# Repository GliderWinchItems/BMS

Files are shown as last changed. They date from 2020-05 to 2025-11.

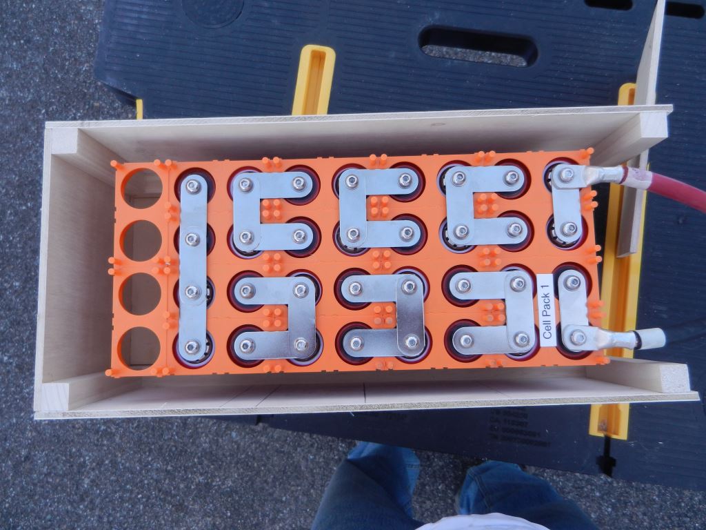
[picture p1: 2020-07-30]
docs/pictures/battery-module.JPG

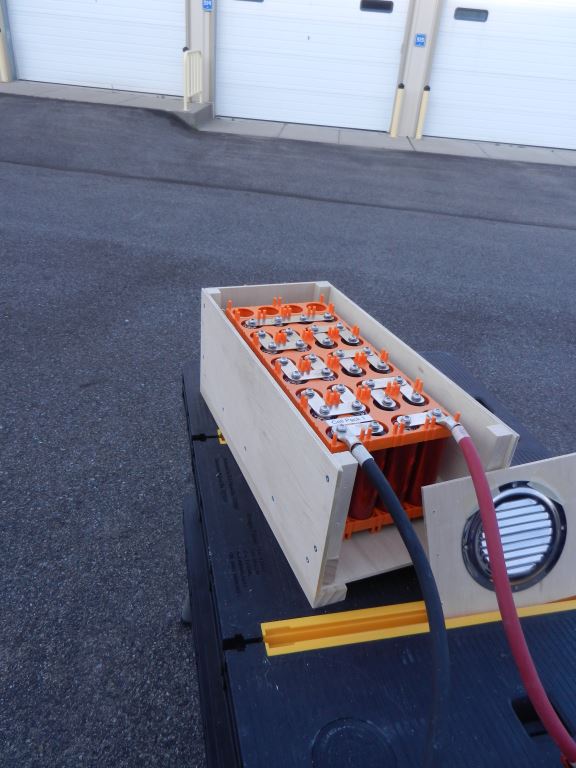
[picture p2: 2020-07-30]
docs/pictures/battery-module1.JPG

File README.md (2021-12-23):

# BMS
Battery Management System

This repo has directories for three BMS designs.

The original plan used a LTC6813-1 (18 cells), but when it came time to order the pcb, the part was no longer available. The TI BQ76952 (16 cells) was then found to be available in a few months so that design was completed.
The testing of the first prototype with the BQA76952 turned up some unexplained failures, plus additional BQ76952 parts would not be available for approximately one year. 

The ADBMS1818 chip became available and samples were to be shipped in a few weeks, and additional parts available from Mouser in several months. This gave rise to the second design. The delivery schedule changed  and it would be about one year for samples and additional parts. This gave rise to a design based on the MAX14952.
The designs differ mainly in the BMS chip. The same processor, STM32L431RxT6, is used and the features are  nearly identical in the three designs, e.g. the trickle charger, CAN, and fan interfaces, etc. Much of the documentation for the BQ76952 board applies to all three designs.

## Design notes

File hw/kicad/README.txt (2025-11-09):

#README.txt
# 11/08/25

# Step 1: Convert eagle v4 format to v6.5
#
# The files in kicad are the result of loading the original eagle v4 files into
# eagle 6.5, then saving the .sch & .brd files.

# Step 2: Convert eagle 6.5 format to kicad.
#
# The eagle 6.5 files are imported into kicad and the resulting kicad format files are 
# saved.

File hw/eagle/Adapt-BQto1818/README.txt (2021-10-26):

README.txt

10/25/2021

../GliderWinchItems/BMS/hw/eagle/Adapt-BQto1818/A18-BQ

This wires the ribbon/IDC for the 18 cell battery module
layout to the 16 cell keyed header on the bmsbmsBQ pcb.

A female 2x10 header (non-keyed) mounts on the left 
side on the bottom and mates with the BQ pcb.

A male 2x10 keyed header mounts on the top and
receives the ribbon IDC connector.

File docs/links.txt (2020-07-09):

http://vi.raptor.ebaydesc.com/ws/eBayISAPI.dll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

https://www.amazon.com/Pc-Accessories-Connectors-Sockets-10P-20cm-2PK/dp/B01DP13EDA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

http://www.interfacebus.com/Can_Bus_Connector_Pinout.html

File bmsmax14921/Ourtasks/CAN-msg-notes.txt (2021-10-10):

CAN-msg-notes.txt

A. EMC command msgs causing all modules to respond

byte 0:
  0 = send status (payload same as heartbeat)
  1 = capture cell voltage
  2 = send all cell voltages
  3 = send all temperatures
  ...

 B. Heartbeat

byte 0:  battery_status
byte 1:  fet_status
byte 2-4: cell discharge fets

C. Cell voltages

CAN ID maps to battery module

Payload carries cell voltates
byte [0]: command code
byte [1] Cell numbers
   bits[7:3]cell number 'n' (n > 0)
   bits[2:0]cell number payload readings (1-3)
     0 = no cell
byte [2-3] 16b voltage cell (n)
byte [4-5] 16b voltage cell (n+1)
byte [6-7] 16b voltage cell (n+2)

Cell voltage--
0 = not availble, open wire
65535 (0xFFFF) = reserved code for error, open wire, ...
0 < unsigned in 100 uV steps < 65535

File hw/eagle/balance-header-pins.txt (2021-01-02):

balance-header-pins.txt
01/01/2021

JP1 (Outside)
1  nc
2  C13
3  C9
4  C5
5  C1
6  C16
7  C12
8  C8
9  C4
10 C0

JP2 (Inside)
1  GND
2  C15
3  C11
4  C7
5  C8
6  nc
7  C14
8  C10
9  C6
10 C2

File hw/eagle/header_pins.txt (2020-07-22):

header_pin.txt

Header pins assignments for board pair:
repo GliderWinchItems/BMS
 directories 
hw/eagle/bmschgrR
hw/eagle/bmsbmsR

Battery cable
BSMCHGR: 2x10 KEYED TOPSIDE
 t = top group
 b = bottom group
pin func . color
01  GND    black
02  C2   t white
03  C4   t grey
04  C6   t purple
05  C8   t blue
06  C10  t green
07  C12  t yellow
08  C14  t orange
09  C16  t red
10  C18  t brown
11  C1   b black
12  C3   b white
13  C5   b grey
14  C7   b purple
15  C9   b blue
16  C11  b green
17  C13  b yellow
18  C15  b orange
19  C17  b red
20  gnd    brown

BETWEEN BOARDS: 1x30 top edge (of eagle layout view)
BMSCHGR: JP1  BOTTOMSIDE  BMSBMS: JP1 TOPSIDE
Pin #1 located a left side (of eagle layout view)
01  +15v isolated dc-dc output
02  +7v  15v switched to 7v
03  PA12 CAN TX
04  PA11 CAN RX
05  PA8  TIM1CH1   FAN FET gate drive 
06  PC11 I/O       LED1  
07  PC10 I/O       LED2
08  PB8  TIM4CH1   MCP1416-IN (HV fet driver input)
09  PA9  USART1-TX FTDI TX
10  PA10 USART1-RX FTDI RX
11  PC0  IN-10     15v divided for ADC
12  PC1  IN-11     Battery divided for ADC
13  C18   C'n' = LTC6813-1 cell voltage sense pin
14  S18   S'n' = LTC6813-1 cell discharge drive pin
15  C17
16  S17
17  C16
18  S16
19  C15
20  S15
21  C14
22  S14
23  C13
24  S13
25  C12
26  S12
27  C11
28  S11
29  C10
30  S10

BETWEEN BOARDS: 1x30 bottom edge (of eagle layout view)
BMSCHGR: JP2 BOTTOMSIDE   BMSBMS: JP2 TOPSIDE
Pin #1 located at left side (of eagle layout view)
01  C9
02  S9
03  C8
04  S8
05  C7
06  S7
07  C6
08  S6
09  C5
10  S5
11  C4
12  S4
13  C3
14  S3
15  C2
16  S2
17  C1
18  S1
19  GND
20  G5  Hall-effect signal ['G'n' = LTC6813-1 gpio pin (aux adc)]
21  G4  spare
22  G3  spare
23  G2  spare
24  VREG - 5V LTC6813 regulator output
25  +5v  - 5V LM78L05 bmsbms board output
26  MASTTER-RESET-PROC - Isolated CAN cable reset
27  PB1 - TIM3CH4  H11L1 opto-isolator 12v fan tach
28  PA14  JTCK SWDIO
29  PA13  JTMS SWCLK
30  GND

I2C bus (e.g. LCD or bi-color LED)
BMSBMS JP3: UNDERSIDE: 1X4
1 GND
2 +5V
3 PB11  I2C2-SDA
4 PB10  I2C2-SCL

Thermistors
BMSCHGR: JP10: 2x3 TOPSIDE
1 Thermistor #3:bms gpio G4
2 GND
3 Thermistor #2:bms gpio G3
4 GND
5 Thermistor #1:bms gpio G2
6 GND

FTDI connector
BMSCHGR: JP4: 1x6 TOPSIDE
1 GND
2 NC
3 NC
4 UART-RX
5 UART-TX
6 NC

SWD debugger
BMSCHGR: JP5: 1x4 TOPSIDE
1 GND
2 SWCLK
3 SWDIO
4 NC (3.3v)

FAN Drive
BMSCHGR: JP6: 1x2 TOPSIDE
1 Gnd (black)
2 +12v (red)
3 Drive signal (FET Q1 drain, w flyback diode) (blue)
4 Fan tach signal (yellow)

Hall-effect sensor
BMSCHGR: JP7: 1x3 TOPSIDE
1 GND
2 HE signal:bms gpio G5
3 +5v

Bi-color LED drive
BMSCHGR: JP8: 1x3 TOPSIDE
1 +5v
2 FET Q2 Drain resistor: LED1 (also on-board LED)
3 FET Q3 Drain resistor: LED2

External subboard possibility
BMSBMS: JP10: 1x4 BOTTOMSIDE
1 GND
2 PB2 PB0
3 PC4 (vis resistor) (ADC12-IN14)
4 5V

Pushbutton wake-up (closure pulls up)
BMSBMS: JP11
1 10K to gnd
2 VCC

External battery dump provision
BMSBMS: JP4
1 gnd
2 FET drain, ...
3 FET source, ...
4 +15V

THRU-HOLE SOLDER PADs (0.028" hole)
BMSBMS
U$1  LTC6813 GPIO6 
U$8  LTC6813 GPIO7
U$9  LTC6813 GPIO8
U$10 LTC6813 GPIO9

U$13 BATT-SELECT: P-FET source, select Battery tap
U$14 CL4: Battery tap - four cells
U$15 CL3: Battery tap - three cells

U$19 PB12 SPI2-NSS
U$20 PB13 SPI2-SCK
U$21 PB14 SPI2-MISO
U$22 PB15 SPI2-MOSI

U$23 PB7  I2C1 SDA:TIM4CH2

U$17 PB6 CAN2-TX:TIM4CH1
U$18 PB5 CAN2-RX:TIM3CH2

U$27 PC8  SDIO-D0:TIM3CH3
U$24 PC9  SDIO-D1:TIM3CH4:TIM8CH4
BOTTOM HEADER 7 PC10 LED2: SDIO-D2:USART3-TX
BOTTOM HEADER 6 PC11 LED1: SDIO-D3:USART3-RX:UART4-TX
U$25 PC12 SDIO-CK: UART5-TX
U$26 PD2  SDIO-CMD:UART5-RX

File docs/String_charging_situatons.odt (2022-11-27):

For the string there the following situations, but only if not cell on the string has fallen below the minimum voltage, e.g. 2.0v for LFE type cells--

1. Full power charging

Conditions:

- All modules have no cells at max voltage (e.g. after a launch).

2. Use dump, and heater to speed limited current charging

Conditions;

- One or more modules that have all cells at max

AND

- Modules that do not have all cells at max, have none of their cells at max.

3. Cell discharge resistors limit maximum charge rate.

Conditions:

- One of more modules that do not have all cells at max, have one or more cells at max.

Situation 1: Full power charging--

This would occur after a launch. Until the first cell reaches max the charger can be set for maximum power.

Situation 2: Charging limited by dump, heater, and discharge resistors

This situation could occur when a module is added to a string where the other modules are fully charged, and the new module has no cells at max. If charger can, averagely, charge at the rate set by the discharge current. The heater, dump resistor, and FET/discharge resistors serve to (averagely) dissipate the charger current in those modules at max. When one or more of the cells in the module being charged reaches max the situation changes to #3.

Situation 3: FET/discharge resistors limit charging currents

When a module has one or more cells at max, but not all cells are at max, then the charging, (trickle charger, plus string charger), averagely, has to be equal or less than the discharge current of the FET/discharge resistors.

The discharge resistors in '1818 boards are 30 ohms. The discharge FETs have a resistor of about 1/2 ohm. The ribbon cable & connector resistance adds something on the order 1/2-1 ohm. So with a threshold voltage of 3.65v and 31 ohms the current is about 117 ma. The string charger then has to be charging, averagely, at equal or less than 117 ma.

There is no need for having the string charger limited to the discharge resistor current since it is the average that matters. Within limits of course it doesn't matter what current the string charger supplies. One limit is that the duration of the charger on time between voltage checks times the current, i.e. charge added, doesn't push cells near the high limit too high which have been discharging with the discharge resistor. The duration gets onto the issue with ramping up of the charger, and how often the charging is turned off and cell readings taken. When a cell reaches the max voltage the discharge fet is turned on and the cell then begins dropping; when it hits a small increment below max, the discharge fet is turned off and the cell charges back up. There is a small voltage dithering around max until all cells have hit the max at which time the charging is complete, and a timed discharge is done to put the cells on the voltage plateau. Before all the cells hit max the cells still being brought up are dealing with current*time so it doesn't matter if the current is high and the duration short, or the current low and the duration long. If the string charger current is equal to the discharge resistor current the charging can be continuous, but that doesn't change the amount of time required to bring those cells up to max as the average charging level is still set by the discharge resistor current. The time * duration of the discharge resistors for the cells around max is what controls.

Dump resistor control

The dump resistor has two uses. One is to discharge the cells down to the plateau voltage once all the cells have reached max. The other is add discharge current to all the cells when situation #2 above is in effect. This allows a larger charger current to bring up a low module.

Heater resistor control

The resistor is has two uses. One is to heat the module when it is too cold. The other is to increase the charger current for situation #2.

Discharge resistor control

The cell FETs control the discharge resistors, and is the only way the charge on individual cells can be controlled. The FETs can turn on/off about 117 ma of cell discharge current. The trickle charger, for 3.65v and 18 cells, produces about 80 ma. The string charger can produce 0 – about 8a and can be set via CAN msgs.

Page 2 String Charging strategies

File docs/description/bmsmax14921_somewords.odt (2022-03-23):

Here is some commentary on the program strategy and details.

(These are more notes & thoughts than a coherent description.)

ADC usage

The BMS chip has one analog buffered output, so one ADC channel must measure all the cells, thermistors, and top-of-stack voltages. Other ADC channels are used to measure pcb points, e.g. the isolated dc-dc module voltage, processor internal voltage reference and internal temperature sensor.

The measurement speed for the BMS readout is critical since during the readout the voltages for the cells are being held by 1u capacitors and due to leakage the voltage has a “slump”. While the measurement speed for the other ADC channels is not as critical a large number of readings is needed for averaging the internal voltage reference. To deal with the timing issue the program strategy uses to two ADC modes. One for BMS readout and the other for the other ADC channels.

The cell readings are not needed continuously, and also there is a sampling time requirement. The flying capacitors are connected to the cell inputs with 3K resistors so there is a time constant issue with the recharging. The general plan is that the fastest rate for taking readings with be 16 per sec. This leaves 62.5 ms minus the readout duration for recharging.

ADCTask.c handles the control of the ADC readouts. After initialization the endless ‘for’ loop checks a FreeRTOS queue for a BMS readout request, without a wait. If the queue is empty it configures the ADC and DMA for reading the non-BMS ADC channels (if it is not already configured for this mode). The readout is started and a wait-for-notification is entered. When the ADC scans completes the DMA interrupt notifies the task, and the task calibrates and updates the channel readings and the ‘for’ loop repeats. This operation takes about 0.64 ms, which means any BMS readout has to wait no longer than 0.64 ms.

When a request for a BMS readout placed on the queue the ‘for’ loop checks a code on the request for the type of request.

If it the request is a ‘readbms’ the ADC is configured to read the single channel connected to the BMS buffer output. The readout requires a sequence. A command is sent; a delay for the command to “settle” e.g. the analog output buffer voltage, then an ADC conversion.

The commands are 24 bits (3 bytes) sent with SPI/DMA. The not-chip-select (/CS) line to the BMS controls the latching of the command bits to the BMS. When the SPI command transmission is started the line is low, enabling the BMS. When the SPI completes the sending of the 3 bytes the bits do not take effect until the /CS line is brought high. Bringing the /CS line high “latches” the bits into the BMS register. Following the latching of the new command, there is a settling time required for the mux to do the switching and the internal buffer to voltages to “settle.”

The first cycle of the sequence sets the /SMPL bit in the command which switches the flying capacitors from the cell inputs to ground reference. A delay of 50 us is required for this operation to “settle”. Therefore, the sequence is for ADCTask to begin the readout sequence by sending this first command. The SPI interrupt raises the /CS line thus latching the command and a 50 us time delay is set for the timer. The timer interrupt prepares the next command (cell #2), and starts the ADC conversions for the command currently latched in the BMS, i.e. cell #1.

Sequence--

1. ADCTask, upon completion of the non-BMS ADC channel reads checks the queue and finds a request.

2. The request is a pointer to a struct ADCREADREQ in the requester’s task. Assuming the request code, ‘reqcode’, is REQ_READBMS a call to ‘adcspi_readbms’ is made which starts the sequence. It returns when the sequence is complete.

3. Send command to switch flying caps to ground reference.

‘readbms’ starts sequence:

- reconfigure the ADC registers for a scan of 1, oversample 32, right shift 1.

- Set the state for TIM15 interrupt handling to ‘TIMSTATE_SMPL.

- Set the /CS line low to enable the MAX14921 (BMS) spi.

- Set TIM15 for a delay slightly longer than the sending of the SPI 3 bytes.

- Set the SPI DMA tx channel to send 3 bytes, and enable it, thus starting the sending of the SPI.

- Wait for a notification that the entire sequence has completed.

4. Start time delay for flying caps ground references.

TIM15 ‘TIMSTATE_SMPL’:

- Set the /CS line high, latching the command

- Set the TIM15 delay to ~50us for the flying caps to be brought to ground reference.

- Set the next TIM15 interrupt handling to TIMSTATE_2.

5. Start sending command for first cell selection.

TIM15 TIMSTATE_2:

- Set /CS low for sending next command

- Prepare command for selecting cell #1 (spiidx = 0)

- Set TIM15 delay for SPI delay.

- Set Sets the next TIM15 interrupt handling to TIMSTATE_3.

6. Settling time for first cell selection command

TIM15 TIMSTATE_3:

- Set /CS high to latch cell #1 selection selection

- Set TIM15 delay for 5 us settling time.

- Set TIM15 interrupt handling to TIMSTATE_N.

7. Start conversions, and sending of next cell selection.

TIM15 TIMSTATE_N:

- Set /CS low for to enable sending next SPI

- Start ADC conversions

- Start SPI sending next command.

- No timer setting. Wait for ADC interrupt.

8. ADC interrupt

- Set /CS high latching next command sent-and-waiting.

- Store ADC result in ‘raw’ array using ‘adcidx’ index.

- Advance index and

- if equal 20

- - notify task sequence completed

- - Set TIM15 interrupt handling to TIMSTATE_IDLE

– if less the 20,

- - if equal 19

Set TIM15 delay to 60us.

else

Set TIM15 delay to 5 us.

- Set TIM15 interrupt handling to TIMSTATE_N.

9. Step 7 above repeats until the ADC interrupt stores the last, top-of-stack, 20th reading. Note that a command is sent with the spiidx equal 20, is is the 21st command. This command sets the /SMPL bit to zero. The discharge FET bits are set according to the request.

Request queue pointer points to the following struct with codes--

/* Request Codes for ADCTask services. */

#define REQ_BOGUS 0 // Trap mistakes

#define REQ_READBMS 1 // Read MAX1921 cells, thermistor, Top-of-stack

#define REQ_CALIB 2 // Execute a self-calib (MAX14921 Aout offset) cycle

#define REQ_OPENCELL 3 // Do an open cell wire test

#define REQ_LOWPOWER 4 // Place MAX14921 into low power mode.

#define REQ_SETFETS 5 // Set cell discharge FETs

/* Queue is a pointer to the following for requesting a "service". */

struct ADCREADREQ

{

osThreadId taskhandle; // Requesting task's handle

BaseType_t tasknote; // Requesting task's notification bit

float* taskdata; // Requesting task's pointer to buffer to receive data

uint16_t cellbits; // Depends on command: FET to set; Open cell wires

uint8_t updn; // see above 'struct ADCSPIALL'

uint8_t reqcode; // Code for service requested

uint8_t noverlap; // see above

uint8_t readbmsfets;// Code for handline discharge fets during read:

// 0 = clear fets; fets remain clear after read sequence

// 1 = fet setting remains in place during read sequence

// 2 = new fet setting (from cellbits) applied after read sequence

// 3 = save fet setting; clear for read; restore after read

};

After placing the request on the queue it can use a wait for notification that the request has been completed.

‘tasknote’ supplies the word/bit to identify who made the notification.

‘taskdata’ supplies a pointer to an array of floats to receive the 20 BMS readings (16 cells, three thermistors, one top-of-stack).

‘cellbits’ (uint16_t) has bits to for setting each of the discharge fets. 1 sets turns the fet on.

‘updn’ controls the cell readout sequence. 0 = cell #16 read first, 1 = cell #1 read first. High numbered cells have higher leakage than lower cells so reading the high cells first is supposed to reduce the effect of leakage (“slump”) discharging the capacitors while readings are being made.

‘reqcode’ code for BMS function to be executed.

‘noverlap’ the spi is ovelapped with the adc conversions. Not overlapping might reduce ADC noise but at the expense of a longer readout duration and greater slump. Currently (3/17/2022) this is not implemented.

‘readbmsfets’ : Options for setting/resetting the discharge fets before & after the readbms sequence. Most likely the readbms sequence will be done with the fets (and chargers) off. Readout with a fet on is one scheme for detecting an open cell wire than using the DIAG 10 ua discharge approach.

The thermistor and top-of-stack readouts do not involve measuring voltages on capacitors so the issue of “slump” error is not involved. The time delay for settling of the analog output buffer is still present, and the top-of-stack requires a 60 us delay.

The timer interrupt handler prepares the command to be sent by the SPI. A ‘switch’ based on an index is used to deal with cells, thermistors, top-of-stack, and end of requested readout. The commands for selecting the individual cells is done via a table lookup. An option in the queued readout request can select for the cell readouts to be high-to-low cell numbers, or low-to-high. The high numbered cells are supposed to have a higher leakage current, hence faster slump rate, than the low cells, and the datasheet recommends high-to-low. The option allows the reverse readout so that comparisons can be made. (Similarly, the option for overlap/not-overlap can be used to test out which provides the best accuracy.)

The ADC conversions are done using the over-sampling provision in the STM32L431. A channel is repeatedly converted and the result added to a register. At the end of the set number of conversions the register with the accumulated readings is automatically right shifted according a setting in a configuration register. The selection for the ADC channels scans is an oversampling of 32 followed by a right shift of 1, and the BMS readout is 16 with no right shift.

The ADC oversampling is set so that it takes longer than the duration required for the SPI sending of the 24b command plus settle-duration.

It is important that the interrupt priority of the TIM15, and ADC all be at the same level. Since the interrupt handling of these two interact, having the same priority avoids an intractable situation whereby one a higher priority interrupt occurs in the middle of the execution of the lower priority interrupt.

TIM15 shares the interrupt vector with TIM1. TIM1 is used for the trickle charger PWM control, along with the two comparators that break TIM1 to keep currents and voltages within limits. No interrupts are used with TIM1.

TIM2 is used with the FanTask, and the fan control. It is a 32b timer, however the PWM frame rate is set for 25 Khz so it is not useful for using one of its timers for the BMS time delays. This leaves TIM15 for the time delays, however it is only 16b. For most of the time delays that is sufficient, i.e. at 16 MHz system clock the turnover duration is 4.096 ms. However, the the self-calibration command for the BMS requires approximately 8 ms. To handle this single long delay situation, the time delay for completion of the self-calibration command is simply two output capture turnovers, starting at the time the SPI command completed (and the /CS line raised to latch the command).

Yet to be tested (3/11/202) the BMS commands for readout require 5 us following the latching of the command. From the instant of raising of the /CS line to the start of the TIM15 output capture there are instructions being executed, so adding 5 us of timer ticks (i.e. at 16 Mhz system clock, 16 machine cycles per us) will result in a somewhat longer timer duration from the time the i/o line goes from low-to-high and until timer interrupt takes place, and executes up to the point where the ADC conversion start. The amount of time will be short—maybe less than 2 us?--so that is not significant, i.e. for 16 cells, 32 us extending of a possible 316.8 us minimum. The datasheet mentions that with 1 u capacitors a readout of less than 1 ms for less than 1 mv slump error.

Ideal for timing the short (5 us) delay would be for the rising edge of the /CS i/o pin to trigger a timer input capture. The subsequent interrupt processing could check that time of capture plus 5 us and use that for adding any additional delay. If the delay had already expired the next timer step could proceed.

Next best would be to have the instruction following the one setting the /CS i/o pin trigger an input capture. That would add a few machine cycles. One problem is that if the rtos timer interrupt, which is the only higher priority interrupt, interrupted it would add more delay. This could be overcome by reading the system time before and after, but adds to the complication.

(3/20/2022)

Timing. Using DTWTIME to save the system timer the number of machine cycles was measured between various points. Adding 16 to the current TIM15 counter (CNT) resulted in about 90 cycles from ADC interrupt routine entry and the TIM15 switch statement. With the oversampling set to 32 (right shift 1) the sixteen cell measurements was taking about 500 machine cycles. The overall measurement (cells, thermistors, top-of-stack) was 0.8 ms. With the oversampling set to 64 (right shift 2) it was 1.3 ms.

CanCommTask.c is the primary source of requests for a BMS readout. This task checks on incoming CAN msgs and when there is a request for a readout, e.g. the EMC, it places a pointer to a struct ADCREADREQ on the queue for ADCTask. The struct holds the options, pointers, notification word, etc. ADCTask executes the request and notifies the task making the request (using the data in the struct). With the new data CanCommTask sends the CAN msgs with the readings. The rate for taking readings is therefore under control of the EMC, or “whoever” sends the CAN msg for the request.

When there are no CAN msgs making a request, the endless ‘for’ loop in CanCommTask times out; makes readout request, and sends out the results as a heartbeat. The heartbeat rate is determined by the timeout count, which is a parameter.

Another readout requester is likely to be ‘main.c’ where ‘defaultTask’ makes a request for monitoring/debugging.

The ‘readbms’ turns off the discharge FETs if they were on since the first step of setting the /SMPL bit high (set flying caps to ground reference) has the cell discharge FET bits off. Maybe this should be changed to allow these bits to remain on. The option could be in the request struct that is passed to ADCTask.c (via the pointer in the queue).

(3/21/2022)

The BMS readout is currently controlled from the CAN communication task. CANTask waits for a CAN msg that needs a BMS readout, and upon receiving that places a request on a queue to the ADCTask. ADCtask checks the queue after each readout of the non-bms ADC channels (e.g. dc-dc converter voltage, trickle charger high voltage, etc.). When there is a queued request ADCTask switches the ADC registers to change the mode and does the BMS readout sequence. It notifies the waiting CAN comm task when the readout is complete. (The MAX14921 is somewhat faster than the ADBMS1818 this respect.) I think this sw strategy is solid for the BMS readout. BTW, other tasks can request a BMS readout, as well as the other functions, e.g. self-calibration, open wire

For balancing my thinking, as of Monday afternoon, is that balancing goes on continuously as long as the processor is running off of 12v CAN bus power. What I mean by balancing--

- If all cells are above the target voltage:

turn on the dump resistor and all discharge fets.

turn off trickle charger and external module charger control fet

- If any cell is below the minimum turn:

turn off dump resistor and all discharge fets.

turn off external module charger fet.

turn on the trickle charger at the low rate.

- If one or more cells are at or above target:

turn on selected discharge fets.

turn off trickle charger and external module charger control fet

- If all cells are below target, and above minimum:

turn on trickle charger.

With this scheme there is always balancing going on, unlike the BQ where there is usually deadzone specified where it goes quiet when all the cells are within some delta. With this scheme and with time, the module will end up with all the cells oscillating a tiny amount around the target voltage. This raises the issue of the target voltage. We have been thinking of two voltages. One being the storage voltage, and other a voltage that is safely below max, but still on the high slope end of the charge curve. Given the flat discharge curve for the LFP cells the discharge-fo-storage might better be a time & current integration, starting from a full charge state.

There is also the charging/discharge current issue when balancing. The cell readout is done with the trickle charger and discharge fets all off. With a string charger it doesn't know about the charge current unless the EMC sends it a CAN msg. The on-board current sense op-amp could be used. However, it might not be a problem to ignore a string charger. The EMC is supposed to turn off the string charger before sending a command to read the cells, and before turning it back on it would have to check that all the readings received.

Page 7 bmsmax14921.c – some words of explanation 03/11/2022

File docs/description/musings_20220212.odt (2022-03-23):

Page 1 02/12/2022 Thoughts on Balancing, EMC, Log readout

Here is some thinking out loud, i.e. the clatter of the keyboard. I started to pick up with the sw for the BQ board where I left off when the last BQ blow-up took place. Then there was the push to get the pcbs into fab. The current sw logic on the BQ board needs revision, though it currently does balancing OK. Most of the issues apply to '14921 (and '1818).Here is some thinking out loud, i.e. the clatter of the keyboard. I started to pick up with the software (sw) for the BQ board where I left off when the last chip blow-up took place. The work was set aside when there was the push to get the MAX14921 pcbs into fab. The current sw logic on the BQ board needs revision, though it currently does balancing OK. Most of the issues apply to the MAX14921 (and ADBMS1818).

The present issue I'm wrestling with is the balancing and CAN readout. Digging into the cell readout over CAN raised the issue.

When should the BMS be balancing--

There is no point to attempt balancing when the module is under heavy load. Any differences in inter-cell connection link resistances would enter in the cell voltage readouts and distort the balancing. To know if the module is under heavy load the current reading from the contactor CAN msgs could be used. The "below ground" current sense resistance on the module would be another way to measure current and it would make the module independent of the contactor CAN msgs. Something to think about.

Another issue with this is the idle time needed for the discharge fets & resistors to be draining cells. During cell readout the discharging of the FETs, dump resistor, and heater, are disabled. The time required for readout robs from the time for discharge. The BQ has a slow cycle mode that gets the readout/idle-time up in the 80% realm. If cell voltage readouts are needed 16 times per sec, the BQ has to be running readouts continuously. Each pass through the cells takes about 60 ms, and three passes are needed to pick up the additional items, such as thermistors. If a msg from the EMC requests a reading, the current array of cell voltages would be sent. Some cells might have just been read and others would be around 60 ms old. To be able to do balancing and timely readouts the sw logic would have to switch between readout and balance modes based on some criteria.

For the '14921 I'm expecting that the readout will take less than 3 ms. That leaves a lot of time for cell balancing with EMC requests coming in at 16 per sec. The issue of balancing under load current remains, so trying to do balancing under load, at least heavy load, should not be done.

EMC polling rate--

There is no need to be reading and logging cell voltages at 16 per sec unless the battery string is under load. When not under load, once every two or three secs seems fast enough. When the heavy load stops there is a cell voltage recovery which we might want to capture. I notice that with my small LiPo proxy pack. Two or three secs between readings is fast enough. Maybe it could be even slower.

With regard to balancing, the cell voltage recovery after discharge can result in charging the cell a small amount above the target voltage. When the discharge FET is turned off and the cell reading taken immediately the cell will be low. The continuing recovery then adds to the charging so that at the end of the charging cycle the cell is now somewhat above the target voltage. The small cells in the proxy pack, 250 mah, magnify the effect, so with a 16 ah (2P) cell the effect would be expected to be much smaller.

One approach to the polling rate is to have the EMC send BMS cell readout requests at 16 per sec when the MC state is in any state other than SAFE mode. When not in SAFE mode the polling rate would be slow. That would have to be accompanied with a timeout for missing state msgs, so that the EMC would drop into "slow mode" whenever MC state msgs were missed for more than 'x' secs.

There might be other polling rates, e.g. discharge-to-target for discharging for long-term storage, so the EMC polling strategy might be contingent on a number of different system states.

BMS logic--

The loop waits for an EMC msg for 'x' secs. When it times out, it sends a heartbeat that is a status msg followed by a complete set of cell voltage readings (six CAN msgs). The 3 bit sequence number for the group of msgs would be whatever is current.

When an EMC readout msg is received, or a heartbeat timeout occurs, the charger is disabled; readings taken; and, the CAN msgs sent. The charger is disabled whenever readings are being taken, or the load current is over a threshold, or a dump state is on; otherwise, it is enabled. A dump state would be set by the EMC sending a msg for that module to turn on the dump fet for module balancing. This would be a timeout protected state so the dump state has to be renewed periodically. Having the charger running would be counterproductive. This raises the issue of, when does the EMC do balancing and charging?

When the CAN power is removed, the BMS runs on battery long enough to assure the BMS chip is placed in shutdown mode. The charger cannot charge during this shutdown sequence since it is powered from the dc-dc converter, which obviously is not powered. CAN msgs are not possible since the system side of the CAN driver depends on the 12v power. The battery side would still be getting 3.3v when the processor is running on battery.

EMC balancing/charging--

When does the EMC do module level balancing?

To balance, it needs to be able to turn the string charger on/off. If the string charger is CAN bus controlled, the EMC will be receiving msgs, or polling and receiving msgs, from the string charger which will show that it is alive. If the CAN msgs are present but the charger doesn't charge, e.g. the string charger is not connected to the string, there shouldn't be a problem with the logic; the string voltage would not increase. Dumping would discharge all the modules down to the lowest module's voltage, or the lowest module voltage cutoff threshold.

This might not be desirable as it could mean discharging all but one weak module, i.e. a chase to the bottom. A lowest discharge voltage cut-off would be a way to prevent this. The same principle could also be applied to cells at the module level balancing. Net, don’t run the good cells all the way down to the level of a bad cell.

If the EMC checks for the string charger show that it has failed, i.e. no signs of being able to charge, then the EMC cannot do module level balancing. However, left long enough on their own, the trickle chargers on the BMS boards will eventually have all the cells balanced and at full charge. With the trickle charge rate in the 80-110 ma rate, it might take a long time, but module level balancing would not be needed.

The EMC would turn on the string charger whenever no cell on the string was at max, and of course the charger is alive and well. Before sending a cell readout command it would turn off the charger. The charger would be re-enabled when all the CAN msgs have been received. A timeout would be needed to cover the case of missing CAN msgs. Retrying 'n' times would be done before showing an error.

When the first cell in a string reaches max the string charger is turned off. Any module that has all of its cells within 'x' of max would be given a command to turn on the dump fet.

Cell logging and readout--

Readout of logged mgs over the CAN bus poses problems. If the original CAN msg is used for a logged msg, then the bus traffic is indistinguishable from original BMS msgs. Worse, the EMC would be putting out CAN msgs with the same CAN id as the BMS units. Also, if it is simply a replay, the EMC commands would be replayed and they would trigger BMS responses. If the CAN bus is used to retrieve logged BMS data, then the CAN msgs would need to be repackaged with different CAN ids. This would include contactor CAN msgs.

In general any logged CAN msg sent over the CAN bus would require a new CAN id, or repackaging in CAN msgs with CAN IDs that “say” this CAN msg(s) contains logged CAN msgs. To send a logged CAN msg, it would be encapsulated in one or more of the CAN msgs with this log CAN id. Sequence numbers would be required since several encapsulated CAN msgs would be required to convey a single logged CAN msg. A binary packing scheme would help. All rather messy.

Assuming a RPi is used for the logging, BMS data could be accessed via wi-fi, or ethernet. I don't think the system units on the CAN bus have any need for logged data. The EMC might be the exception but it has the logged data and does not have to use CAN to access it. The other units on the CAN bus do their thing in realtime. It is the HC where the log data would be used.

Logging of new data will also be taking place when readout will be needed, e.g. at the end of a launch the charger(s) would be going full tilt to recharge between launches. Given the volume of log data for the battery system, it suggests that there be a single log file, and there would be a small file associated with it that logs the EMC log file position, date/time, and launch MC state when the MC state changes, or some other significant change is noted. The start/end positions in the log file can then be directly accessed by obtaining the file position from this small file, and thus avoid a long search through the log file. In effect the small file is a specialized index file for accessing the sequential and long log file.

`

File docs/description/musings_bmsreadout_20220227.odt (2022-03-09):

This is a typing thoughts to clarify thinking on the ADC strategies for the ‘STM32L431 working with the MAX14921. The key issue is that the ‘L431 (and ‘L451 which is an alternative) only have one ADC. There are 11 ADC channels to be read, and of these, the one connected to the ‘14921 must be read 20 times in conjunction with time delays and commands sent via spi. This requires reconfiguration of the ADC between “BMS” and “ADC” readout sequences.

Overall organization

The overall organization has the task, ADCTask, waiting on a queue for requests for a readout. The queue element is a pointer to a struct held by the requester. The struct includes a code for the service requested (see ADCTask.h):

/* Request Codes for ADCTask services. */

#define REQ_BOGUS 0 // Trap mistakes

#define REQ_READBMS 1 // Read MAX1921 cells, thermistor, Top-of-stack

#define REQ_CALIB 2 // Execute a self-calib (MAX14921 Aout offset) cycle

#define REQ_OPENCELL 3 // Do an open cell wire test

#define REQ_LOWPOWER 4 // Place MAX14921 into low power mode.

#define REQ_SETFETS 5 // Set cell discharge FETs

When the wait on the queue exits, a sequence for executing the request is started and the task waits for the sequence to complete. Once started, the sequence is driven by interrupts of the spi, TIM2 OC4 timer, and ADC. The action taken by each interrupt depends on the state for that interrupt. The variables, spistate, timstate, and adcstate, direct the next steps taken for the interrupts. When the sequence completes a notification is made to ADCTask and it makes a notification to the requester’s task that the request is complete, and then goes back to waiting for the next queue item.

Rather than one huge file, various .c, .h files are involved. Most have ‘adc’ in the name, however the TIM2 timer is used by FanTask for fan control and the interrupt handling is done in FanTask. Output capture, OC4 was commandeered for timing the bms delays. When the OC4 interrupt flag is on the interrupt handler in FanTask calls a routine in spiadc.c where the interrupt handling for a delay timeout is handled.

BMS readout--

As of the date of this writing the coding for reading the BMS is in-place, but not debugged Here is the strategy along with reference to the routine files and subroutines.

A readout of the cell voltages starts with command that switches the flying capacitors from the cells to a ground reference, then via a mux that selects individual capacitors the cell voltage is measured. The cell voltage readout sequence is to send a spi command, wait for the results of the command to take place and voltages settle, then read the voltage on the output buffer (Aout). Since leakage is draining the capacitors while they are waiting to be measured, (referred to as “droop” in the datasheet), the speed of the cell readout is important. The datasheet says that with 1u caps and typical leakage the droop would be less than 1 mv.

To speed up the readout the spi command is overlapped with the ADC measurement. All commands are 24 bits, i.e. 3 bytes. With a 2 MHz spi clock the spi will take 12 us. The command takes effect when the /CS (not Chip Select) line changes from low to high. The code comments refers to this as “latching” the command. At that point in time a delay is required to allow the mux to select and buffer op-amp voltage to settle. The datasheet calls for 5 us. Thus each cell selection will take 17 us (12 + 5) for each cell. While the spi is sending a command the ADC can be taking measurements using the oversampling feature in the ‘L431. The oversampling sums each conversion into a 24 bit register, and at the end of the number of samples set, e.g. 16, 32, etc., the register can be right-shifted when the number of samples is greater than 16.

The amount of time for each ADC conversion is determined by the ADC clock speed, and number of cycles specified for the sampling. The minimum number of sampling cycles is set by input impedance to the ADC channel. The bms output buffer has an output impedance of about 200 ohms. A resistor divider drops this so that a voltage of about 4.0v will saturate the ADC with a Vdd of about 3.3v. An ADC clock speed of 52 MHz along with the divider impedance requires a sampling duration somewhat greater than the option for 12.5 cycles, so 24.5 cycles is selected. The fixed duration portion of the conversion is 12.5 cycles, so 37 cycles are required for one conversion. If 32 is selected for oversampling (and one bit right-shift) each ADC measurement cycle will take 22.8 us. Since 5 us is required from the time /CS line is raised, which switches the mux to the next cell, until the ADC measurement can be begin, each cell measurement requires 27.8 us (22.8 + 5). The total for 16 cells is therefore 444.3 us. Which is well within the 1 ms for 1 mv droop, and the shorter time duration might allow improvement over the 1 mv droop. On the other hand noise might be introduced by the overlapping of the spi data and clock during the measurement. Not overlapping would increase the total time by 192 us, making the total 636.3 us.

Since the bits in the command do not take effect until the /CS line is raised the execution of the command in the bms is delayed until the ADC completes. In the foregoing, the selections have the spi completing before the ADC completes. If a slower spi clock is found to be needed, , or shorter oversampling selected, the ADC might complete before the spi command is completed. To handle both situations the interrupt for the spi checks if the ADC is busy. If it is busy the /CS line is left low (and sets a flag, though the flag is actually redundant as the port:bit for the /CS i/o shows whether it is high or low). When the ADC interrupt takes place it stores the ADC reading, and checks the flag. If the flag is set, the ADC raises the /CS line to latch the cell selection and triggers the 5 us timer delay. The time interrupt then starts the ADC conversion, prepares the next command, and starts the spi sending the next command. If the ADC was not busy when the spi command completed, i.e. the spi interrupt took place, the spi interrupt raises the /CS line and starts the 5 us timer delay. In both situations the timer interrupt is a signal to start the ADC conversions and start the spi for the next selection command.

The first cell and end of the cell readouts are special cases. Initially, the flying caps must be switched from cell inputs (where they are presumed to have been connected long enough to be fully charged to cell voltage) to ground reference. This command requires 50 us. Thus, the first step in a cycle of readouts is to send this command, and wait 50 us. After the delay, the command for connecting the caps to the output buffer are started. The spi “leads” the ADC so the spi completes sending the 16th command before the ADC completes the measurement of the 16th cell. The indices, spiidx, and adcidx, independently keep track of cell numbers (0 – 15).

For the spi the cell selection command is determined by a table lookup using the spiidx. The 24 bit command is specified with bit 0 being sent first. The cell selection command bit, and four bit cell selection are in reverse order of the STM32 convention. The simplest approach is to lookup the selection byte in a 16 byte table. Since the droop issue is more important for higher cell numbers than lower ones, the datasheet recommends measuring the high cells first. Since a comparison of high-to-low order versus low-to-order might be useful two lookup tables are provided. A flag (updn) allows the task requesting a readout to specify the direction of readout.

For the ADC, adcidx is used as an index to store readings.

In addition to the 16 cells with flying caps for cell readout, the ‘14921 has three thermistor inputs and one top-of-stack voltage divider that can be read. Command bits are used to connect these inputs to the output buffer. The speed to complete the readout is different than for the cell caps. There is no voltage droop since the buffer op-amp connects to a resistor divider, either the thermistors with pull-ups, or internal divider for the top-of-stack, rather than a capacitor hold a charge. For the thermistors the settling time delay for the buffer op-amp is still 5 us, however for the top-of-stack 60 us needed. The sequence for sending commands, timeouts, and ADC conversions remains the same as for the cell readouts, but following the last readout command the timeout is set to 60 us.

The ADC conversion data for the four additional readouts are stored the same way in the array. The preparation of the command codes and setting of the last time delay is set in the TIM2 interrupt handling.

During the readout of the 16 cells the /SMPL bit is high in each of the commands, thus holding the flying caps at ground reference level. When the thermistors and top-of-stack are readout, the /SMPL bit is set to zero and flying caps connect back to the cells for recharging.

When the 20 readouts are completed an array of calibrated readings are stored via the pointer contained in the requester’s struct (and a pointer to that struct was the item passed to ADCTask via the queue.

ADC readouts

ADC channels that are not connected to the MAX14921 buffer op-amp are readout differently. There are no spi commands or time delays required. For this read sequence the ADC is reconfigured to use the scan mode where the ADC channels are measured in sequence. Oversampling on each channel is used and the converted result stored automatically via DMA. The STM32CubeMX and following #define table in the following must match.

/* ADC reading sequence/array indices */

/* These indices -=>MUST<= match the hardware ADC scan sequence in STM32CubeMX. */

#define ADC1IDX_INTERNALVREF 0 // IN0 247.5 1 Internal voltage reference

#define ADC1IDX_INTERNALTEMP 1 // IN17 247.5 2 Internal temperature sensor

#define ADC1IDX_PA4_DC_DC 2 // IN9 247.5 3 Isolated DC-DC 15v supply

#define ADC1IDX_PA7_HV_DIV 3 // IN12 640.5 4 HV divider (FET side of diode)

#define ADC1IDX_PC1_BAT_CUR 4 // IN2 47.5 5 Battery current sense op-amp

#define ADC1IDX_PC4_THERMSP1 5 // IN13 247.5 6 Spare thermistor 1: 10K pullup

#define ADC1IDX_PC5_THERMSP2 6 // IN14 247.5 7 Spare thermistor 2: 10K pullup

#define ADC1IDX_PC3_OPA_OUT 7 // IN4 2.5 8 FET current sense 0.1 ohm:COMP2_INP

#define ADC1IDX_PA0_OPA_INP 8 // IN5 24.5 9 FET current sense RC 1.8K|0.1u

#define ADC1IDX_PA3_FET_CUR1 9 // IN8 2.5 10 OPA_OUT (PA0 amplified)

#define ADC1IDX_PC0_BMS 10 // IN1 24.5 11 Not included in adc dma scan

The last line in the above table is the ADC channel used with the BMS output buffer measurement. That channel is not read in the scan of the other ADC channels.

The right-most column in the above is the number of ADC cycles for sampling. Each conversion has an additional 12.5 cycles. The total for the 10 channels is 2102 ADC cycles. The Vref and Internal Temperature channels require a sampling duration greater than 4 and 5 us, respectively. The ADC clock frequency is set to 52 MHz via so that the 247.5 cycles comes in at about 5 us. With these settings the total time for one scan with no oversampling is 40.42 us. With oversampling of 16 the duration for one scan is 646.8 us.

Since it the BMS cell readings might be used in computations with load current readings the measurement of the BMS cell readings need to be made at the same time as the load current readings. The EMC sends a CAN msg that “everyone” receives and that triggers the initiation of their measurements. When that CAN msg is received the ADC channel readings may be in progress and the BMS readings cannot begin until ADC channel readings are complete or aborted. Aborting the channel readings is messy. If the ADC channel readings do not take long, then it is acceptable for the ADC channel readings to run to completion. That favor making the ADC channel reading scan very short. However, the voltage reference and some some extend internal die temperature sensor require many readings averaged to reduce the effect of noise and improve accuracy, so taking as many measurements as possible between BMS readout requests is wanted. To balance the tradeoff the timing needs to be addressed.

The ADBMS1818 BMS part has sigma-delta ADC and a measurement of all 18 cells plus two GPIOs (e.g. thermistor inputs) is spec’d at 3.1 to 3.5 ms, without the filtering mode. In the filtering mode the time required is in the 250 ms realm. Using 3.1-3.5 ms as a comparison, the ADC channel readout here only takes 0.6 ms, so one a one scan delay in starting the BMS readout is much better than the ADCBMS1818 will provide.

To utilize the time for ADC channel readings when a BMS cell readout is not in progress the strategy is for ADCTask.c to not wait for the queue with requests. Instead, the for (;;) loop checks if there is a request in the queue. If not, it starts a ADC channel readout and waits for a notification. When the ADC channel readout (using DMA) completes the DMA interrupt makes the notification. The readings are update, e.g. calibration, filtered, etc. The for (;;) repeats. This results in the ADC channel readings being taken at almost full speed, until a BMS cell readout appears in the queue.

The downside of the this strategy is that the interrupt rate is around 2 Khz, but is the price of avoiding a complicated arrangement where the ADC scan in progress is aborted by a BMS cell readout request and restarted without losing a lot of the ADC scan data. The strategy for that would be to configure the ADC channel readout to be in DMA circular mode which is used as a double buffering mode. The ADC runs through the scan continuously with the DMA storing conversions. At the ½ and end of the buffer the DMA gives interrupts, and the interrupt can be used to notify a task which half of the buffer is complete. Since the buffer can by ‘n’ scans long, the interrupt rate is low. The difficulty is recovery of data up to the point where the scan was aborted.

One way to deal with that would be to fill the ½ DMA buffer just processed with value that cannot be generated by the oversampling of the ADC. E.g., oversampling by 16 leaves four 16b numbers that cannot be generated by the ADC. One of these could be used to designate “no data”. Before resuming the ADC/DMA process the data DMA ½ buffer that was being filled when the abort took place would be processed up to the point where the “no data” code was encountered. Since the scheme is based on multiple scans in each DMA ½ buffer the data loss would be small. There may be some “corner cases” to be considered with respect to when interrupts take place. The advantage of the scheme is that the initiation of the BMS cell readout delay would be cut from about ½ ms to some tens of microseconds, the interrupt rate for ADC channel reading would be lowered, but the complication of code would be large.

Given that the ADBMS1818 will result in much larger delays, and does not use the processor ADC for cell readout, the above strategy to abort a continuous, circular buffer, DMA channel readout isn’t worth doing.

[Begin superseded thoughts section]

The readout of the ADC channels is not as time critical as the BMS cell channels. For the BMS channels the cell voltage under heavy load current will be wanted and the measurement of the cells should take place at the same, or very close, instant as the measurement of the load current. This complicates how the ADC is used.

The request for a reading is sent via a CAN msg from the EMC. All bms modules and the contactor receive this msg at the same time. The CAN interrupt notifies the Mailbox function which notifies the CANcomm task, which requests a reading. This all takes place in a matter of tens of micoseconds. The ADCTask then begins the BMS readout which takes approximately ½ ms, with the 16 cell readings being the first of the 20, which means the delay of the cell readings upon receipt of the CAN msg are delayed from very small to about 355 us. This is nearly ideal, however there is the situation where other requests are in progress when the CAN msg is received and the request will sit in the queue until the request in progress completes. There are some trade-offs in how to handle this.

The time for ADC scan of the 10 channels, with oversampling of 16, is 0.646 ms. If this ADC scan started at the instant the CAN msg was received the cell readouts would be delay 0.646 ms. This would be a worst-case. If that is satisfactory the ADC channel readout is simple. If that delay is unacceptable, then some scheme whereby the ADC channel readout is aborted and the BMS readout begun is needed.

Another factor is that the ADC channel readout contains the Vref and internal temperature sensors. The Vref is used to base the calibration of the BMS cell readouts. For best accuracy it also needs to be adjusted for die temperature which the internal temperature sensor provides. “In some ST app note” they talk about averaging a huge number of Vref readings taken over a number of minutes. This suggest that the ADC channel readings be taken continuously. With DMA in the circular buffer mode this is quite simple, however there is the complication of aborting the DMA readout, and resuming it after the the BMS readout (or other BMS request) is complete.

If this was done, there would be no ADC channel readout request as an array with the latest ADC channel readings would always have latest readings. These would be continuously updated except when interrupted by a BMS readout request. A BMS request would abort the current ADC scan and current ADC conversion is automatically discarded. Upon completion of the BMS request the ADC scan would be restarted from the beginning. This raises several issues with the ADC scan.

The ADC scan uses the DMA which avoids an interrupt upon the completion of each ADC channel. When the end of the ten channels completes there is an option of having the scan repeat automatically and the DMA continues to store. The DMA can double buffer and give an interrupt at when data stores at the ½ and end points. One problem is that if the buffer is just two scans long there is a DMA interrupt at the end of each scan of the 10 channels. This is every 646 us. If the DMA buffer is made longer the interrupt rate would be slower, but whenever the BMS request aborted the operation the ½ of the DMA buffer where was being stored requires some tricky handling. The DMA registers would hold the count and the base address of the DMA buffer, as well as the which buffer ½ is current, so the data up to that point could be processed before a restart of the ADC channel readout was done. Assuming the current storage location cannot be obtained (maybe the count is available. So, having ‘n’ scans in each DMA ½ buffer slows the interrupt rate for filtering and updating these readings, but if the BMS readout rate is fast it results in ADC channel data being lost.

To avoid data loss each reading in the ½ DMA buffer being processed could be set to a non-ADC number after the reading was handled. With oversampling there are numbers the ADC will not generated. E.g., sixteen max ADC readings (i.e. 4095) result in a max 16 bit word of 65520, so there 16 numbers available for special meaning. With a right-shift of 1, that would leave 8, etc. When the BMS aborts the ADC readout, before the process is restarted, the ½ DMA buffer that was being loaded could be processed up to the point where the special code was stored. This would avoid throwing away the conversions, and a longer DMA buffer would result is a slower DMA interrupt rate.

If the max rate for BMS CAN requests (controlled by the EMC) is 16 per second there is 62.5 ms between requests. One, ½ DMA buffer with 16 scans, with 16 oversampling, would require about 10.3 ms. Close to six DMA interrupts between BMS aborts.

[End superseded thoughts section]

Open wire detection

The DIAG bit (diagnostic) in the MAX14921 command turns on a 10 ua current drain on each of the cell inputs. This can be used for open cell detection. The procedure is to turn on the bit and wait long enough for the flying caps on cells with an open wire to be discharged to a level where it can be assumed that the wire is open and the cell is not just in a low charge state. The datasheet suggests something on the order of ½ second.

Page 6 02/27/2022 MAX14921 ADC strategies

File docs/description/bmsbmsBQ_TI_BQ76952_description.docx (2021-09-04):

A. Overview

directory: GliderWinchItems/BMS/docs/description

file: bmsbmsBQ_TI_BQ76952_description.docx

eagle directory: GliderWinchItems/BMS/hw/eagle/bmsbmsBQ

file: bmsbq.sch,brd

The following provides a description and some of the thinking in the pcb design. The design intends to provide a number of hardware configuration options. Some of these are to facilitate testing and program development and would not be needed in a later refined design. Provisions have been included in a number of places for implementing the same function using alternate parts that have differing footprints, e.g. a 8 pin and 16 pin isolated CAN driver packages.

This bms connects to a 16 series cell battery module. Multiple battery modules (e.g. six or seven) are connected in series to make a battery string. Hence, a battery string would use six or seven of these bms boards. The boards communicate and get their power via a CAN bus cable, though there is an option for running off the battery module power, which might be required for discharging for storage. This CAN bus cable carries the two CAN signals, “system” ground and system 12v (nominal), plus a signal line for a master reset. In addition to the CAN bus nodes for the battery module bmses there will be a CAN node that is the “energy management controller” (EMC), though some other node might provide the EMC functions for the early implementations.

Since the battery string is not grounded to the system and floats, or is lightly biased via very large resistors, all of the battery modules and therefore the bmses are isolated from the system ground. The bms board processor and bms ic ground is at battery module minus level and isolated from system ground. The CAN drive, FAN control, master reset, dc-dc power, are at system ground. More detail on this later.

This board can accommodate a STM32F405RxT6, STM32F446RxT6, or STM32L431RxT6 processors. These are all 64 pin LPFQ packages. There are small differences in the power pins so there is provision of the pcb for zero ohm or capacitors in several locations. The main target processor is the ‘L431. This processor has comparator and op-amp features that are not available in the ‘F405 or ‘F446, and is somewhat lower power as well, but less sram. The pcb layout allows the comparators and op-amp in th ‘L431 to be used for controlling the on-board charger.

The BMS controller is the Texas Instruments BQ76952, in a 48 pin LPFQ package. There are no alternatives and the design revolves around this part.

The main features of this bms design are--

- Low current battery module charger (approximately 80 ma)

- Cell-by-cell voltage measurement

- Cell-by-cell discharging

- Thermistors (at least three planned)

- FET to discharge entire module at low current via a resistor

- FET to turn on battery module heater (high current)

- FAN controller (on/off/pwm)

- FET (spare) to turn on/off something external.

- Headers for external pcb for external FET cell-by-cell discharging

- Header for I2C bus (3.3v)

- Header for spare I2C bus (5.0v)

- Header for two external processor controlled LEDs

- Header for SWD (ST’s Single Wire Debugger, non-isolated!)

- Header for UART (non-isolated!)

The files for this project are on github repository--

https://github.com/GliderWinchItems/BMS

The files of interest for the board design described here, within the repository, can be found at

hw/eagle/bmsbmsBQ/bmsbq.sch and ‘.brd.

The general board layout has three ground plane sections. The leftmost (as viewed in eagle .brd) is the system ground (and 12v, etc.). The middle section is processor ground (which is at battery module minus level) and the right section the BQ76952 bms wiring (which is also at battery module minus level). The processor ground and BQ ground are connected at one point to reduce the effect of digital noise from the processor with the BQ adc measurements.

Note: The eagle file was renumbered with the prefix “100” for parts on the underside layer. Later part additions retain the top/bottom “100” prefix but may not correspond to the location strategy the eagle renumbering script uses whereby the part numbers start at a board corner and work up and across.

Note: The term “shutdown” can have a number of meanings. For the processor it can be a low power mode where everything, except the RTC domain, is stopped (and Vcc is present). Another use of the term could be when the processor Vcc is not present. For the BQ76952, shutdown is a low power mode where most features are turned off, and though connected to the battery module, the current drain is less than 1 ua.

Note: Values of resistors, capacitors are tentative and subject to change during development.

B. CAN bus cable connections

A 10-pin ribbon with IDC type plug plugs into the bms board with a 2x5 keyed header. At the other end it is crimped into a 9-pin female D connector and a short distance onward to a male D connector. These 9 pin D connectors are mounted on the battery module box. CAN bus cables daisy-chain the battery modules together. Having the chain form a ring allows cutting the current drop in the power carrying wires in half. To reduce voltage drop in the ribbon cable the plus and minus wires are tripled.

The following ribbon pin assignments (should!) correspond to the 9-pin D connector and attempts to match the typical CAN assignments for 9-pin connectors. The header on the pcb is JP6--

2x5 DE9 Description

1 1 system +12V

2 6 system ground

3 2 CAN L2

4 7 CAN H2

5 3 system ground

6 8 master reset

7 4 system +12V

8 9 system +12V

9 5 system ground

10 unused

(DE9 sorted order)

2x5 DE9 Description

1 1 system +12V

3 2 CAN L2

5 3 system ground

7 4 system +12V

9 5 system ground

2 6 system ground

4 7 CAN H2

6 8 master reset

8 9 system +12V

12v polarity protection--

Reverse polarity protection on the 12v system power is provide by a pfet (FET103). The FET blocks if the +12v and system ground are reversed.

Input current measurement--

For development and test purposes, a thru-hole 0.1 ohm series resistor (R5) allows for measuring the current input.

Master reset--

The master reset line is used to reset the processors on the CAN nodes, i.e. reboot. This might be used to reset for program re-loading over CAN, or simply restart during development.

The master reset line in the CAN bus cable drives a H11L1S opto-coupler (OPT101). Pulling the master reset line to system ground turns on the opto-coupler and pulls the NRST (reset) line on the processor to ground. The 3.3K, R121 resistor on the opto input limits the current on the input, and the 10K, R8, pull-up resistor holds the NRST line normally high. The pushbutton allows manually resetting the processor. Diode D5 on the opto input protects against reverse polarity.

LED-12V power--

LED1, 6.8K, R2 indicates that 12V power (of correct polarity) is present.

CAN 5v supply (5V/2)--

From the 12v power, the AP7380Y (REG1) linear regulator supplies 5v to the system side of the isolated CAN driver (ISO1042); eagle net designation 5V/2. C121, 4.7u, and C108, 4.7u, provide the necessary input/output capacitors for the regulator.

FAN 12v supply--

Given that the cooling fan(s) are spec’d at 12v +/- 10%, but the system 12v will at times be 13.8v or even higher, a regulator is provided to limit the voltage to the FAN(s). There are two regulator options. One is the LDK320 (REG3A) which is a SOT-89 package, which has a low quiescent current, but may not be available. The other is the venerable LM7812T (REG3B) which is a TO-220 package, but has an 8 ma quiescent draw. The regulator uses C1, 1u for the output, and shares C3 (1u), C122 (4.7u), C121 (4.7u) on the +12 protected line.

The regulated FAN 12 goes to a 4 pin header (JP5)--

1 – system ground

2 – FAN regulated +12v

3 – FAN tachometer

4 – FAN on/off/pwm

The fan on/off/pwm signal is zero for off; open circuit (fan has a weak fan pull-up) or 5v for full on; or pwm 0-5v. To assure the FAN does not run when the processor is off, or not controlling the i/o pin, a 74LVC1G14 inverter (P$1) with its input pulled up with the 10K R107 resistor holds the FAN off when the opto-isolator (OPT100) is not active. The R107 pull-up to 5V/2, system ground 5 volt supply, is also needed for the open drain OPT100.

To control the FAN the processor pin PA5 drives a NFET (FET102). Pull down resistor R127 assures a floating PA5 does not energize the FAN. The opto input current is set by the 1.8K R105 resistor and 5V/1, 5 volt processor ground side supply.

C. Power supply chain

DC-DC 12 to 15v converter

The +12v from the CAN bus cable is isolated and stepped up to 15v from the +12v protected line. There are two converter options. PYBJ6-D12-S15 (IC1A) and AMG1215SNZ (IC1B). These produce a regulated 15v output with an input voltage in the 9-18v range. They are both rated at 6W. The PYJ6 is the preferred part and will sustain the 15v to a current output of about 1.4x the rating, which at 15v is about 560 ma. The output voltage regulation holds up to the overload cutoff limit then drops very rapidly, i.e. a sharp knee.

The 15v supplies the power to the processor and bms ground domain. The battery module trickle charger is the main consumption of the power. Stepping up the 12v input to 15v helps the efficiency of the charger switching to boost to the module voltage, which with 16 cells is a maximum voltage, ~56 (LiFe) or ~67v (LiPo).

5 volt processor (5V/1)

AP7380Y (REG100), with C111, 4.7u, and C123, 4.7u, supplies 5v for the processor side. It drives the following--

74HC00 (IC1) FET gate drive logic (to drive dump and heater FETs)

I2C2 bus (spare I2C, e.g. 5v LCD displays)

Vcc (3.3v)

Vcc (REG1A or REG1B) supplies 3.3v--

Processor

I2C1 bus

pull-ups (R14) (R11)

BQ76952

Sub-board: external FET discharge

CAN driver processor side

FAN tach opto-isolator pull-up (R17)

NRST (hard reset) pull-up (R8) for pushbutton and opto-isolator

LED2 and LED3 (R15) (R16) 3.3K current limits, JP13 external LED provision

Vdd (analog voltage) is connected to Vcc via a ferrite bead and by-passed with C105 (0.1u) to reduce Vcc digital noise.

Two Vcc regulator options are provided. If the processor is run at a low sysclk rate, the linear regulator, AP7380Y, (REG1), is the most efficient approach for regulation. For larger currents, a TO-220 footprint is provided that will handle a VOX7803-500 switcher, or linear LD1117-V33. Input/output caps: C119 4.7u, C120 100n and C124 4.7u. The values might vary depending on the regulator chosen.

The input to the Vcc regulator is via a diode OR which allows powering the processor from three sources. One source is the 15v described above, via diode D1.

Another input, via D2, is from the BQ REG2 output. The BQ76952 has provision for two regulators, fed from an external NPN transistor follower which drops from the plus of the battery module to supply the internal regulators. The BQ registers allow selecting the internal regulator voltages--1.8, 3.0, 3.3, 5.0v. Using the 5.0v for the diode OR avoids OR’ing the output of the Vcc regulator. The program controls the configuration of BQ REG2 and whether the BQ REG2 is on/off.

The third input to the OR, via D3, is from a P-FET, N-FET combination to switch directly to cell #3 of the battery module. Cell #3 provides a voltage that is less than the 15v dc-dc converter and greater than 5v, so if the P/N switch is on and the CAN bus 12v is present, the drain on the battery is limited to FET leakage.

FET1, and FET104 form the P/N switch. N-FET, FET1, pulls down the gate of the P-FET to turn it on. An external switch via JP1 can also turn on the P-FET. Processor pin, PC13, can turn on the N-FET. Resistors R4, and R125 assure the FETs are off when the external power is off.

A number of powering scenarios can be implemented with this arrangement. Being able to discharge the battery module to a voltage for long-term storage might require operating the bms without power from the CAN bus. In this case the processor must be powered from the battery module.

The RTC can wake up the processor from a complete shutdown by using the RTC and PC13 to turn on the P/N switch. PC13 is in the RTC domain and powered by VBAT even when the main power, VCC, is off. The LSE (low speed external osc, i.e. xtal) can run and a time setting signal an “alarm” in the RTC. The alarm routes to PC13 to turn on the P/N switch at which point the processor executes a power-on-reset and restarts.

VBAT

The processor VBAT supplies the RTC (Real Time Clock) domain in the processors. When Vcc is off, VBAT will maintain the RTC and associated sram registers. The RTC domain provides a means for saving some data when the processor is in shutdown mode with VBAT present.

It requires a minimum of 1.7v and draws less than 1 ua with the 32 Khz clock running. There are two alternatives for powering VBAT. One is with the BQ76952 regulator REG1. This can be set to 1.8v. A zero ohm resistor, R12, connects REG1 to the VBAT processor pin1 and C118.

An alternative is to install the MCP1810 linear regulator (REG101). This is a low quiescent current regulator powered from battery cell #1. The current drain, though continuous on the cell, is less than 1 ua so the unbalancing of that cell from the others is negligible. R123 and C118 give some protection for hot-plugging the battery module to the board. R123 and the MCP1810 would not be installed if the BQ (REG1) is used for VBAT.

Note: The processor internally connects VBAT to Vcc when Vcc exceeds the VBAT pin voltage.

D. Charger

A low current charger boosts the 15v dc-dc isolated converter to the voltage of the battery module by switching an inductor with a FET. The FET turns on and the inductor current increases. The FET turns off and the inductor “flyback” dumps the energy into the battery pack. The strategy is to set a pwm rate and on/off ratio such that the current drops to zero during FET off time, and the current build-up during the on time results in delivering the power available from the dc-dc converter; usually called a discontinuous conduction mode (DCM). Using this mode, the average output current can be set without feedback, i.e., open-loop.

If the parameters are such that the current does not drop back to zero during the FET off time the current level increases each cycle and unless there is some mechanism for limiting the peak current eventually something fails. If the build up is slow enough, the dc-dc converter will eventually shutdown in overload mode. If the build-up is fast the output capacitance of the dc-dc converter may be sufficient to destroy the FET before the overload limit begins lowering the voltage.

Drive to the charger FET is from processor PA8, timer TIM1CH1. This drives the MCP1416 (or MCP1401) FET gate driver (IC102). The gate drive is supplied with 15v from the dc-dc converter. In addition to the output capacitance on the dc-dc converter module, pads are provided for C113, C114, C115, (4.7u, 0.1u, 10n). R118 is a small series resistor between the driver and FET gate, shown as 6.8 ohms on the schematic. It is expected that values of around 15 ohms might be optimum, but the FET and other factors will be involved. A test point, TP1, provides convenient access to monitoring the FET gate signal.

The size and type of inductor for the charger (L1) will be selected after some experimenting. The Coilcraft RFB1010 series, 47 uH, is expected to be a reasonable mid-point for the inductances. The pcb footprint is arranged with alternate hole spacings for various size thru-hole inductors and rectangular areas without solder mask for various smd mounting inductors.

The PMV280ENEA switching fet (FET3) was chosen for its small output capacitance. The 1.1a current rating is sufficient to handle the peak currents. The SI2324A has a larger output capacitance and somewhat higher current rating. The output capacitance factors into ringing when the FET turns off, and the period of the ringing can affect the current at the beginning of the next fet on duration.

The switch fet drain and inductor connect to diode (U$3) that reverse biases during the FET on duration and directs the energy to the battery when the FET turns off.

LTSpice simulation files may be found in repository LTSpice directory.

Several features are present to deal with the open circuit situation. If the voltage of the inductor/FET-drain is not limited in some manner, when the FET turns off there is nothing to limit the voltage and the FET will have to absorb the energy in the avalanche mode. To prevent FET damage a capacitor plus zener is used to limit the voltage, and several schemes using the ‘L431 comparators with DAC, and/or ADC are used to shutdown the FET switching quickly.

When the battery module is not connected there is an open circuit situation. Capacitor C5 (thru-hole) or C112 (smd), 1uF100v, will start at 15v, and with each pwm cycle of the FET increase the voltage. If the ribbon connector is removed while the charger is in operation, C5 or C112 will be starting from the current battery module voltage which could as high as 62v (16 cells of LiPo fully charged).When the voltage reaches the zener voltage the zener will limit further increases. There is a thru-hole and smd alternative for the zeners (D4 and D6). 82V is the expected value.

Since the charger can generate close to 5.5W of power and the zeners are rated at 0.5W or less, a means of detecting the over-voltage and turning off the pwm is needed. Several methods are possible.

A simplified circuit sketch, config_02202100.PDF, in the repo directory docs/description, shows the pins and internal switches for the various configurations that use the internal op-amp and two comparators in the ‘L431. Reference to this sketch may be helpful in following the following.

One method of shutting down the pwm is to measure the voltage at the capacitor/zener junction. R115 and R119 form a voltage divider for input to the processor. Several variations are possible. One is to use a high value resistor that draws very little current from the output, e.g. 4M|210K. That divider impedance is too large for the processor ADC; 50K is about the amount where variable leakages begin to affect the ADC readings. To handle this an op-amp follower, a TLV521 (IC101) option is provided. The op-amp output feeds PA7 and PB2. PB2 can be configured for comparator 1 input (COMP1_INP). PA7 [‘L431-ADC1_IN12] for the ADC measurement. DAC1 can be configured to connect to the comparator minus (COMP1_INM). The comparator output can be configured to internally activate the break-input (BKIN2) to timer TIM1 and immediately turn off the timer output pin driving the FET. If the comparator is not used, or not available in the case of using the ‘F405 or ‘F446 processors, the program must rely upon the ADC measurement and turn off the FET. This of course is not immediate and until the software detects the over-voltage and turns off the FET, the zener must dissipate the power. The comparator scheme is hardware and not software dependent, and in fact, it might be possible to eliminate the zener.

Another variation is a second output diode, PMEG10020 (D109). This isolates the battery module from the voltage divider. With the voltage divider isolated, the divider is no longer a continuous drain on the battery module. Smaller resistors can be used for the R115|R119 voltage divider and the op-amp follower eliminated, e.g. 64K|3.3K. However, the voltage measured by the divider is higher than the battery module voltage due to the diode drop. But, the bms BQ can measure the total battery module voltage, but the measurement take much longer (but is 16b adc rather than 12b).

For FET current monitoring a 0.1 ohm resistor, R6, is placed in the FET (FET3) source. Test point, TP1, provides a place for a ‘scope. The voltage across the 0.1 ohm sense resistor is connected to PB4 and PC3. Zero ohm, R23, is an option to connect to PA0 as an OP amp input. In the L431 this PB4 can be configured for comparator 2 input (COMP2_INP); DAC2 can be configured for internal connection to COMP2_INM. The output of the comparator can be configured as a break signal to timer TIM1 and turn the FET drive off whenever the current sense voltage exceeds the DAC setting. This scheme is a hardware means for preventing the FET current from exceeding its rating.

A possible enhancement is to install the zero ohm, R23, which connects the sense 0.1 ohm resistor R6 to PA0, and configure the ‘L431 op-amp (OPAMP_INP). The op-amp can be configured for gain (requiring PA1, OPAMP_INM, be connected to ground). PA3 is the op-amp output, and comparator 2 input (COMP2_INP) can be configured to connect to PA3. The comparator minus, and output are then configured as in the foregoing with DAC2 and timer 1 break. This arrangement allows limiting the FET peak current, but with the op-amp gain in the sensing of the sense resistor voltage.

The output of the 0.1 ohm sense resistor R6 is also passed through a RC filter for average current monitoring: R7-C6, 1.5K-0.1u. PC1 connects to this filter output and ADC measurement [‘L431-ADC1-IN5]. For the ‘L431, PA0 can be connected to the RC output via zero ohm R9. PA0 can be configured for OPAMP use as previously described, however the output can be configured to internally connect to ADC-IN8. For the ‘F405 or ‘F446 one has to be content with PC1 ADC and/or PA0 configured for ADC input. With the ‘L431 and this configuration the smoothed FET current waveform can be measured with op-amp gain.

Another feature that might be of use is the facility in the ‘L431 for blanking a comparator with a timer to avoid an unintended comparator output for a short spike such as when a FET turns on. Comparator 2, COMP2, can be linked with TIM15CH1 so that TIM15CH1 can blank the comparator. Similarly, comparator 1, COMP1, can be linked with TIM1CH5 so that TIM1CH5 can blank the comparator.

For software control of the charging there are a number of strategies that can be employed to make use of the above measurement techniques. Using the L431 processor and comparators gives the most flexibility, as well as providing protection of the fet.

Header JP3, R120 (1 ohm) provides a test point for measuring output current.

Test points--

TP1 – FET102 gate

TP2 – PA0 OPAMP_INP

TP3 – PA2 COMP2_OUT

TP3A – FET CURRENT SENSE RESISTOR

TP4 – PA3 OPAMP OUTPUT

TP5 – PA6 TIM1_BKIN_COMP2

TP6 – PA11 TIM1_BKIN2_COMP1

NOTE: The above test points are at battery module ground, not system ground.

E. BMS

Battery cabling

The battery module is connected to the bms board with a 20 wire ribbon cable. On the bms board end of the ribbon an IDC 2x10 plug mates with the 2x10 (keyed) header (JP9). 1X10 headers JP8, and JP10, mount on the underside and provide a means of extending the ribbon cable connections to a sub-board that would use fets for cell balancing discharging at rates higher than supported by the BQ76952 using its internal fets.

The general scheme for splitting and routing the ribbon cable is shown in crude sketch. See pdf--

GliderWinchItems/BMS/hw/docs/wiring/Ribbon-wiring-sketch.pdf

Note that the order of the first four wires listed below (3/21/2021) is slightly different from the order shown in the sketch.

The ribbon cable wire assignments have the cable split into a group that goes to the top of the battery module, and another group that goes to the bottom. The ends of the ribbon connect to cells on the module, and peel off in sequence as the cable goes down the battery module. Pictures of the battery module (18 positions, 16 cells installed) can be found in the repo directory docs/pictures.

The pcb layout is based on the following pin assignments--

col 1: 2x10 header pin number

col 2: 20 pin ribbon color

col 3: module cell number

col 4: additional description

---------TOP SPLIT-------------

1 BLK - PGND/SRN (BATTERY MODULE MINUS)

2 WHT - SRP (CURRENT SENSE POS)

3 GRY - VSS (CURRENT SENSE NEG)P

4 PUR - C0 (CELL #1 MINUS)

5 BLU - C2 (CELL #2 PLUS)

6 GRN - C4

7 YEL - C6

8 ORG - C8

9 RED - C10

10 BRN - C12

11 BLK - C14

12 WHT - C16 (CELL #16 PLUS) (BATTERY MODULE PLUS)

----------BOTTOM SPLIT ---------

13 GRY - C1 (CELL #1 PLUS)

14 PUR - C3

15 BLU - C5

16 GRN - C7

17 YEL - C9

18 ORG - C11

19 RED - C13

20 BRN - C15

The individual cell connections go through a 20 ohm series resistor (schematic labels RC101-RC116) to the BQ76952 input pin, and each pin has a 0.1u by-pass capacitor (CR101-CR116). The discharge resistance is a combination of the series resistor, in conjunction with the internal fet resistance (15 ohm typical). (Note: when adjacent cells are being discharged they share a common series resistor with the result that the discharge current for the cells are not the same.)

Ribbon cable wires are present for current sensing (SRP, SRN). R116, R122, and CF116, CF111 are input filtering.

I2C communication

There is provision for two I2C buses; I2C1 and I2C2. I2C1 is powered with Vcc at 3.3v and I2C2 is powered with 5V/1 at 5v. I2C2 provides for 5v external modules such as an LCD. I2C2 is described later. I2C1 is key to the ‘L431-to-BQ76952 communication, and also the provision for a port expander on a sub-board for external fet discharging.

The processor I2C1, PB6 (SCL) and PB7 (SDA), connects to the BQ76952 and two 4 pin headers, JP10, JP11. JP10 is mounted on the bottom of the pcb for mating with a sub-board if external FET cell balancing/discharging is used. JP11 mounts on the top for possible connection to external 3.3v I2C devices.

Header pin assignment--

1 – ground

2 – +3.3v (VCC)

3 – PB7 – I2C1 SDA w 3.3K (R11) pull-up to Vcc

4 – PB6 – I2C1 SCL w 3.3K (R14) pull-up to Vcc

The BQ76952, unless preprogrammed, boots up in I2C “fast” (400KHz) mode.

The regulator for VCC can receive power from three sources. VCC is required for processor communication with the BQ76952.

Control

ALERT connects to PB3. The error detection in the BQ76952 can to cause an interrupt in the processor via the ALERT pin. Enabling the internal pull-up on the processor is necessary. An external pull-up on the pcb is not provided. The ALERT pin is active low, i.e. normally high and pulls low when the BQ detects a fault.

RST_SHUT connects to PB5. PB5 configured for push-pull output. Asserting RST_SHUT for greater than one second will cause the bms to enter SHUTDOWN mode. For less than one second it causes exiting SLEEP and DEEPSLEEP modes.

TS2 is not connected and floats. When the BQ enters into shutdown mode TS2 is connected to a high impedance (~4.5M) to approximately 5v. If TS2 is pulled low BQ exits shutdown mode. If TS2 is low before the BQ command to enter shutdown mode, e.g. TS2 connected to a thermistor, then BQ enters a “soft shutdown” condition, but cannot enter a full shutdown. Hence, TS2 is left float and not used.

LD is connected to PD2. Control of LD might have some use in controlling the entry and exit from shutdown, and is more of a jic provision.

Regulators

REG18 is by-passed to ground with C110, 2.2u, per the datasheet.

NPN transistor, Q1, drops the battery module voltage, (PACK), via resistor RT1, into the input REGIN. BREG drives the base of the NPN. C9, 1u, and RT1, add filtering. C8, 22n by-passes the emitter (per datasheet). The power dissipation requires consideration as the total REG1 and REG2 the transistor plus resistor must dissipate the battery voltage minus about 5v at the total current. Hence, RT1 is a thru-laid out as hole vertically mounted resistor which can handle ½ w.

REG1 can be used to power VBAT using the 1.8v or 3.0v voltage selection.

REG2 can be used to power the 3.3v Vcc by using the 5v, which diode ORs (D2) with other inputs to the 3.3v linear regulator (REG1A or REG1B). Enabling REG2 is necessary for turning on the Dump and Heater fets.

Thermistors

BQ pins TS1, TS3, and DCHG connect to 2 pin headers JP2, JP4, JP5. 10nF capacitors across the thermistors help noise (per datasheet). The bms register initialization will accommodate either 10K or 100K thermistors with internal pull-ups.

TS1, TS3, and DCHG can also be configured as ADC inputs.

DSG and CHG connect to 2 pin headers for two additional jic thermistor (or ADC) inputs.

F. Misc

Dump

For discharging the entire battery module FET (FET100) can switch in a 10W resistor mounted on the board, or a resistor connected to the two pin header JP17. Thru-hole pads are positioned on the board so that a 10W resistor can be mounted on the bottom side of the board. The resistor is not shown on the schematic. For an off board resistor, the header pin connected to the fet drain is expected to be connected to the resistor, and the other end of the resistor to battery module plus. The header pin for the fet source would be connected to the battery module minus. The minus connection avoids the resistor current passing through the board traces and battery module ribbon cable. R101 holds the fet off. R102 makes the fet act as a source-follower if the external minus connection is missing.

To prevent inadvertently turning on the dump fet the processor must set one I/o pin high (PC10) and another pin (PC8) low. IC1 gates invert and AND, as well as increase the voltage from the 3.3v processor to 5v, for driving the dump FET. R18, 470K, assures the gate input does not drift high if the i/o pin is not configured for output.

Configuring the BQ REG2 for 5v (5V/3) is required for powering IC1 which supplies the gate drive for the FET100 and FET2.

Item: When the battery module is not connected the BQ chip will only be powered if the charger is active, i.e. the 1uF, 100v capacitor C112 with zener or software over-voltage control powers the BQ.

Heater

At times it may be necessary to warm the battery module before the first launch. A FET, FET2, for switching on a high wattage resistance is provided. A TO-220 footprint for FET2 provides for a high current fet. The same logic as above for “Dump” is used. In this case it is PC12 high and PC11 low that enables the FET. Two spade terminals are provide beside the FET for the external connections to the heater. The same as for “Dump,” R126 limits current should the external battery minus be missing. R124 assures FET off when the processor is not powered. R104 assures the FET would not turn on if PC12 is floating.

Dump2

This provision might be used for some external load, e.g. a relay. Board space allowed adding this jic. FET101 is driven by PC6. Two pin header JP16 connects to the fet drain and source. R103 and R100 provide the protection in the manner described above.

The FET101 gate is driven directly from the processor i/o pin and does not depend on the 5v source as does Dump and Heater.

Spare thermistors

Header JP12 can be used to connect to thermistors. PC4 and PC5 can be configured for ADC.
R10 and R13 are pull-ups to Vcc.

HSE

Provision is made for the High Speed External oscillator, i.e. xtal control. Xtal, Q100, loading capacitors, C107, C109 (15p), startup resistor R112, 1M. Processor pins PD0, PD1.

LSE: 32 Khz oscillator

A crystal (X101) provides for 32 Khz LSE (Low Speed External) oscillator implementation. C100, C101 (22p) are the xtal loading capacitors. The LSE uses processor pins PC14, PC15.

In the processor shutdown mode the RTC internal 32 Khz osc (LSI) is shut down as it is not part of the RTC domain. However with the xtal it will run in the LSE mode. In the other current low power modes the RTC LSI osc runs.

Spark gap

Since the battery module ground is isolated and floating with respect to the system ground, provision for limiting a voltage built up that might breakdown one of the isolation barriers (dc-dc converter transformer, opto-isolators, or CAN driver). A pcb spark gap is made with pad PD1. R3 can be a resistor for limiting sparkover current or fusing in more catastrophic situations.

Thru-hole pads are located near the pcb spark gap for mounting a gas discharge type spark gap.

I2C2 bus

Header JP21 provides a I2C bus with 5v. This purpose of this bus is for a possible LCD display which would require 5v. The I2C1 bus described above is for newer 3.3v parts.

This is the only load on net 5V/1, AP7380Y, linear regulator, (REG100), the regulator and capacitors C111, C123 can be omitted if this I2C bus is not implemented.

Header JP21 pin assignment--

1 – ground

2 – +5.0v (5V/1)

3 – PB14 – I2C1 SDA w 3.3K (R11) pull-up to 5V/1

4 – PB13 – I2C1 SCL w 3.3K (R14) pull-up to 5V/1

LEDs

LED1 (R2) 6.8K – CAN bus cable +12v protected

LED2 (R15) 3.3K – GRN – PB0 also pin2 JP13

LED3 (R16) 3.3K – RED – PB1 also pin 3 JP13

Provision for LED2 and 3 on-board and three pin JP13 header for (low current) external LEDs.

JP13 pin1 – 3.3v (VCC). PB0 and PB1 pull down, i.e. set to 0 turns the LED on; 1 is off.

bmsbmsBQ_TI_BQ76952_description.docx: eagle board design Page 13

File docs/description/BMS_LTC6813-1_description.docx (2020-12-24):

A. Overview

Two boards are used to monitor, charge, and balance a battery module of up to 18 cells. One board carries a low current charger, power isolation, and CAN interfacing. The second board carries STM32F4 processor and LCT6813-1 BMS chips. The two boards stack and are connected with two 1x30 headers at each edge.

The top of the top board carries the headers for the more frequently changed external board connections. The I2C header is on the bottom of the bottom board.

Each cell of the battery module is connected to the charger (top) board via 20 pin ribbon cable to an IDC type connector. (18 cell wires plus two wires to battery module ground).

A bus with 12v nominal, ground, and CAN signals connects to each battery module unit. A 10 pin ribbon cable connects the connectors on the battery box (9 pin D) to the charger board.

There are provisions for other features--

- FET drive for a resistor to by-pass current across the entire battery module.

- UART header for debugging (FTDI, JP4).

- Header for STLink program loading/debugging (SWD) (JP5) .

- Two FET driven, external LEDs, JP8.

- Three thermistors, JP10

- One Hall-effect (or 5v sensor) (JP7)

The two pcbs are 140x45mm and designed fit in the space between the batterys and front of the battery box. The 20 pin ribbon cable splits with one half going to the top of the battery array, and the other to the bottom half.

B. Power chain: bmschgrR.sch (top board) & bmsbmsR.sch (bottom board)

The main power for the unit is from the CAN bus +12v (nominal) and this references to “system” or CAN bus ground. This battery module electronics is isolated from the CAN bus ground.

The following is the chain (more detail follows)--

CAN bus +12 main input drives

1) linear 5v for CAN bus side CAN interface

2) dc-dc converter (12→15v) with isolation drives,

a) dc-dc (15v→75v) low current charger

b) dc-dc (15v→7v) drives,

(1) bms/transistor regulator

(2) linear 5v

(3) dc-dc (7v→3.3v) processor

CAN bus ground referenced (AGND on top board schematic)

Referring to the schematic, the +12 (nominal) from the CAN bus is reverse polarity checked by the FET U$1. The 0.1 ohm (R33) resistor in series is provides a test point for measuring current .

The +12v drives a 7805L linear regulator (IC2) to provide +5v for the CAN bus side of the unit. The +5v drives the CAN bus side of the CAN interface (ISO1050) and logic for fan control. There are several configurations of fans that can be accommodated, with the common feature that the FET driving the fans is at CAN bus side ground and the control is isolated and driven from the processor at battery module ground.

+12 drives a dc-dc converter CUI, Inc, PYBJ6-D12-S15 (U$2) that isolates the +12v on the CAN bus side from +15v on the battery module side. U$2 regulates as well as isolates.

+12v drives LED2 to indicate that 12v is present on the CAN bus side.

Battery module ground referenced (GND on schematic)

+15v is converted to lower voltages for the BMS and processor circuits. There are two sources for the +15v. One is the dc-dc converter from the top board which isolates the CAN bus +12 power. The other source is from the battery module itself (more detail described later.)

The +15v diode OR’ed from the top board (CAN bus) or battery module powers the following features--

- 7805L linear regulator (IC1) which provides +5v for the battery module side of the CAN interface (ISO1050).

- DC-DC boost driver (MCP1401|1416) and FET U$12 to produce the a high voltage for lower current charging the entire battery module.

- Power to the bottom board (bmsbmsR.sch) where the +15v is converted to lower voltages for the processor and bms chips (via pin 1 on JP2 on the bottom edge 1x30 header).

– A dc-dc converter reduces the +15v to +7v. The board layout provides three options for this dc-dc converter. The least expensive, but largest footprint, is based on a LM2596.

- The +7 drives a LM7805L. The +5 output goes to the Hall-effect header, I2C bus, thermistor sensors and pin 25 of the top 1x30 header (connecting to +5 on the top board). (Note: there is a redundancy with LM7805Ls on both the top an bottom boards. Better would be to drive the I2C +5 from the top board via pin 25 and have the analog Hall effect, and thermistor +5 from the bottom board LM7805L.)

- The +7v goes to the collector of a NPN transistor (Q3) that forms part of the LTC6813-1 5v regulator.

- The +7v drives a dc-dc converter to produce 3.3v for the processor. Provisions is for two dc-dc converter modules. One is the LM2596 based module. The other is the minibuck.

More detail--

- Header for I2C bus which could be used for a LCD display, or port extension for pushbuttons and LEDs.

C. BMS board bmsbmsR.sch (bottom board) features

C.1 Power supply chain voltage measurements

The processor ADC is used to monitor power supply voltages.

a. +15 Or’ed voltage (drives dc-dc boost charger and rest of chain)

R47/R48 PC3

b. +7

R49/F51 PC5

c. +5

R44/R45 PC2

d. Total battery module

Depending on the parts fitted, the battery module total voltage can be measured with the following, however the external dump resistor control is not possible. Furthermore, the total battery module voltage can be generated by totaling the individual cell readings.

(R37+R56)/R38 PA1

C.2 BMS GPIO

Usage of the nine available bms gpio pins (16b ADC)--

The measurement of the 5v supply is used in conjunction with the thermistors and Hall-effect to make the measurements ratiometric with respect to the 5v supply.

gpio1 – 5v supply to thermistors and 5v sensor (e.g. Hall-effect)

R25/R50

gpio2 – thermistor #1

R26

gpio3 – thermistor #2

R27

gpio4- thermistor #3

R28

gpio5 – Hall-effect

R29

The following are for future possibilities--

gpio6 – thru-hole pad R33→gnd

gpio7 – thru-hole pad R53/R34

gpio8 – thru-hole pad R35 →gnd

gpio9 – thru-hole pad R36 → gnd

C.3 I2C bus

The I2C bus, I2C2, is brought out to 1x4 header JP3 pins--

1) gnd

2) +5

3) PB8 SDA with pullup, R23

4) PB9 SCK with pullup, R24

C.4 Processor—STM32F405RxT6 or STM32F446RxT6

Pinouts are “mostly the same” between the two processors. The differences are in the on-chip power pin by-passing.

PB11 connects to 4.7u cap, CP2, for F446 and is open and available as i/o pin for F405.

Capacitor pads for CP1 and CP3 are zero ohm for F405 and 4.7u for F446.

C.5 BMS LTC6813-1

Regulated 5v for internal chip derives from NPN transistor (Q3), with +7v on the collector and the base driven by the internal feedback. The transistor base provides 5v for the bms. R19/C6 provides filtering of the 7v, as recommended in the datasheet.

Communication of the processor with bms is via spi and other control lines--

PA2 – BMS WDT

PA4 – SPI1 NSS BMS CSB/IMA

PA5 – SPI1 SCLK

PA6 – SPI1-MOSI (?) BMS SDO with R46 4.7K pullup

PA7 – SPI1-MISO (?) BMS SDI

Cell connections--

R1 – R18 and CC1 through CC18 provide ADC sense filtering with the time-constant recommended in the datasheet. (Note: by-pass current limiting resistors and external fets reside on the top board.)

C.6 Battery dump

Provision is made for an external power resistor for by-passing current across the total battery. Several configurations can be implemented depending on the parts fitted.

For a straight turn-on/turn-off via FET, Q10, R38, 1M, will hold assure the FET is off when the processor is not powered. PA1 will drive the FET, but the FET needs a low g-s turn-on voltage since the PA1 will only rise to about 3v. R57 is fitted with zero ohms to ground the FET source. The FET drain on JP2 pin 3 would go to the dump resistor, and the other side of the resistor to the battery module plus directly (not via the ribbon cable). Pin 4 on JP3 would go to the battery module minus (GND).

Modification of the foregoing to provide current sensing can be made by fitting R57 with a small resistance. Via R31, PA3 can measure the voltage drop across for R57 to measure current, however the voltage drop will be small so the resolution will be poor.

As mentioned earlier, the total battery module voltage can be measured by other fittings of the parts. Alternately, the +15 from the top board, i.e. before OR’ing, can be measured.

C.7 Battery module powering

The provision for powering the bms from the battery module allows slow discharge for long term storage without the need for a 12v CAN power bus. A pushbutton on the module box is pressed while the unit is powered from the CAN bus. The program then maintains the bms board (no charger of course) until the discharge has completed at which time a FET connecting the battery to the bms is turned off. Once off, the external pushbutton will not activate the unit.

Thru-hole pads U$13,14,15 allow selection of 3 or 4 battery cells. The NFET/PFET pair, QQ100, is acts as a power switch to connect the cells to the power chain and diode OR’s with the +15v from the dc-dc converter. PA0 drives the NFET of the QQ100 pair, and is pulled to GND with R32. Pressing the external pushbutton connected to JP11 signals the processor as well as turns on the QQ100 FET switch.

Since the pushbutton is a pull-up, Vcc must be present. Therefore, the bms has to be powered from the CAN bus for the switch to present. Once the switch is active the program must configure PA0 for output and hold it high until the discharge is complete. When the program drops PA0 the power drops and the bms is dead. Pressing the pushbutton in this state will not start the program since there will be no Vcc for the pushbutton pullup.

C.8 Misc

Onboard LED--

Shows Vcc present: LED1 – R59-Vcc

Heat sinking--
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

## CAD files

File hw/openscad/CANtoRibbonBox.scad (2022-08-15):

/* File: ~/GliderWinchItems/BMS/hw/CantoRibbonBox.scad
  * frame for pc board
  * Latest edit: 20210930
 */
 
 $fn=20;
  
module rounded_rectangle_hull(wid,slen,ht,rad)
{
 hull()
 {    
    translate([-wid/2+rad,rad,0])
        cylinder(r=rad,h=ht,center=false);

   translate([ wid/2-rad,rad,0])
        cylinder(r=rad,h=ht,center=false);

    translate([-wid/2+rad,slen-rad,0])
        cylinder(r=rad,h=ht,center=false);
    
    translate([ wid/2-rad,slen-rad,0])
        cylinder(r=rad,h=ht,center=false);
 }
}
len = 60.5;
wid = 60.5;
ht = 15;
wall = 3;
bot = 3;

psq = 6.0;
pht = ht - 1.5;
phole = 54;

module post(a)
{
    translate(a)
    {
        difference()
        {
            union()
            {
                translate([0,0,pht/2])
                cube([psq,psq,pht],center = true);
            }
            union()
            {
                cylinder(d=2.9,h=100, center=false);
            }
        }
    }
}


module box()
{
    del1 = 2.5;
    difference()
    {
        union()
        {
            translate([0,0,ht/2])
            cube([len+2*wall,wid+2*wall,ht],center = true);
            translate([0,0,2/2])
            cube([len+2*wall+10,wid+2*wall+10,2],center = true);

        }
        union()
        {
            translate([0,0,ht/2+bot])
            cube([len-wall+del1,wid-wall+del1,ht],center = true);
            
            xof = len/2+wall+2;
            translate([ xof, xof,0]) cylinder(d=3.5,h=50,center=true);
            translate([ xof,-xof,0]) cylinder(d=3.5,h=50,center=true);
            translate([-xof, xof,0]) cylinder(d=3.5,h=50,center=true);
            translate([-xof,-xof,0]) cylinder(d=3.5,h=50,center=true);
        }
    }
}
poff = phole/2;
box();
post([ poff, poff,0]);
post([ poff,-poff,0]);
post([-poff, poff,0]);
post([-poff,-poff,0]);

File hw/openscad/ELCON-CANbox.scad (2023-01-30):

/* File: ~/GliderWinchItems/BMS/hw/ELCON-CANbox.scad
  * frame for pc board
  * Latest edit: 20230126
 */
 
 $fn=20;
  
module rounded_rectangle_hull(wid,slen,ht,rad)
{
 hull()
 {    
    translate([-wid/2+rad,rad,0])
        cylinder(r=rad,h=ht,center=false);

   translate([ wid/2-rad,rad,0])
        cylinder(r=rad,h=ht,center=false);

    translate([-wid/2+rad,slen-rad,0])
        cylinder(r=rad,h=ht,center=false);
    
    translate([ wid/2-rad,slen-rad,0])
        cylinder(r=rad,h=ht,center=false);
 }
}
len = 46.2;
wid = 50.2;
ht = 15;
wall = 3;
bot = 3;

psq = 6.0;
pht = ht - 1.5;
phole = 48;//54;

module post(a,xht)
{
    translate(a)
    {
        difference()
        {
            union()
            {
                translate([0,0,xht/2])
                cube([psq,psq,xht],center = true);
            }
            union()
            {
                cylinder(d=2.9,h=100, center=false);
            }
        }
    }
}


module box()
{
    del1 = 2.8;
    difference()
    {
        union()
        {
            translate([0,0,ht/2])
            cube([len+2*wall,wid+2*wall,ht],center = true);
            translate([0,0,2/2])
            cube([len+2*wall+18,wid+2*wall+12,2],center = true);

        }
        union()
        {
            translate([0,0,ht/2+bot])
            cube([len-wall+del1,wid-wall+del1,ht],center = true);
            
            // Mounting holes in base
            xof = len/2+wall+2;
            xofx = len/2+wall+5;
            translate([ xofx, xof,0]) cylinder(d=3.5,h=50,center=true);
            translate([ xofx,-xof,0]) cylinder(d=3.5,h=50,center=true);
            translate([-xofx, xof,0]) cylinder(d=3.5,h=50,center=true);
            translate([-xofx,-xof,0]) cylinder(d=3.5,h=50,center=true);
        }
    }
}
poff = phole/2;
py2 = poff + 2;
box();
post([ poff, py2,0],pht);
post([ poff,-py2,0],pht);
post([-poff, py2,0],pht);
post([-poff,-py2,0],pht);

px3 = 18;
py3 = 31;

post([ px3, py3,0],ht);
post([ px3,-py3,0],ht);
post([-px3, py3,0],ht);
post([-px3,-py3,0],ht);

module clamp()
{
 del2 = -5;
    cht = 5;
 difference()
 {
     union()
     {
        translate([0,0,ht/2])
        cube([len+2*wall,wid+2*wall,cht],center = true);
     }
     union()
     {
        translate([0,0,ht/2+bot])
        cube([len-wall+del2,wid-wall+del2,20],center = true);
         
        translate([14,15,ht/2+bot])
        cube([15,15,20],center = true);
         
     }
 }   
}
translate([0,0,11])clamp();

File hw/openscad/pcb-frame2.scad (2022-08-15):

/* File: ~/GliderWinchItems/BMS/hw/openscad/pcb-frame2.scad
  * frame for working on BMS pc board
  * Latest edit: 20220206
 */
 
 $fn=40;
  
module rounded_rectangle_hull(wid,slen,ht,rad)
{
 hull()
 {    
    translate([-wid/2+rad,rad,0])
        cylinder(r=rad,h=ht,center=false);

   translate([ wid/2-rad,rad,0])
        cylinder(r=rad,h=ht,center=false);

    translate([-wid/2+rad,slen-rad,0])
        cylinder(r=rad,h=ht,center=false);
    
    translate([ wid/2-rad,slen-rad,0])
        cylinder(r=rad,h=ht,center=false);
 }
}
brdwid = 50-0.0;
brdlen = 140-0.0;
brdholdx = 134.0-2.0;
brdholdmx = brdlen/2 - 58.0+3.0;
brdholdy = 44;
brdholdmy = brdholdy/2 - 22;
brdholdia = 3.5;

basethk = 3;
baserim = 8;
baserad = 4;

crnr = 4;
   ll = baserim*2 + brdlen;
    ww = baserim*2 + brdwid;

module base()
{
 
    difference()
    {
        union()
        {
            translate([0,-ww/2,0])
            rounded_rectangle_hull(ll,ww,basethk,baserad);
            
            // Lip to strengthen cable connect end of pcb
            uu=130;
            translate([-uu/2,-brdwid/2+1,basethk])
            cube([uu,3,4],center=false);
            translate([-uu/2,brdwid/2-4.5,basethk])
            cube([uu,3,4],center=false);
      
        }
        union()
        {
            // punch out rectangle below pcb
            lll = brdlen/2 - baserim*2-2;
            www = brdwid - baserim;
            translate([lll/2+4,-www/2,-0.01])
            rounded_rectangle_hull(lll+16,www,basethk+10,baserad);
            
            translate([-lll/2-11,-www/2,-0.01])
            rounded_rectangle_hull(lll,www,basethk+10,baserad);            

  //          translate([-brdlen/2+dd/2,-brdwid/2+dd/2,-0.01])
//                 cube([brdlen-dd,brdwid-dd,50],center=false);
            
            // JIC base mounting holes
            translate([-ll/2+4,-ww/2+4,0])cylinder(d=3.0,h=50,center=false);
            translate([-ll/2+4,+ww/2-4,0])cylinder(d=3.0,h=50,center=false);
            translate([+ll/2-4,-ww/2+4,0])cylinder(d=3.0,h=50,center=false);
            translate([+ll/2-4,+ww/2-4,0])cylinder(d=3.0,h=50,center=false);    
        }
    }
}
// Mounting post and holes for pcb
module post(a)
{
    hh = basethk+12+8+2;
    jj = basethk+12+8;
    translate(a)
    { difference()
        {
            union()
            {
                translate([0,0,jj/2])
                cylinder(d1=crnr+2,d2=crnr,h=jj,center=true);
//                cube([crnr,crnr,jj],center=true);
                
//                translate([0,0,hh])
//                cylinder(d1=3,d2=1,h = 3,center=true);
            }
            union()
            {
 
            }
        }
    }
}
module total()
{
xx = 0; // Hole centering adjustment    
    base();
    
    translate([0,0,0])
    {
    post([-brdholdx/2,-brdholdy/2,0]);
    post([+brdholdx/2,-brdholdy/2,0]);
    post([-brdholdx/2,+brdholdy/2,0]);
    post([+brdholdx/2,+brdholdy/2,0]);
        kk=0;
    post([-brdholdmx/2+kk,-brdholdy/2,0]);
    post([-brdholdmx/2+kk,+brdholdy/2,0]);       
    post([-brdholdmx/2+kk,+brdholdmy/2,0]);        
    }
}

total();

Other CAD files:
hw/openscad/pcb-frame3.scad
hw/openscad/battbox-sim/battbox-sim.scad
hw/openscad/battbox-sim/battbox-sim2.scad
hw/openscad/proxy2.scad
hw/openscad/proxybox.scad
hw/openscad/stncl_14921.scad
hw/openscad/voltdiv_box.scad

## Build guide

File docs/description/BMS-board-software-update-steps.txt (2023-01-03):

GliderWinchItems/BMS/docs/description/
BMS-board-software-update-steps
12/27/2022

0. One time software setup

CANldr PC program may need to be compiled--

- Make sure latest version
cd ~/GliderWinchCommons/embed
git pull

- Compile program
cd ~/GliderWinchCommons/embed/svn_discoveryf4/PC/sensor/CANldr/trunk
./mm 

1. Start gateway

- determine serial port for gateway: 
example:
deh@ASUS:~$ ls /dev/ttyUSB*
/dev/ttyUSB0  /dev/ttyUSB1  /dev/ttyUSB2

Since multiple ports the USB connector the port to the gateway:
example:
deh@ASUS:~$ ls /dev/ttyUSB*
/dev/ttyUSB0  /dev/ttyUSB1
/dev/ttyUSB2 is the gateway.

Plug back in and check which one is missing--
deh@ASUS:~$ ls /dev/ttyUSB*
/dev/ttyUSB0  /dev/ttyUSB1  /dev/ttyUSB2

- Start hub-server and socat:
[args: port number, device, baud rate]
deh@ASUS:~$ hub-socat_b 32123 /dev/ttyUSB2 2000000

Check that it is working--
deh@ASUS:~$ nc localhost 32123
E50000400001243C 
E60000400001253E
E700004000012640
...
CTL-C to stop

- Start cangate

cd ~/GliderWinchCommons/embed/svn_discoveryf4/PC/sensor/cangateCON/trunk
./cangateCON 127.0.0.1 32123

Saving the above as a script saves time later--
echo cd "~/GliderWinchCommons/embed/svn_discoveryf4/PC/sensor/cangateBMS/trunk; ./cangateBMS 127.0.0.1 32123" > ~/bin/cgstart
cd ~/bin
chmod +x cgstart

test it--
cgstart
cangateCON should start.
'n' command is useful to monitor CAN traffic (and see program loading)

2. Edit parameters for BMS board

Assure latest list of CAN ids and other constants--
cd ~/GliderWinchCommons/embed
git pull

To avoid git repo conflicts--
cd ~/GliderWinchItems/BMS
git pull

Each BMS board has a pair of .c parameter files. 
  xxxxxxx-adc_idx_v_struct.c - parameters for processor ADC
  xxxxxxx-bq_idx_v_struct.c - parameters for '1818'
 Where xxxxxxx is the CAN id assigned to the loader on the board,
 e.g. B0A00000

The file names of the pair must (and case sensitive) match the CAN ID 
or that board, e.g. the first three BMS 1818 boards--

cd ~/GliderWinchItems/BMS/bmsadbms1818/params
deh@ASUS:~/GliderWinchItems/BMS/bmsadbms1818/params$ ls -l
total 60
-rw-rw-r-- 1 deh deh  5824 Oct 22 22:53 B0A00000-adc_idx_v_struct.c
-rw-rw-r-- 1 deh deh 12007 Oct 22 22:52 B0A00000-bq_idx_v_struct.c
-rw-rw-r-- 1 deh deh  5808 Aug 21 15:16 B0C00000-adc_idx_v_struct.c
-rw-rw-r-- 1 deh deh 12008 Oct 22 21:13 B0C00000-bq_idx_v_struct.c
-rw-rw-r-- 1 deh deh  5808 Oct 16 14:36 B0E00000-adc_idx_v_struct.c
-rw-rw-r-- 1 deh deh 12056 Oct 22 21:12 B0E00000-bq_idx_v_struct.c

Edit the .c file and save.

Do a 'git commit' and 'git push'

3. Load program over CAN

deh@ASUS: cd ~/GliderWinchItems/BMS/bmsadbms1818

'cc' starts the script. The argument is the CAN ID (case sensitive)
deh@ASUS:~/GliderWinchItems/BMS/bmsadbms1818$ ./cc B0E00000

The script compiles the program, using the two parameter .c files identified by the CAN ID.
Following the compile the elf file is converted to srec, and a new srec file generated
that has the checksum and crc added. The CAN loading program then uses the srec file and
sends CAN msgs with the binary in the payload, with checksum checking every 2K flash block.

When the loading completes the BMS board resets and starts up normally.

=========================================================================
=== Here is what the terminal output looks like when it is successful ===
=========================================================================

deh@ASUS:~/GliderWinchItems/BMS/bmsadbms1818$ ./cc B0E00000
################ CAN ID  ################
B0E00000
################ PARAMETER FILES ################
B0E00000-adc_idx_v_struct.c : B0E00000-bq_idx_v_struct.c
################ COMPILE ##################
arm-none-eabi-gcc build/main.o build/freertos.o build/stm32l4xx_it.o build/stm32l4xx_hal_msp.o build/stm32l4xx_hal_timebase_tim.o build/stm32l4xx_hal_adc.o build/stm32l4xx_hal_adc_ex.o build/stm32l4xx_hal.o build/stm32l4xx_hal_i2c.o build/stm32l4xx_hal_i2c_ex.o build/stm32l4xx_hal_rcc.o build/stm32l4xx_hal_rcc_ex.o build/stm32l4xx_hal_flash.o build/stm32l4xx_hal_flash_ex.o build/stm32l4xx_hal_flash_ramfunc.o build/stm32l4xx_hal_gpio.o build/stm32l4xx_hal_dma.o build/stm32l4xx_hal_dma_ex.o build/stm32l4xx_hal_pwr.o build/stm32l4xx_hal_pwr_ex.o build/stm32l4xx_hal_cortex.o build/stm32l4xx_hal_exti.o build/stm32l4xx_hal_can.o build/stm32l4xx_hal_comp.o build/stm32l4xx_hal_dac.o build/stm32l4xx_hal_dac_ex.o build/stm32l4xx_hal_rtc.o build/stm32l4xx_hal_rtc_ex.o build/stm32l4xx_hal_tim.o build/stm32l4xx_hal_tim_ex.o build/stm32l4xx_hal_uart.o build/stm32l4xx_hal_uart_ex.o build/system_stm32l4xx.o build/croutine.o build/event_groups.o build/list.o build/queue.o build/stream_buffer.o build/tasks.o build/timers.o build/cmsis_os2.o build/heap_4.o build/port.o build/stm32l4xx_hal_opamp.o build/stm32l4xx_hal_opamp_ex.o build/stm32l4xx_hal_spi.o build/stm32l4xx_hal_spi_ex.o build/SerialTaskSend.o build/DTW_counter.o build/CanTask.o build/can_iface.o build/canfilter_setup.o build/getserialbuf.o build/yprintf.o build/SerialTaskReceive.o build/yscanf.o build/morse.o build/payload_extract.o build/MailboxTask.o build/adctask.o build/ADCTask.o build/adcfastsum16.o build/adcparams.o build/adcparamsinit.o build/B0E00000-adc_idx_v_struct.o build/B0E00000-bq_idx_v_struct.o build/iir_f1.o build/iir_filter_lx.o build/fetonoff.o build/bqview.o build/bq_func_init.o build/bq_items.o build/chgr_items.o build/CanCommTask.o build/cancomm_items.o build/fanop.o build/bmsspi.o build/BMSTask.o build/pec15_reg.o build/bms_items.o build/rtcregs.o build/startup_stm32l431xx.o -mcpu=cortex-m4 -mthumb -mfpu=fpv4-sp-d16 -mfloat-abi=hard -u _printf_float -TSTM32L431RBTx_FLASH.ld  -lc -lm -lnosys  -Wl,-Map=build/bms1818.map,--cref -Wl,--gc-sections -o build/bms1818.elf
arm-none-eabi-size build/bms1818.elf
   text	   data	    bss	    dec	    hex	filename
  73536	   2512	  22672	  98720	  181a0	build/bms1818.elf
arm-none-eabi-objcopy -O ihex build/bms1818.elf build/bms1818.hex
arm-none-eabi-objcopy -O binary -S build/bms1818.elf build/bms1818.bin	
################ SUCCESS ##################

################# ADD CRC & CHECKSUM #################
.srec file opened read:        bms1818.srec
.bin file opened read binary:  bms1818.bin
.srec-crc file opened write:   bms1818.srec-crc
.xbin file opened write binary:bms1818.xbin
GAP:line    27 0x08008190  0x080081C0 48
BEGIN GAP GEN: 0x080081c0  0x08008180 48
LOOP  GAP GEN: 0x080081c0  0x08008198 40
LOOP  GAP GEN: 0x080081c0  0x080081a0 32
LOOP  GAP GEN: 0x080081c0  0x080081a8 24
LOOP  GAP GEN: 0x080081c0  0x080081b0 16
LOOP  GAP GEN: 0x080081c0  0x080081b8 8
REMAINDER GEN: 0x080081c0  0x080081c0 8
bufsav1: S3150801A9300000000000000000000000000000000008

Last address s3bin.addr: 0x0801A930 ct: 16 ourbinsize: 0x00012940
BIN DIFF:   400 0x00 0xff
BIN DIFF:   401 0x00 0xff
BIN DIFF:   402 0x00 0xff
BIN DIFF:   403 0x00 0xff
BIN DIFF:   404 0x00 0xff
BIN DIFF:   405 0x00 0xff
BIN DIFF:   406 0x00 0xff
BIN DIFF:   407 0x00 0xff
BIN DIFF:   408 0x00 0xff
BIN DIFF:   409 0x00 0xff
BIN DIFF:   410 0x00 0xff
BIN DIFF:   411 0x00 0xff
BIN DIFF:   412 0x00 0xff
BIN DIFF:   413 0x00 0xff
BIN DIFF:   414 0x00 0xff
BIN DIFF:   415 0x00 0xff
BIN DIFF:   416 0x00 0xff
BIN DIFF:   417 0x00 0xff
BIN DIFF:   418 0x00 0xff
BIN DIFF:   419 0x00 0xff
BIN DIFF:   420 0x00 0xff
BIN DIFF:   421 0x00 0xff
BIN DIFF:   422 0x00 0xff
BIN DIFF:   423 0x00 0xff
BIN DIFF:   424 0x00 0xff
BIN DIFF:   425 0x00 0xff
BIN DIFF:   426 0x00 0xff
BIN DIFF:   427 0x00 0xff
BIN DIFF:   428 0x00 0xff
BIN DIFF:   429 0x00 0xff
BIN DIFF:   430 0x00 0xff
BIN DIFF:   431 0x00 0xff
BIN DIFF:   432 0x00 0xff
BIN DIFF:   433 0x00 0xff
BIN DIFF:   434 0x00 0xff
BIN DIFF:   435 0x00 0xff
BIN DIFF:   436 0x00 0xff
BIN DIFF:   437 0x00 0xff
BIN DIFF:   438 0x00 0xff
BIN DIFF:   439 0x00 0xff
BIN DIFF:   440 0x00 0xff
BIN DIFF:   441 0x00 0xff
BIN DIFF:   442 0x00 0xff
BIN DIFF:   443 0x00 0xff
BIN DIFF:   444 0x00 0xff
BIN DIFF:   445 0x00 0xff
BIN DIFF:   446 0x00 0xff
BIN DIFF:   447 0x00 0xff
binfilectr : 76096 0x00012940
ourbinsize : 76096 0x00012940
ourbinsize2: 76104 0x00012948
ourbinctr  : 76096 0x00012940
 word ct*4 : 76096 binchksum : 0x89953ABF  crc2: 0x029481BC
 word ct*4 : 76104 binchksum3: 0x15BEF73B  crc3: 0xEB3EEA60
last compile S3 cnt  : 16 10
last compile S3 addr : 0x0801A930
Inserted S3 load addr: 0x0801A940
last srec3 (S7?): S7050801531589
Inserted S3 line: S30D0801A940BC819402BF3A958916
bintmp:          0D 08 01 A9 40 BC 81 94 02 BF 3A 95 89 : 16
Inserted replay:  8 0801A940 :  BC 81 94 02 BF 3A 95 89 : 16
CRC generated : 0x029481BC
CRC2generated : 0x029481BC
CRC3generated : 0xEB3EEA60
Checksum  gen : 0x89953ABF
Checksum3 gen : 0x15BEF73B
Total line ct :  4757
Total s3   ct :  4755
Line count out:  4763
Size our bin  : 76096 0x00012940
Size compile b: 76096 0x00012940
################# SAVE & MOVE FILE   #################
-rwxrwxr-x 1 deh deh 228445 Nov 30 11:01 bms1818.srec
-rw-rw-r-- 1 deh deh 228445 Nov 30 11:01 bms1818.srec-crc
-rwxrwxr-x 1 deh deh 228228 Nov 30 11:01 bms1818.srec.save
-rwxrwxr-x 1 deh deh 76096 Nov 30 11:01 bms1818.bin
-rw-rw-r-- 1 deh deh 76120 Nov 30 11:01 bms1818.xbin

########## CANldr ########## 09/08/2022
BAUDRATE is FIXED AT: 2000000 baud
argc 5
0 ./CANldr
1 127.0.0.1
2 32123
3 B0E00000
4 /home/deh/GliderWinchItems/BMS/bmsadbms1818/build/bms1818.xbin
CANnodeid: 0xB0E00000
Socket opened OK.  IP: 127.0.0.1 PORT: 32123
Xbin opened: /home/deh/GliderWinchItems/BMS/bmsadbms1818/build/bms1818.xbin
xbin_addr:     0x08008000
xbin_size:     0x00012948
xbin_crc:      0xEB3EEA60
xbin_checksum: 0x15BEF73B
xbin_in_ct   : 0x00012948 76104
fseek size   : 0x00012958
Node CRC does not match our CRC: 0x029481BC 0xEB3EEA60 retry ct: 0
Node CRC matches: 0xEB3EEA60 : 0x029481BC
#A# STATE_MSG_ADDR_RESPONSE: check msg
	0xB0E00000 8:  4,  04 00 04 00 00 08 00 00
STATE_MSG_ADDR_RESPONSE: OK. begin loading. req_size: 2048
### EOF sent. Node returned: 4 req_size: FEEDBACC bt_flag: 0x 1
xbin_in_ct: 0x00012948 76104
0
/home/deh/GliderWinchItems/BMS/bmsadbms1818
deh@ASUS:~/GliderWinchItems/BMS/bmsadbms1818$ 

=== Here is what cangate (command 'n') looks like ===
=== Note the burst of CAN msgs for B0E0 ===
 7:004 64|E2E  0|E1A  0|B0201154  0|E26  0|B02  0|B0E  0| 64  1088  0.5
 7:004 64|E2E  1|E1A  0|B0201154  0|E26  0|B02  0|B0E  0| 65  1103  0.6
 7:004 64|E2E  0|E1A  0|B0201154  0|E26  1|B02  3|B0E 569|637 18917  9.5
 7:004 64|E2E  1|E1A  1|B0201154  0|E26  1|B02  5|B0E 1367|1439 43626 21.8
 7:004 64|E2E  0|E1A  0|B0201154  0|E26  1|B02  5|B0E 1421|1491 45322 22.7
 7:004 64|E2E  1|E1A  0|B0201154  0|E26  0|B02  5|B0E 1394|1464 44411 22.2
 7:004 64|E2E  0|E1A  0|B0201154  0|E26  0|B02  4|B0E 1449|1517 46070 23.0
 7:004 64|E2E  1|E1A  0|B0201154  0|E26  0|B02  5|B0E 1423|1493 45378 22.7
 7:004 64|E2E  0|E1A  0|B0201154  0|E26  0|B02  5|B0E 1421|1490 45264 22.6
 7:004 64|E2E  1|E1A  0|B0201154  0|E26  0|B02  5|B0E 1392|1462 44380 22.2
 7:004 64|E2E  0|E1A  0|B0201154  0|E26  0|B02  3|B0E 534|601 17676  8.8
 7:004 64|E2E  1|E1A  1|B0201154  0|E26  0|B02  0|B0E  0| 66  1128  0.6
 7:004 64|E2E  0|E1A  0|B0201154  0|E26  0|B02  0|B0E  0| 64  1088  0.5
 7:004 64|E2E  1|E1A  0|B0201154  0|E26  0|B02  0|B0E  0| 65  1103  0.6
 7:004 64|E2E  0|E1A  0|B0201154  0|E26  1|B02  0|B0E  0| 65  1115  0.6

 ==== Here is what a failure looks like         ====
 ==== Notice I missed a '0' in ./cc B0E0000     ====
 ==== It did not find the .c file for B0E0000   ====
 ==== A ### TIMEOUT also happens if CAN is not "working" ====

deh@ASUS:~/GliderWinchItems/BMS/bmsadbms1818$ ./cc B0E0000
params/B0E0000-adc_idx_v_struct.c does not exist

########## CANldr ########## 09/08/2022
BAUDRATE is FIXED AT: 2000000 baud
argc 5
0 ./CANldr
1 127.0.0.1
2 32123
3 B0E0000
4 /home/deh/GliderWinchItems/BMS/bmsadbms1818/build/bms1818.xbin
CANnodeid: 0x0B0E0000
Socket opened OK.  IP: 127.0.0.1 PORT: 32123
Xbin opened: /home/deh/GliderWinchItems/BMS/bmsadbms1818/build/bms1818.xbin
xbin_addr:     0x08008000
xbin_size:     0x00012948
xbin_crc:      0xEB3EEA60
xbin_checksum: 0x15BEF73B
xbin_in_ct   : 0x00012948 76104
fseek size   : 0x00012958
### TIMEOUT: STATE_TIM_REQ_CRC_TO: retry ctr 0
### TIMEOUT: STATE_TIM_REQ_CRC_TO: retry ctr 1
### TIMEOUT: STATE_TIM_REQ_CRC_TO: retry ctr 2
249
/home/deh/GliderWinchItems/BMS/bmsadbms1818
deh@ASUS:~/GliderWinchItems/BMS/bmsadbms1818$

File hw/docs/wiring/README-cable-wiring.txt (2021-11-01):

README-cable-wiring
10/25/2021

1. Adapter RJ-45 <-> 2x5 BMS header

  2X5 keyed BMS CAN header
   1 +12v
   2 GND
   3 CAN-L
   4 CAN-H
   5 GND
   6 Master-reset
   7 +12v
   8 +12v
   9 GND
  10 nc

  RJ45
  1 carry-thru
  2 +12v
  3 +12v
  4 CAN-H
  5 CAN-L
  6 GND
  7 GND
  8 Master-reset

2. 2x5 keyed BMS header <-> DE9

Based on ribbon cable crimp to DE9

  col 1: 2x5 header pin number
  col 2: 2x5 signal name
  col 3: DE9 pin number
  col 4: DE9 standard CAN usage signal name

   1 +12v........... 1 Reserved
   2 GND............ 6 GND
   3 CAN-L.......... 2 CAN-L
   4 CAN-H.......... 7 CAN-H
   5 GND............ 3 CAN GND
   6 Master-reset... 8 Reserved
   7 +12v........... 4 Reserved
   8 +12v........... 9 CAN V+
   9 GND............ 5 CAN shield
  10 nc

3. 2x10 keyed BMS ribbon cable: 18 cell layout

col 1: 2x10 header pin number
col 2: 20 pin ribbon color
col 3: module cell number
col 4: additional description

---------TOP SPLIT-------------
 1 BLK - Current sense (to current sense op-amp)
 2 WHT - GND/Vss
 3 GRY - C2
 4 PUR - C4
 5 BLU - C6
 6 GRN - C8
 7 YEL - C10
 8 ORG - C12
 9 RED - C14
10 BRN - C16
11 BLK - C18
----------BOTTOM SPLIT ---------
12 WHT - C1
13 GRY - C3
14 PUR - C5
15 BLU - C7
16 GRN - C9
17 YEL - C11
18 ORG - C13
19 RED - C15
20 BRN - C17

4. Adapter 18 cell ribbon to 16 cell BQ BMS

col 1: 18 cell: 2x10 header pin number 18 cell layout
col 2: 18 cell: 20 pin ribbon color
col 3: 18 cell: module cell
col 4: BQ 2x10 header pin number (16 cells)
COL 5: BQ cell number

-Ribbon top split-
 1 BLK - Current  1, 3, 4
 2 WHT - GND/Vss  2
 3 GRY - C2       5 C2
 4 PUR - C4       6 C4
 5 BLU - C6       7 C6
 6 GRN - C8       8 C8
 7 YEL - C10       open
 8 ORG - C12      9 C10  
 9 RED - C14     10 C12
10 BRN - C16     11 C14
11 BLK - C18     12 C16
-Ribbon bottom split-
12 WHT - C1      13 C1
13 GRY - C3      14 C3
14 PUR - C5      15 C5
15 BLU - C7      16 C7
16 GRN - C9       open
17 YEL - C11     17 C9
18 ORG - C13     18 C11
19 RED - C15     19 C13
20 BRN - C17     20 C15

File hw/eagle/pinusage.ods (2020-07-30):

 | F405 – bmsbmsR board |  |  | 07/26/20
1 | PA00 | 14 | WAKE-UP | JP11-1 | PUSHBUTTON (PULLUP)
2 | PA01 | 15 | TIM2-CH2 | JP12-2 | BATTERY DUMP (FET|RC)
3 | PA02 | 16 | OUTPUT | LTC6813-WDT
4 | PA03 | 17 | ADC123-IN3 | JP12-2 | BATTERY DUMP CURRENT SENSE
5 | PA04 | 20 | SPI1-NSS | LTC6813-CSB
6 | PA05 | 21 | SPI1-SCK | LTC6813-SCK
7 | PA06 | 22 | SPI1-MISO | LTC6813-SDO | (W PULLUP)
8 | PA07 | 23 | SPI1-MOSI | LTC6813-
9 | PA08 | 41 | TIM1_CH1 | JP2-5 | FANGATE
10 | PA09 | 42 | USART1_TX | JP2-9 | FTDI
11 | PA10 | 43 | USART1_RX | JP2-10 | FTDI
12 | PA11 | 44 | CAN1_RX | JP2-4 | CAN-RX
13 | PA12 | 45 | CAN1_TX | JP2-3 | CAN-TX
14 | PA13 | 46 | SWDIO | JP1-29 | JTMS
15 | PA14 | 49 | SWDCK | JP1-28 | JTCK
16 | PA15 | 50 | --
17
18 | PB00 | 26 | JIC | JP10-2
19 | PB01 | 27 | TIM3CH4 | JP1-27 | FANTACH
20 | PB02 | 28 | --
21 | PB03 | 55 | --
22 | PB04 | 56 | --
23 | PB05 | 57 | CAN2-RX | U$18
24 | PB06 | 58 | CAN2-TX | U$17
25 | PB07 | 59 | I/O | U$23
26 | PB08 | 61 | TIM4CH3 | JP2-8 | CHARGER MCP1416 FET DRIVER
27 | PB09 | 62 | OUTPUT | LED | ONBOARD LED
28 | PB10 | 29 | I2C2-SCL | JP3-4 | I2C (LCD) BUS (PULLUP)
29 | PB11 | 30 | I2C2-SDA | JP3-3 | I2C (LCD) BUS (PULLUP)
30 | PB12 | 33 | I/O | U$19
31 | PB13 | 34 | I/O | U$20
32 | PB14 | 35 | I/O | U$21
33 | PB15 | 36 | I/O | U$22
34
35 | PC00 | 8 | ADC123-IN10 | 15-DIVIDED
36 | PC01 | 9 | ADC123-IN11 | BAT-DIVIDED
37 | PC02 | 10 | ADC123-IN12 | 5V-DIVIDED
38 | PC03 | 11 | ADC123-IN13 | 15V-OR-DIVIDED
39 | PC04 | 24 | JIC | JP10-3 | ADC123-IN14, PUSHBUTTON
40 | PC05 | 25 | ADC123-IN15 | 7V-DIVIDED
41 | PC06 | 37 | TIM8CH1 | Alt MCP1416 | Alternate isolated
42 | PC07 | 38 | TIM3CH2 | MCP1416-input | Isolated 12v fan
43 | PC08 | 39 | SDIO-D0 | U$27
44 | PC09 | 40 | SDIO-D1 | U$24
45 | PC10 | 51 | SDIO-D2 | JP2-7 | LED2
46 | PC11 | 52 | SDIO-D3 | JP2-6 | LED1
47 | PC12 | 53 | SDIO-CK | U$25
48 | PC13 | 2 | --
49 | PC14 | 3 | --
50 | PC15 | 4 | --
51
52 | PD2 | 54 | SDIO-CMD | U$26
53
54 | PH00 | 5 | OSC-IN | XTAL 8 MHZ
55 | PH01 | 6 | OSC-OUT | XTAL 8 MHZ
56
57 | VBAT | 1
58
59 | VDD | 64 | VCC
60 | VSS | 63 | GND
61
62 | VSS | 18 | GND
63 | VDD | 19 | VCC
64 | VDD | 48 | VCC
65 | VCAP_2 | 47 | CAP | 2.2U
66
67 | VDD | 32 | VCC
68 | VCAP_1 | 31 | CAP | 2.2U
69
70 | VSSA | 12 | GND
71 | VDDA | 13 | VCC | via BEAD
72
73 | BOOT0 | 60 | GND
74
75 | NRST | 7 | NRST | JP1-26 | MASTER-RESET, ONBOARD PUSHBUTTON

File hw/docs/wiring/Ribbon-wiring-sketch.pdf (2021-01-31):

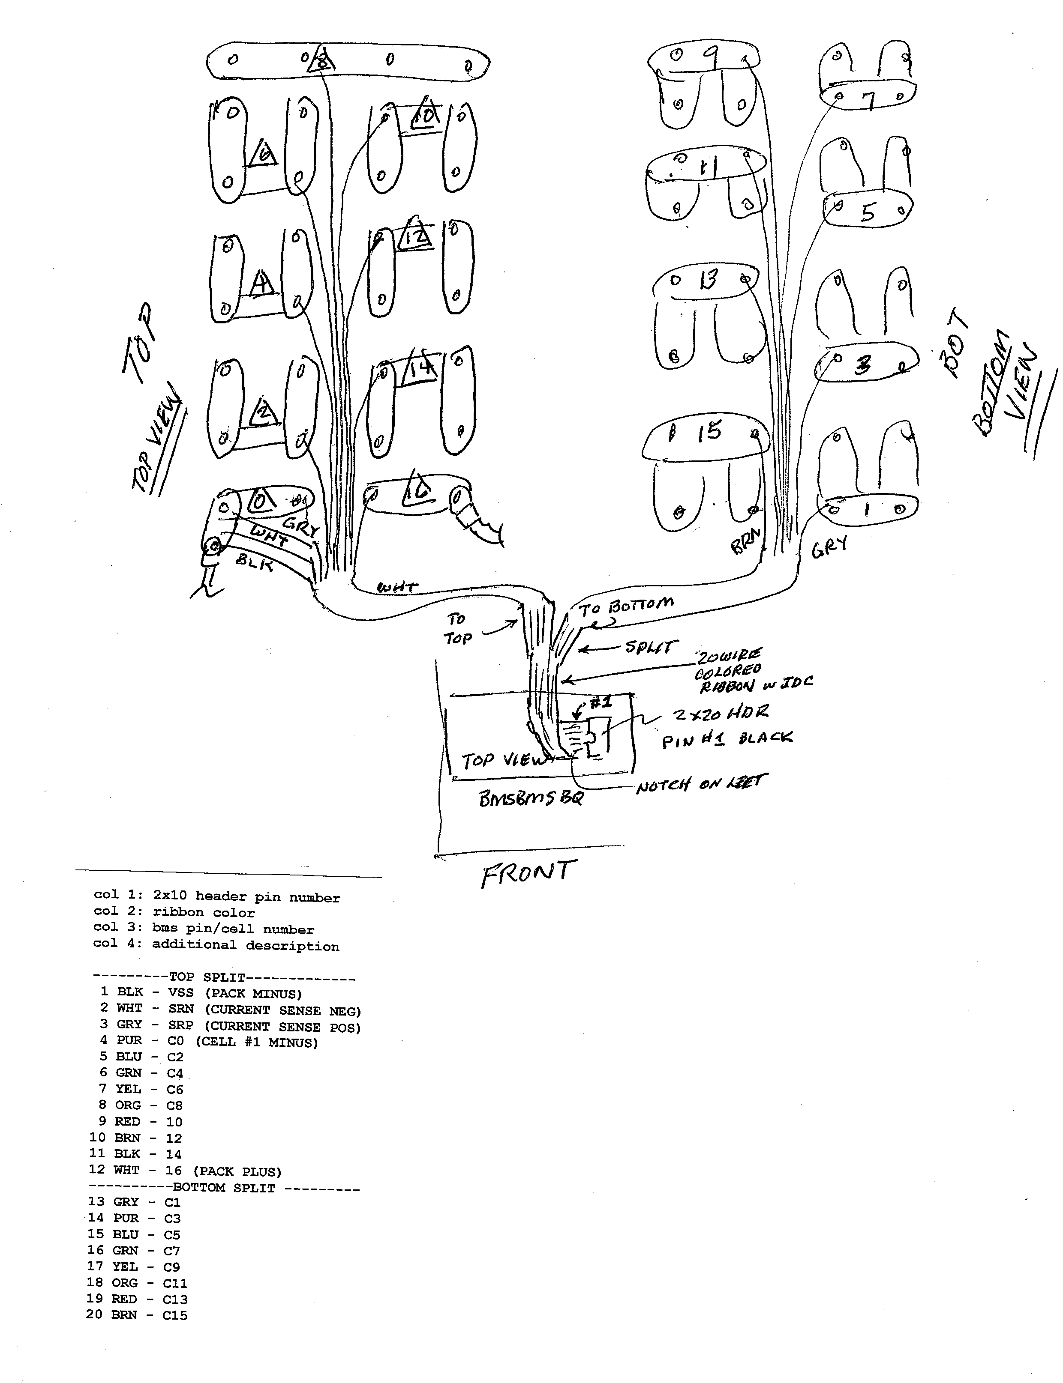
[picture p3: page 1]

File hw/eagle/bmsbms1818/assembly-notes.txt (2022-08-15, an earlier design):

assembly-notes.txt
bmsbms1818 (first version)
07/07/2022

Hardware

1. Caps
- Check shorts

2. Resistors, LEDs, small FETs
- Check shorts and bogus values

3. Regulators install
- 5v  CAN side
- 12v CAN side
- 5v   Processor side
- 3.3v Processor side
- 1.8v Processor side (VBAT)

- Check for shorts on each regulator output.

4. Install isoloated CAN if 8 pin version

DC-DC isolated convertor module covers this IC!

5. Install DC-DC convertor module

6. Install CAN bus side header

- Add two pin header JP8

7. Diodes

1N4148 (two thru)
1N4148 (one smd)

8. Check voltages 

- Jumper JP8
- Power up via ribbon, etc.
- Green LED1 should light
- DC-DC -> 15v
- Regulators (see above)

9. Small ICs & opto-isolators

74HCT02 (IC2)
MCP6006 (current sense op-amp)
MCP1416 (FET driver)
H11L1 (three opto's)

10. Add processor and ADBMS1818

- Adjacent pin short check

11. Reset pushbutton.

(Fits between the following so do it now)

12. Add thru-hole stuff
- 0.1 headers
- FAN keyed header
- Big Heater FET
- Heater source/drain lugs
- Inductor
- 1uf 100v (tickle)
- 100u 30v
- 100u 50v
- 2x10 Battery header
- 18 33 ohm resistors (underside)

13. Xtals (8 (or 16) MHz and 32.768KHz)

Software

Hacked version of the '14921 sw

1. Compiled program should load

Should run and green led flash (huzzah)
UART output to minicom should work (more huzzahs)

2. Oscillator initialization doesn't hang

- 'MX enable/disable 8 MHz xtal
- 'MX enable/disable 32.768 KHz xtal

3. Check that both LEDs work (e.g. morse_trap)

4. Check reset pushbutton

...

5. Discharge FETs

bq_items.c: Check that each S pin sets and
turns discharge FET.

code blurb about line 115

set dbgf with bit for corresponding discharge FET
 and check voltdivider pcb to see if correct cell
 volts drop and adjacent do not.

bmstask_q_readbms.setfets = (1 << dbgf);

6. External Thermistors & FAN
- Check default calibration
- Set minimum fan temp to just above ambient, e.g. in 
bq_idx_v_struct.c
p->temp_fan_min = 27.5f;

Warm up thermistors and fan should start, and get 
faster with higher temps.

line 97 in fanop.c can be uncommented to override 
the thermistor computed setting.

7. External FETs

fetonoff.c: set 'status' to turn each bit on/off and
check the board output.

8. Wake 

- Jumper JP1 with ribbon power and see if boots up

- 

08/13/2022

Build-out of two more '1818 boards

1. P-FETs

- PMV65XPVL
Vgs not sufficient (+/- 12v)

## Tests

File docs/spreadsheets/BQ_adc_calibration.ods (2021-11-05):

BQ_adc_calibration |  |  | 10/28/21 |  |  |  |  | Multiply ADC | But if | Use
 | ADC | Array |  |  |  |  |  | by this to get | summed by | This |  |  |  | ADC sample |  |  | VOM
#define index name | Chan | Index |  | R1 | R2 | Vdd |  | Calibrated volts | this factor |  | Max voltage |  |  | cycles |  |  | reading
ADC1IDX_PA3_OPA_OUT | 8 | 0 | IN8 - FET current sense R amplified | 0.1 | 0 | 3.3 | 10.00 | 8.058608E-03 | 16 | 5.036630E-04 | 33.00 | [current sense] |  | 24.5 |  | 35.035 | 59.5 | 1.6983 | 8.553717E-04
ADC1IDX_PA4_DC_DC | 9 | 1 | IN9 - DC-DC (+15v) divider | 6.8 | 33.0 | 3.30 | 5.85 | 4.716656E-03 | 16 | 2.947910E-04 | 19.31 |  |  | 47.5 |  | 15.98 | 15.03 | 0.9406 | 2.772659E-04
ADC1IDX_PA7_HV_DIV | 12 | 2 | IN12 - High voltage divider | 10.0 | 265.0 | 3.30 | 27.50 | 2.216117E-02 | 16 | 1.385073E-03 | 90.75 |  |  | 92.5 |  | 65.00 | 63.60 | 0.9785 | 1.355241E-03 | 65.1 | 63.6 | 0.9769585253 | 1.3240142E-03
ADC1IDX_PC1_FET_CUR | 2 | 3 | IN2 - FET current sense R via RC filter | 1.5 | 0 | 3.30 | 1.00 | 8.058608E-04 | 16 | 5.036630E-05 | 3.30 |  |  | 12.5
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

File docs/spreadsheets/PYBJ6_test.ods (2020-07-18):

V(supply) | Vin(0.1ohm) | V(in) | V(out) | V(1ohm) | Pwr IN | Pwr OUT | Ratio
 |  | 13.05 | 15 | 0.035
 |  |  | 15.03 | 0.04
 |  |  | 15.03 | 0.048
 |  |  | 15.03 | 0.061
 |  | 12.99 | 15.03 | 0.083
13.75 |  | 12.95 | 15.02 | 0.159
13.73 |  | 12.93 | 15.01 | 0.221
 |  |  | 14.99 | 0.542
13.67 |  | 12.85 | 15 | 0.447
 |  |  | 14.99 | 0.501
13.62 |  | 12.8 | 14.98 | 0.604
13.68 | 0.051 | 12.82 | 15.00 | 0.383 | 0.6538 | 0.5745 | 0.8787
13.68 | 0.054 | 12.82 | 15.00 | 0.400 | 0.6923 | 0.6000 | 0.8667
13.65 | 0.068 | 12.77 | 14.99 | 0.504 | 0.8684 | 0.7555 | 0.8700
13.62 | 0.083 | 12.73 | 14.98 | 0.601 | 1.0566 | 0.9003 | 0.8521
 |  |  | 14.97 | 0.615

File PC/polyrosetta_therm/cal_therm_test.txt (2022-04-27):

32.0  46061.2 45202.9 45690.7 12197.8
107.7 21662.1 21992.4 21789.4 12196.4
100.9 23554.6 23798.9 23703.7 12195.3
72.5  32383.6 32604.2 32573.4 12193.9
143.0 13841.6 13767.7 12193.1
129.9 16222.9 16386.6 16320.7 12192.9
120.7 18286.8 18455.9 18405.4 12192.8
114.5 19894.7 20082.9 20035.9 12191.6
105.7 22211.9 22415.3 22351.7 12192.7
98.8  24119.2 24321.8 24267.4 12194.8
88.3  27349.3 27563.4 27510.4 12192.7
80.4  29847.4 30058.6 30014.4 12193.5
71.9  32661.7 32907.4 32862.2 12194.4
59.1  37045.7 37246.1 37189.8 12193.7
43.7  42153.8 42365.9 42296.7 12194.8
31.7  46059.1 46263.1 46237.5 12192.4

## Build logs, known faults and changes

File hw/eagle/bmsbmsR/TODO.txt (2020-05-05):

TODO.txt
Items for f405longskinny board layout
09/02/2018

1.  TE Connectivity connector outline
    Either turn off silkscreen outlines or
    Revise connector so it doesn't extend board

2.  Mount holes
    CAN bus end may need space, i.e. lengthen board

3.  Names layers silkscreen
    Position names associated with parts

4.  Revise LM2596 dc-dc footpring
    Make part to handle the two module sizes

5.  CAN bus connector
    Current 2x5 has unused pins and shrouded header
      1x4 header with side strain relief holes?
      Lengthen board and have in/out DE9?
		Retain 2x5 and double up some pins?
      Subboard with DE9 and 2x5 for ribbon to bms board?
      
6.  PCB Dimension cleanup

7.  JIC pads on STM32
    Where space permits add pads for other uses.
    
8.  Review--

    a) STM32 power pins
       Review power pins and by-passing for
       f103,f405, and f446 options
    b) Current limits on 5->9v module and regulators

9.  SIP + SMD 5V-9V module types
    Allow for both footprints

10. Connector connection sequence
    
    1st half top, etc. rather than 1,2,3, etc.

11.  Attach point compensation
    Resistance of interconnects not equal.
    Calibration table?

12. Thermistors
    - wiring different from nodes
    - number allowed for

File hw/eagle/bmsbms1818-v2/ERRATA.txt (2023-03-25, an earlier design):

ERRATA.txt
03/22/2023

1. U$8 - 8 pin CAN driver Tx/Rx reversed

The Tx & Rx connections to the 8 pin CAN driver are reversed.

The error is in the eagle footprint and is carried over from
earlier boards that were never tested.

The original mistake was the footprint for TI ISO-1050 8 pin
isolated CAN driver. The smd pads are longer and further apart
than those on the 8 pin TI ISO-1042 (and substitute part, 
ADM3050), which are SIOC 8 packages, but they will still reach
the longer, further apart, pads for the ISO-1050 that is on
this version of the pcb.

Cutting the traces and wiring jumpers is relatively easy as
the Tx and Rx traces from the processor to the 8 pin driver
have a pair of vias at each end. The traces can be cut and
jumpers can be soldered to the vias.

This footprint error is correct on the 'V3 pcb layout. That
layout eliminates the option of installing the disharge
resistors (in the three hole configuration) so that external 
FETs are not needed. 'V3 includes the option of using SMD 
discharge resistors instead of thru-hole types.

The 16 pin CAN driver connections are corrrect for the 'V0 and 'V1
versions of this board. The V3 version corrects the 8 pin error
and also eliminates 16 pin CAN driver option.

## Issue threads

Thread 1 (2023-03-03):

Schematic diagram and PCB can't open.

xuekai1024, 2023-03-03:
Which software can I use to open the schematic diagram and PCB?

xuekai1024, 2023-03-03:
cadence and AD both can't open it

deh, 2023-03-03:
The schematic (.sch) and pcb layout (.brd) were generated by eagle. Autodesk now owns eagle. A free version can be downloaded--
https://www.autodesk.com/products/eagle/free-download
The files were generated with a paid version 4.2, but can be opened by all the later eagle versions. The pcb size is larger than the early free versions so changes cannot be made, but the latest version (v9) is based on area and the pcb falls within the limit.

xuekai1024, 2023-03-07:
> The schematic (.sch) and pcb layout (.brd) were generated by eagle. Autodesk now owns eagle. A free version can be downloaded-- https://www.autodesk.com/products/eagle/free-download The files were generated with a paid version 4.2, but can be opened by all the later eagle versions. The pcb size is larger than the early free versions so changes cannot be made, but the latest version (v9) is based on area and the pcb falls within the limit.

Ｔｈａｎｋ　ｙｏｕ　ｓｏ　ｍｕｃｈ

Closed 2023-03-07.

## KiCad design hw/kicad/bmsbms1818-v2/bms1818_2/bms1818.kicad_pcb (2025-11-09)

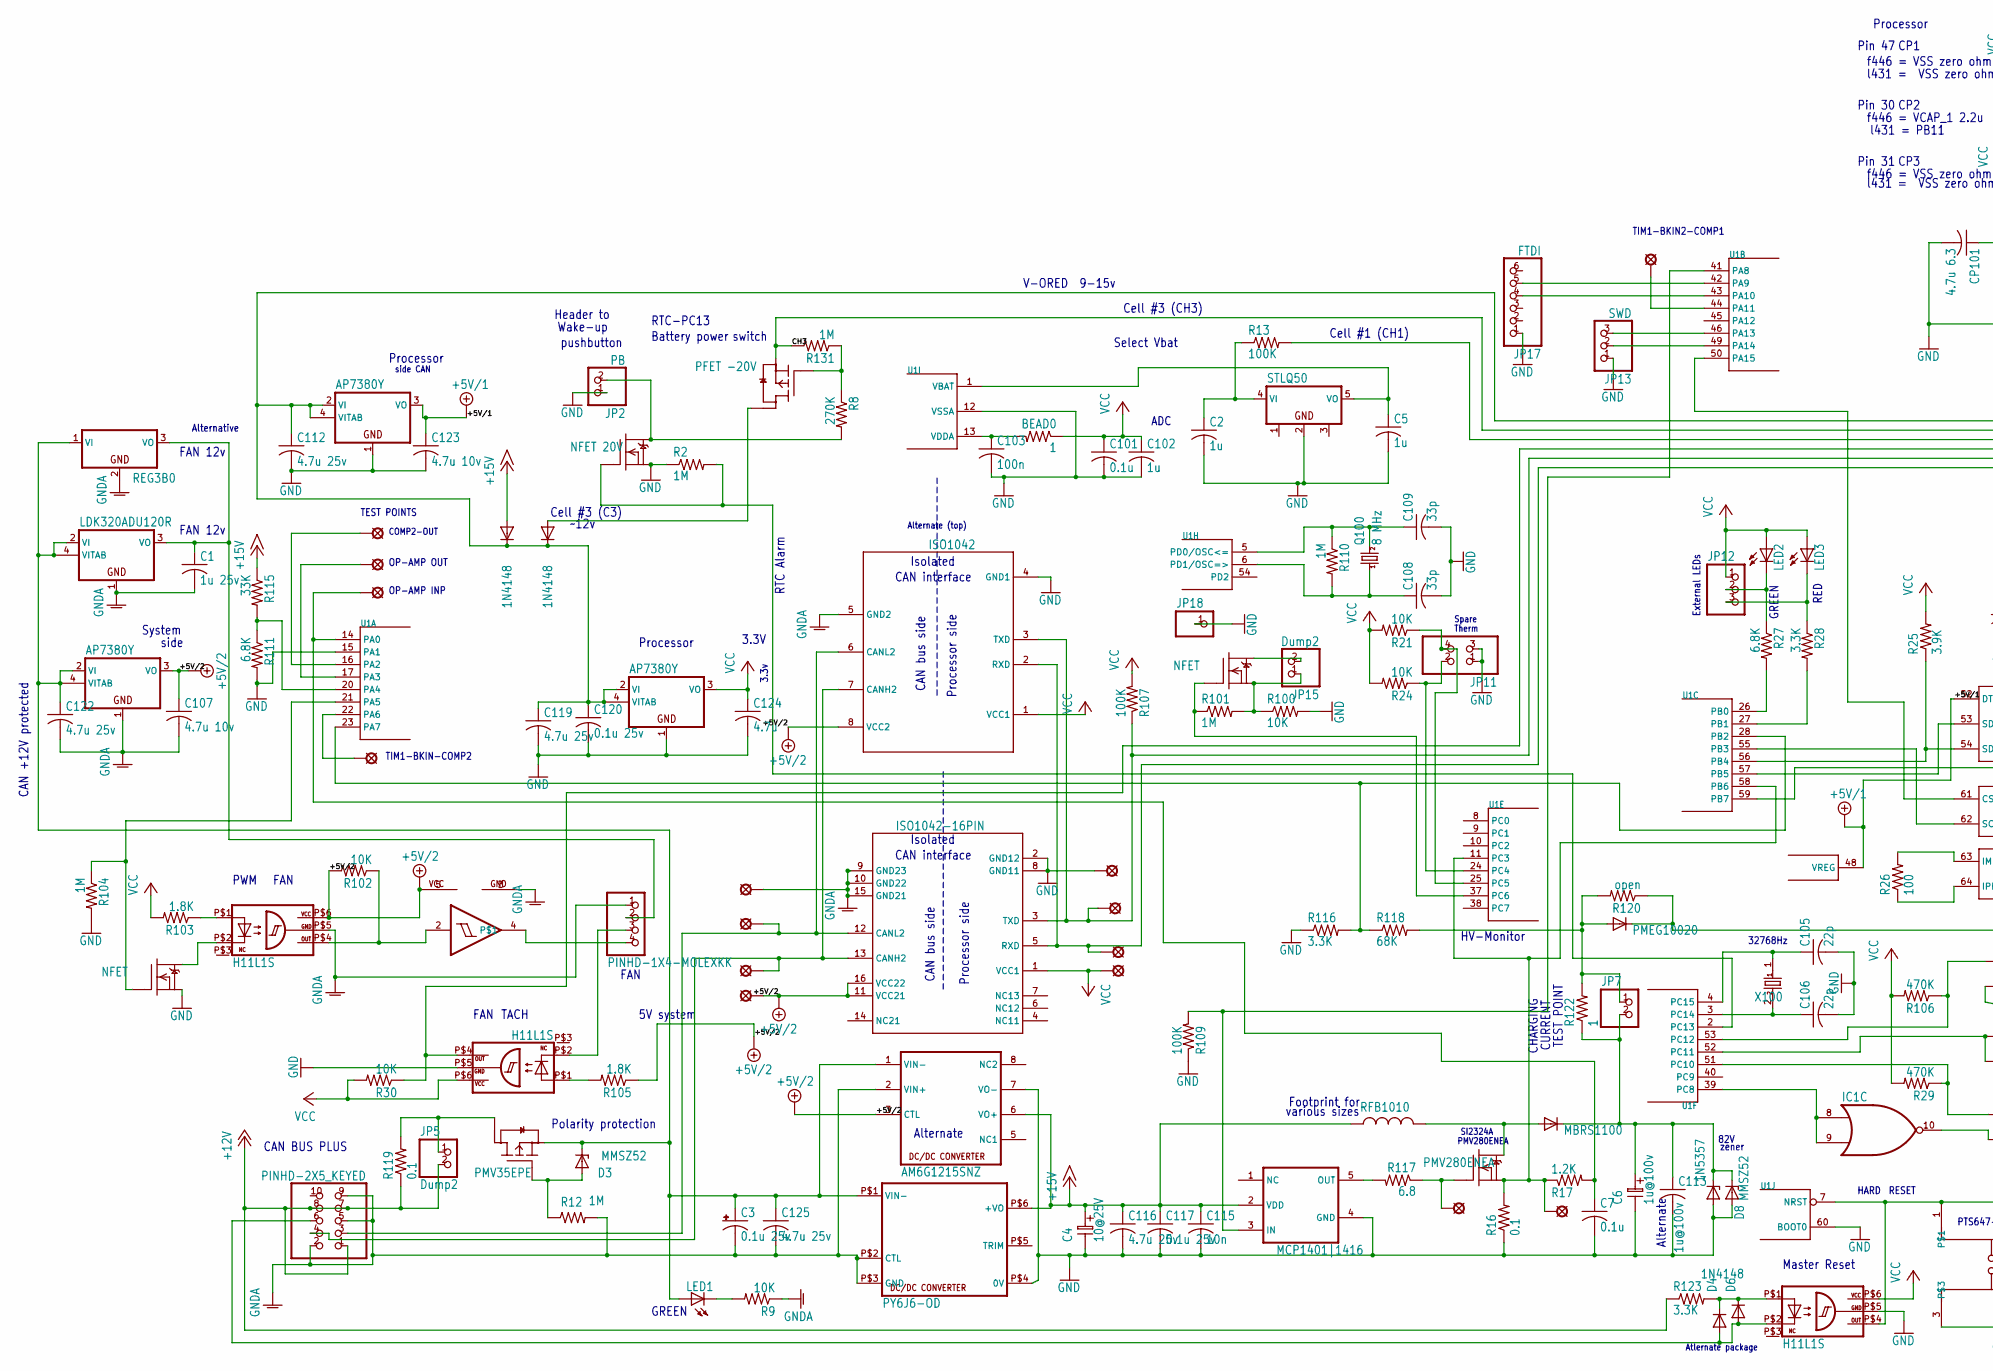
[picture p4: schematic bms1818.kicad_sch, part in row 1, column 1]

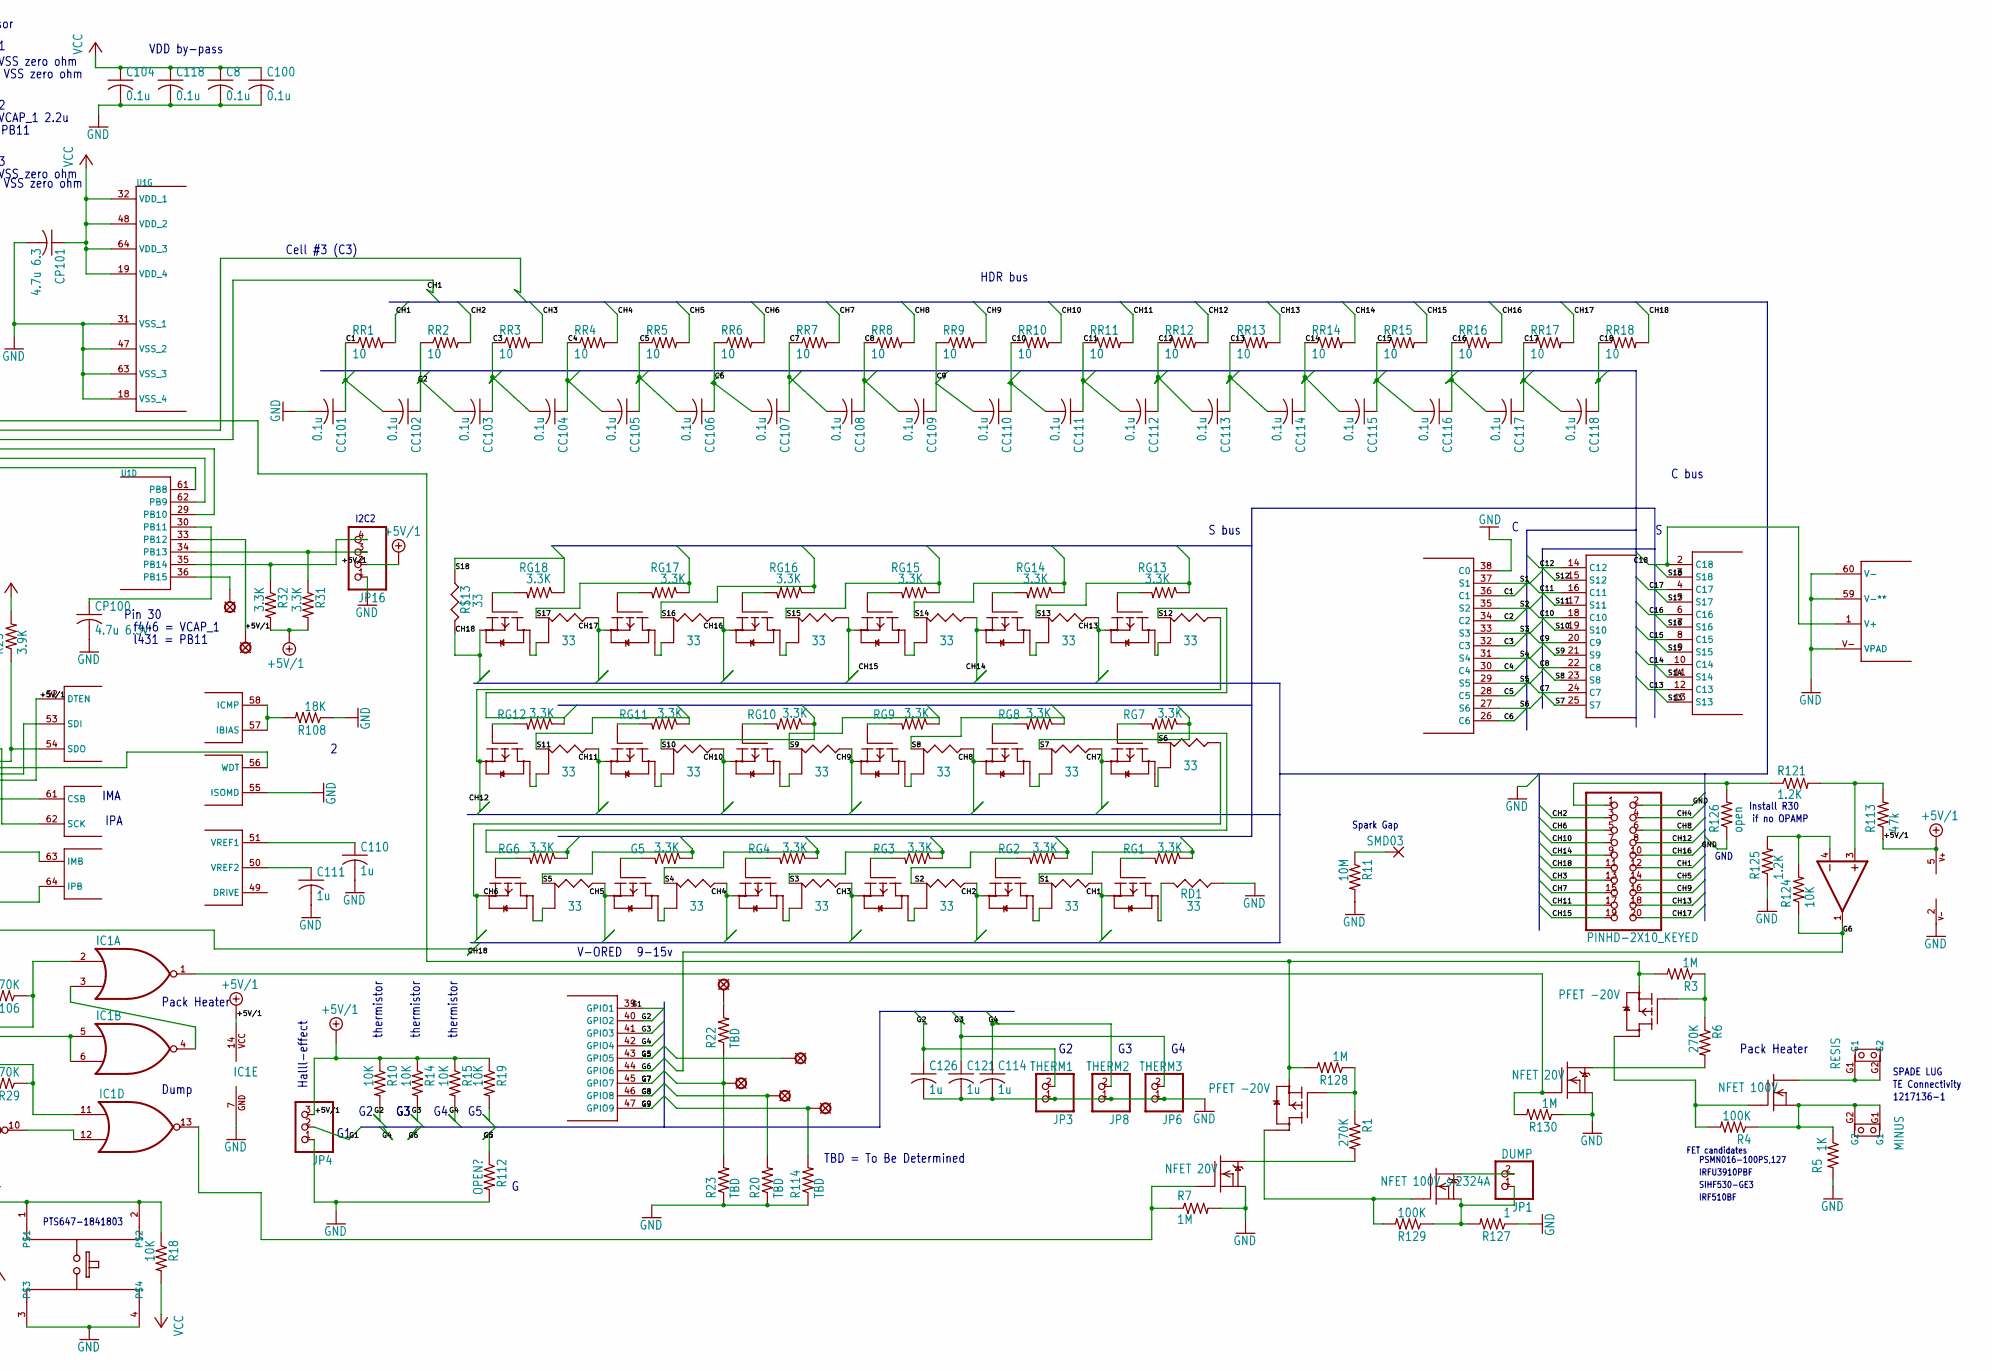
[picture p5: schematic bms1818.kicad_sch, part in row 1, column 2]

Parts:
BEAD0: 1; R0603
C1: 1u 25v; C0603
C2, C5, C102, C110, C111, C114, C121, C126: 1u; C0603
C3: 0.1u 25v; E5-8,5
C4: 10@25V; ES-2,5L
C6: 1u@100v; ES-2,5L
C7, C8, C100, C101, C104, C118: 0.1u; C0603
C103: 100n; C0603
C105, C106: 22p; C0603
C107, C123: 4.7u 10v; C0603
C108, C109: 33p; C0603
C112, C116, C119, C122, C125: 4.7u 25v; C0805
C113: 1u@100v; C1206
C115: 10n; C0603
C117, C120: 0.1u 25v; C0603
C124: 4.7u; C0603
CANH0: SOLDPAD028; SOLPAD028
CANL0: SOLDPAD028; SOLPAD028
CC101, CC102, CC103, CC104, CC105, CC106, CC107, CC108, CC109, CC110, CC111, CC112, CC113, CC114, CC115, CC116, CC117, CC118: 0.1u; C0603
CP100: 4.7u 6.3v; C0603
CP101: 4.7u 6.3; C0603
D1, D2: 1N4148; DO41-10_VERT
D3, D8: MMSZ52; SOD80C
D4: SOD323-R
D5: 1N5357; ZENER-VERT
D6: 1N4148; SOD123
D7: MBRS1100; SMB_1
D100: PMEG10020; SOD123W
F1, F2, F3, F4, F5, F6, F7, F8, F9, F10, F11, F12, F13, F14, F15, F16, F17, F18: SOT-23
FET1, FET103, FET104: PFET -20V; SOT-23
FET2, FET3, FET106: NFET 20V; SOT-23
FET4: NFET 100V; TO220V
FET5: PMV280ENEA; SOT-23
FET100, FET101: NFET; SOT-23
FET102: PMV35EPE; SOT-23
FET105: NFET 100V si2324A; SOT-23
G5: 3.3K; R0603
IC1: 7402; TSSOP14
IC1B0: AM6G1215SNZ; DCDC7PINB
IC2A0: ISO1042-16PIN; SO-16DW
IC100: 74LVC1G14; SOT-23
IC101: MCP1401|1416; SOT23-5
JP1: DUMP; 1X02
JP2: PB; 1X02
JP3: THERM1; 1X02
JP4, JP12: 1X03
JP5, JP15: Dump2; 1X02
JP6: THERM3; 1X02
JP7: 1X02
JP8: THERM2; 1X02
JP9: PINHD-2X10_KEYED; 2X10_KEYED
JP10: PINHD-2X5_KEYED; 2X05_KEYED
JP11: 2X02
JP13: SWD; 1X03
JP14: PINHD-1X4-MOLEXKK; 1X4-MOLEXKK
JP16: 1X04
JP17: FTDI; 1X06
JP18: 1X01
L1: RFB1010; INDUCTOR6.0
LED1, LED2, LED3: CHIP-LED0603
LUG-GND0: MINUS; SPADE_TAB
LUG-RES0: RESIS; SPADE_TAB
OPT1, OPT100, OPT101: H11L1S; SMD-6
Q100: 8 MHz; HC49_S
R1, R6, R8: 270K; R0603
R2, R3, R7, R12, R101, R104, R110, R128, R130, R131: 1M; R0603
R4, R13, R107, R109, R129: 100K; R0603
R5: 1K; R0603
R9, R10, R14, R15, R18, R19, R21, R24, R30, R100, R102, R124: 10K; R0603
R11: 10M; R0603
R16: 0.1; M1206
R17, R121, R125: 1.2K; R0603
R20, R22, R23, R114: TBD; R0603
R25: 3.9K; R0603
R26: 100; R0603
R27, R111: 6.8K; R0603
R28, R31, R32, R116, R123: 3.3K; R0603
R29, R106: 470K; R0603
R103, R105: 1.8K; R0603
R108: 18K; R0603
R112: OPEN?; R0603
R113: 47k; R0603
R115: 33K; R0603
R117: 6.8; R0603
R118: 68K; R0603
R119: 0.1; R0805
R120, R126: open; R0603
R122, R127: 1; R0603
R$13: 33; RS-2,5
RD1: 33; RS-2,5
RD2, RD3, RD4, RD5, RD6, RD7, RD8, RD9, RD10, RD11, RD12, RD13, RD14, RD15, RD16, RD17, RD18: 33; RS-2,5-2
REG1, REG1A0, REG100: AP7380Y; SOT89
REG3A0: LDK320ADU120R; SOT89
REG3B0: LM7812T; TO220V
RESET0: RESET; E-SWITCH2
RG1, RG2, RG3, RG4, RG6, RG7, RG8, RG9, RG10, RG11, RG12, RG13, RG14, RG15, RG16, RG17, RG18: 3.3K; R0603
RR1, RR2, RR3, RR4, RR5, RR6, RR7, RR8, RR9, RR10, RR11, RR12, RR13, RR14, RR15, RR16, RR17, RR18: 10; R0603
RXD0: SOLDPAD028; SOLPAD028
SP1: SMD03
SP2, SP3: SOLDPAD028; SOLPAD028
TP1, TP2: SOLDPAD028; SOLPAD028
TP3, TP4, TP5, TP6, TP7: SOLDPAD0.6MM; SOLPAD.6MM
TP-GND0: SOLDPAD028; SOLPAD028
TP-GNDA0: SOLDPAD028; SOLPAD028
TXD0: SOLDPAD028; SOLPAD028
U1: STM32F10XRXT6; TQFP64
U$1: STLQ50; SOT-323-5
U$2, U$3, U$4, U$6, U$7: SOLDPAD028; SOLPAD028
U$5: LTC6813; TQFP64_PAD
U$8: ISO1042; SOIC-8
U$9: PY6J6-OD; PYJ6-OD
U$100: MCP6006; SC-70-5
UNK5V1, UNK5V2: SOLDPAD028; SOLPAD028
UNK32KHZ0: X100; 32KHZ

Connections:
+5V/1: C123.1, IC1.14 (VCC), JP4.3, JP16.2, R10.1, R14.1, R15.1, R19.1, R31.2, R32.2, R113.1, REG100.3 (VO), U$5.48 (VREG), U$5.52 (DTEN), U$100.5 (V+)
+5V/2: C107.1, IC1B0.3 (CTL), IC2A0.11 (VCC21), IC2A0.16 (VCC22), IC100.5 (VCC), OPT100.P$6 (VCC), R102.2, R105.1, REG1.3 (VO), U$8.8 (VCC2), UNK5V2.MP
+12V: JP5.2, JP10.1, JP10.7, JP10.8, R119.1, R123.1
+15V: C4.1, C115.1, C116.1, C117.1, D2.A, IC1B0.6 (VO+), IC101.2 (VDD), L1.1, R115.1, U$9.P$6 (+VO)
/C1: CC101.1, CC102.2, RR1.1, U$5.36 (C1)
/C2: CC102.1, CC103.2, RR2.1, U$5.34 (C2)
/C3: CC103.1, CC104.2, RR3.1, U$5.32 (C3)
/C4: CC104.1, CC105.2, RR4.1, U$5.30 (C4)
/C5: CC105.1, CC106.2, RR5.1, U$5.28 (C5)
/C6: CC106.1, CC107.2, RR6.1, U$5.26 (C6)
/C7: CC107.1, CC108.2, RR7.1, U$5.24 (C7)
/C8: CC108.1, CC109.2, RR8.1, U$5.22 (C8)
/C9: CC109.1, CC110.2, RR9.1, U$5.20 (C9)
/C10: CC110.1, CC111.2, RR10.1, U$5.18 (C10)
/C11: CC111.1, CC112.2, RR11.1, U$5.16 (C11)
/C12: CC112.1, CC113.2, RR12.1, U$5.14 (C12)
/C13: CC113.1, CC114.2, RR13.1, U$5.12 (C13)
/C14: CC114.1, CC115.2, RR14.1, U$5.10 (C14)
/C15: CC115.1, CC116.2, RR15.1, U$5.8 (C15)
/C16: CC116.1, CC117.2, RR16.1, U$5.6 (C16)
/C17: CC117.1, CC118.2, RR17.1, U$5.4 (C17)
/C18: CC118.1, RR18.1, U$5.1 (V+), U$5.2 (C18)
/CH1: F1.2 (S), JP9.12, R13.2, RD2.1, RR1.2
/CH2: F2.2 (S), JP9.3, RD3.1, RR2.2
/CH3: F3.2 (S), FET103.2 (S), JP9.13, R131.2, RD4.1, RR3.2
/CH4: F4.2 (S), JP9.4, RD5.1, RR4.2
/CH5: F5.2 (S), JP9.14, RD6.1, RR5.2
/CH6: F6.2 (S), JP9.5, RD7.1, RR6.2
/CH7: F7.2 (S), JP9.15, RD8.1, RR7.2
/CH8: F8.2 (S), JP9.6, RD9.1, RR8.2
/CH9: F9.2 (S), JP9.16, RD10.1, RR9.2
/CH10: F10.2 (S), JP9.7, RD11.1, RR10.2
/CH11: F11.2 (S), JP9.17, RD12.1, RR11.2
/CH12: F12.2 (S), JP9.8, RD13.1, RR12.2
/CH13: F13.2 (S), JP9.18, RD14.1, RR13.2
/CH14: F14.2 (S), JP9.9, RD15.1, RR14.2
/CH15: F15.2 (S), JP9.19, RD16.1, RR15.2
/CH16: F16.2 (S), JP9.10, RD17.1, RR16.2
/CH17: F17.2 (S), JP9.20, RD18.1, RR17.2
/CH18: D100.A (C), F18.2 (S), JP9.11, R120.1, R$13.2, RR18.2
/G1: JP4.2, U$5.39 (GPIO1)
/G2: C126.1, JP3.2, R10.2, U$5.40 (GPIO2)
/G3: C121.1, JP6.2, R14.2, U$5.41 (GPIO3)
/G4: C114.1, JP8.2, R15.2, U$5.42 (GPIO4)
/G5: R112.1, U$5.43 (GPIO5)
/G6: R124.1, U$5.44 (GPIO6), U$100.1 (OUT)
/G7: U$5.45 (GPIO7)
/G8: U$5.46 (GPIO8)
/G9: U$5.47 (GPIO9)
/S1: RD2.2, RG1.1, U$5.37 (S1)
/S2: RD3.2, RG2.1, U$5.35 (S2)
/S3: RD4.2, RG3.1, U$5.33 (S3)
/S4: RD5.2, RG4.1, U$5.31 (S4)
/S5: G5.1, RD6.2, U$5.29 (S5)
/S6: RD7.2, RG6.1, U$5.27 (S6)
/S7: RD8.2, RG7.1, U$5.25 (S7)
/S8: RD9.2, RG8.1, U$5.23 (S8)
/S9: RD10.2, RG9.1, U$5.21 (S9)
/S10: RD11.2, RG10.1, U$5.19 (S10)
/S11: RD12.2, RG11.1, U$5.17 (S11)
/S12: RD13.2, RG12.1, U$5.15 (S12)
/S13: RD14.2, RG13.1, U$5.13 (S13)
/S14: RD15.2, RG14.1, U$5.11 (S14)
/S15: RD16.2, RG15.1, U$5.9 (S15)
/S16: RD17.2, RG16.1, U$5.7 (S16)
/S17: RD18.2, RG17.1, U$5.5 (S17)
/S18: R$13.1, RG18.1, U$5.3 (S18)
GND: C2.2, C4.2, C5.2, C6.2, C7.2, C8.2, C100.2, C101.2, C102.2, C103.2, C104.2, C105.2, C106.2, C108.2, C109.2, C110.2, C111.2, C112.2, C113.2, C114.2, C115.2, C116.2, C117.2, C118.2, C119.2, C120.2, C121.2, C123.2, C124.2, C126.2, CC101.2, CP100.2, CP101.2, D5.1 (A), D8.A, FET2.2 (S), FET3.2 (S), FET101.2 (S), FET106.2 (S), IC1.7 (GND), IC1B0.7 (VO-), IC2A0.2 (GND12), IC2A0.8 (GND11), IC101.4 (GND), JP2.1, JP3.1, JP4.1, JP6.1, JP8.1, JP9.2, JP11.1, JP11.3, JP13.1, JP16.1, JP17.1, JP18.1, OPT1.P$5 (GND), OPT101.P$5 (GND), R2.1, R5.2, R7.2, R11.2, R16.1, R20.1, R23.1, R100.2, R104.2, R108.1, R109.1, R111.2, R112.2, R114.1, R116.1, R125.1, R126.1, R127.1, R130.1, RD1.1, REG1A0.1 (GND), REG100.1 (GND), RESET0.3, RESET0.4, TP-GND0.MP, U1.12 (VSSA), U1.15 (PA1), U1.18 (VSS_4), U1.31 (VSS_1), U1.47 (VSS_2), U1.60 (BOOT0), U1.63 (VSS_3), U$1.2 (GND), U$5.38 (C0), U$5.55 (ISOMD), U$5.59 (V-**), U$5.60 (V-), U$5.V- (VPAD), U$8.4 (GND1), U$9.P$4 (0V), U$100.2 (V-)
GNDA: C1.2, C3.-, C107.2, C122.2, C125.2, IC1B0.2 (VIN+), IC2A0.9 (GND23), IC2A0.10 (GND22), IC2A0.15 (GND21), IC100.3 (GND), JP10.2, JP10.5, JP10.9, JP14.1, OPT100.P$5 (GND), R9.1, R12.2, REG1.1 (GND), REG3A0.1 (GND), REG3B0.2 (GND), TP-GNDA0.MP, U$8.5 (GND2), U$9.P$2 (CTL), U$9.P$3 (GND)
unnamed: C6.1, C113.1, D5.2 (C), D7.C, D8.C, JP7.2, R122.1
unnamed: D100.C (A), JP7.1, R118.2, R120.2, R122.2
unnamed: F1.3 (D), RD1.2
unnamed: F1.1 (G), RG1.2
unnamed: F2.3 (D), RD2.3
unnamed: F2.1 (G), RG2.2
unnamed: F3.3 (D), RD3.3
unnamed: F3.1 (G), RG3.2
unnamed: F4.3 (D), RD4.3
unnamed: F4.1 (G), RG4.2
unnamed: F5.3 (D), RD5.3
unnamed: F5.1 (G), G5.2
unnamed: F6.3 (D), RD6.3
unnamed: F6.1 (G), RG6.2
unnamed: F7.3 (D), RD7.3
unnamed: F7.1 (G), RG7.2
unnamed: F8.3 (D), RD8.3
unnamed: F8.1 (G), RG8.2
unnamed: F9.3 (D), RD9.3
unnamed: F9.1 (G), RG9.2
unnamed: F10.3 (D), RD10.3
unnamed: F10.1 (G), RG10.2
unnamed: F11.3 (D), RD11.3
unnamed: F11.1 (G), RG11.2
unnamed: F12.3 (D), RD12.3
unnamed: F12.1 (G), RG12.2
unnamed: F13.3 (D), RD13.3
unnamed: F13.1 (G), RG13.2
unnamed: F14.3 (D), RD14.3
unnamed: F14.1 (G), RG14.2
unnamed: F15.3 (D), RD15.3
unnamed: F15.1 (G), RG15.2
unnamed: F16.3 (D), RD16.3
unnamed: F16.1 (G), RG16.2
unnamed: F17.3 (D), RD17.3
unnamed: F17.1 (G), RG17.2
unnamed: F18.3 (D), RD18.3
unnamed: F18.1 (G), RG18.2
unnamed: FET1.3 (D), FET4.1 (G), R4.2
unnamed: FET1.1 (G), R3.1, R6.1
unnamed: C112.1, C119.1, C120.1, D1.C, D2.C, FET1.2 (S), FET104.2 (S), R3.2, R128.2, REG1A0.2 (VI), REG1A0.4 (VITAB), REG100.2 (VI), REG100.4 (VITAB)
unnamed: FET2.3 (D), R1.2
unnamed: FET2.1 (G), IC1.13 (O), R7.1
unnamed: FET3.3 (D), JP2.2, R8.2
unnamed: FET3.1 (G), R2.2, U1.2 (PC13)
unnamed: FET4.2 (D), LUG-RES0.G1, LUG-RES0.G2
unnamed: FET4.3 (S), LUG-GND0.G1, LUG-GND0.G2, R4.1, R5.1
unnamed: D7.A, FET5.3 (D), L1.2
unnamed: FET5.1 (G), R117.1, TP1.MP
unnamed: FET5.2 (S), R16.2, R17.1, TP2.MP, U1.11 (PC3), U1.58 (PB6)
unnamed: FET100.3 (D), JP15.2
unnamed: FET100.1 (G), R101.1, U1.37 (PC6)
unnamed: FET100.2 (S), JP15.1, R100.1, R101.2
unnamed: FET101.3 (D), OPT100.P$2 (C)
unnamed: FET101.1 (G), R104.1, U1.21 (PA5)
unnamed: FET102.3 (D), JP5.1, R119.2
unnamed: D3.A, FET102.1 (G), R12.1
unnamed: C3.+, C122.1, C125.1, D3.C, FET102.2 (S), IC1B0.1 (VIN-), LED1.A, REG1.2 (VI), REG1.4 (VITAB), REG3A0.2 (VI), REG3A0.4 (VITAB), REG3B0.1 (VI), U$9.P$1 (VIN-)
unnamed: D1.A, FET103.3 (D)
unnamed: FET103.1 (G), R8.1, R131.1
unnamed: FET104.3 (D), FET105.1 (G), R129.2
unnamed: FET104.1 (G), R1.1, R128.1
unnamed: FET105.3 (D), JP1.2
unnamed: FET105.2 (S), JP1.1, R127.2, R129.1
unnamed: FET106.3 (D), R6.2
unnamed: FET106.1 (G), IC1.1 (O), R130.2
unnamed: IC1.2 (I0), R106.1, U1.53 (PC12)
unnamed: IC1.3 (I1), IC1.4 (O)
unnamed: IC1.5 (I0), IC1.6 (I1), U1.52 (PC11)
unnamed: IC1.8 (I0), IC1.9 (I1), U1.39 (PC8)
unnamed: IC1.10 (O), IC1.12 (I1)
unnamed: IC1.11 (I0), R29.1, U1.51 (PC10)
unnamed: CANH0.MP, IC2A0.13 (CANH2), JP10.4, U$8.7 (CANH2)
unnamed: CANL0.MP, IC2A0.12 (CANL2), JP10.3, U$8.6 (CANL2)
unnamed: IC2A0.5 (RXD), RXD0.MP, U1.61 (PB8), U$8.2 (RXD)
unnamed: IC2A0.3 (TXD), R107.1, TXD0.MP, U1.62 (PB9), U$8.3 (TXD)
unnamed: IC100.2 (I), OPT100.P$4 (OUT), R102.1
unnamed: IC100.4, JP14.4
unnamed: IC101.3 (IN), R109.2, U1.41 (PA8)
unnamed: IC101.5 (OUT), R117.2
unnamed: JP9.1, R121.1, R126.2
unnamed: JP12.2, LED2.C, R27.1
unnamed: JP12.3, LED3.C, R28.1
unnamed: LED1.C, R9.2
unnamed: OPT1.P$1 (A), R105.2
unnamed: JP14.3, OPT1.P$2 (C)
unnamed: OPT1.P$4 (OUT), R30.1, U1.29 (PB10)
unnamed: OPT100.P$1 (A), R103.1
unnamed: D4.C, D6.C, OPT101.P$1 (A), R123.2
unnamed: D4.A, D6.A, JP10.6, OPT101.P$2 (C)
unnamed: OPT101.P$4 (OUT), R18.1, RESET0.1, RESET0.2, U1.7 (NRST)
unnamed: R20.2, U$3.MP
unnamed: R22.1, R23.2, U$7.MP
unnamed: R22.2, U$6.MP
unnamed: R114.2, U$2.MP
unnamed: C1.1, JP14.2, REG3A0.3 (VO), REG3B0.3 (VO)
unnamed: R11.1, SP1.1
unnamed: C7.1, R17.2, TP3.MP, U1.14 (PA0)
unnamed: TP4.MP, U1.16 (PA2)
unnamed: TP5.MP, U1.17 (PA3)
unnamed: R111.1, R115.2, U1.20 (PA4)
unnamed: TP6.MP, U1.22 (PA6)
unnamed: R116.2, R118.1, U1.23 (PA7), U1.28 (PB2)
unnamed: JP17.5, U1.42 (PA9)
unnamed: JP17.4, U1.43 (PA10)
unnamed: TP7.MP, U1.44 (PA11)
unnamed: JP13.3, U1.46 (PA13)
unnamed: JP13.2, U1.49 (PA14)
unnamed: R27.2, U1.26 (PB0)
unnamed: R28.2, U1.27 (PB1)
unnamed: CP100.1, U1.30 (PB11)
unnamed: SP2.MP, U1.33 (PB12)
unnamed: JP16.3, R31.1, U1.34 (PB13)
unnamed: JP16.4, R32.1, U1.35 (PB14)
unnamed: SP3.MP, U1.36 (PB15)
unnamed: JP11.2, R24.1, U1.24 (PC4)
unnamed: JP11.4, R21.1, U1.25 (PC5)
unnamed: C106.1, U1.3 (PC14), UNK32KHZ0.2
unnamed: C105.1, U1.4 (PC15), UNK32KHZ0.1
unnamed: C109.1, Q100.2, R110.1, U1.5 (PD0/OSC<=)
unnamed: C108.1, Q100.1, R110.2, U1.6 (PD1/OSC=>)
unnamed: BEAD0.2, C103.1, U1.13 (VDDA)
unnamed: C2.1, R13.1, U$1.4 (VI)
unnamed: C5.1, U1.1 (VBAT), U$1.5 (VO)
unnamed: R108.2, U$5.57 (IBIAS), U$5.58 (ICMP)
unnamed: C110.1, U$5.51 (VREF1)
unnamed: C111.1, U$5.50 (VREF2)
unnamed: U1.59 (PB7), U$5.56 (WDT)
unnamed: U1.50 (PA15), U$5.61 (CSB)
unnamed: R26.2, U$5.63 (IMB)
unnamed: R26.1, U$5.64 (IPB)
unnamed: U1.55 (PB3), U$5.62 (SCK)
unnamed: U1.57 (PB5), U$5.53 (SDI)
unnamed: R25.1, U1.56 (PB4), U$5.54 (SDO)
unnamed: R113.2, R121.2, U$100.3 (+IN)
unnamed: R124.2, R125.2, U$100.4 (-IN)
VCC: BEAD0.1, C8.1, C100.1, C101.1, C102.1, C104.1, C118.1, C124.1, CP101.1, IC2A0.1 (VCC1), JP12.1, LED2.A, LED3.A, OPT1.P$6 (VCC), OPT101.P$6 (VCC), R18.2, R21.2, R24.2, R25.2, R29.2, R30.2, R103.2, R106.2, R107.2, REG1A0.3 (VO), U1.19 (VDD_4), U1.32 (VDD_1), U1.48 (VDD_2), U1.64 (VDD_3), U$8.1 (VCC1), UNK5V1.MP

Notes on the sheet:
FAN 12v
GREEN
CP3
IPA
SPADE LUG
Header to
OP-AMP INP
COMP2-OUT
S bus
PTS647-1841803
Spare
Polarity protection
CP2
zener
PSMN016-100PS,127
l431 = PB11
Spark Gap
TEST POINTS
RTC Alarm
FAN
Pin 47
CAN +12V protected
Alternative
V-ORED
thermistor
f446 = VSS zero ohm
f446 = VCAP_1
Halll-effect
CURRENT
Alternate (top)
Cell #3 (CH3)
GND
PWM
Processor
switch
RESET
Isolated
Atlernate package
1217136-1
Alternate

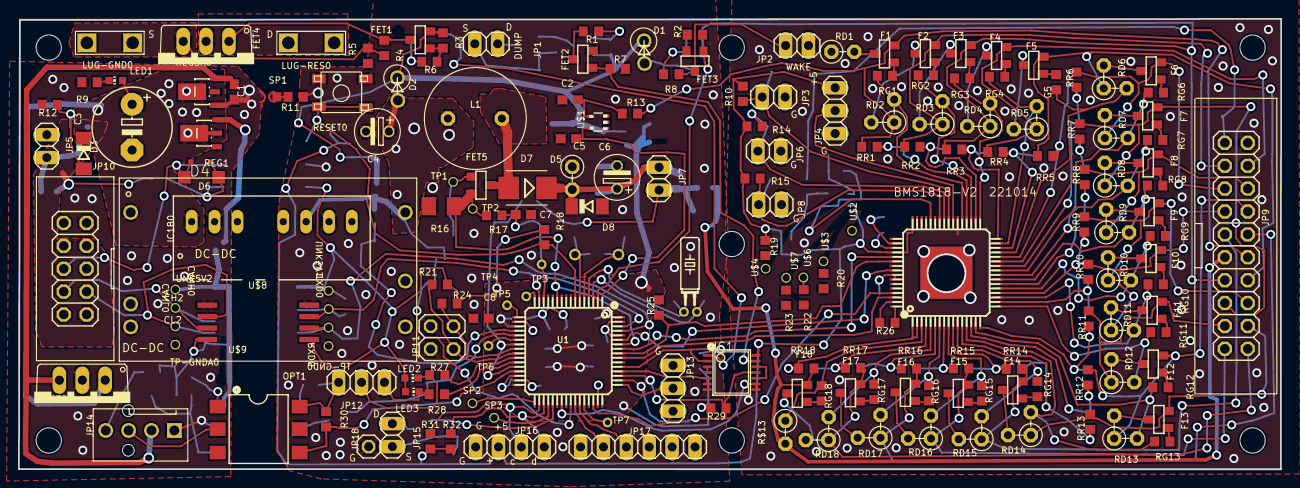
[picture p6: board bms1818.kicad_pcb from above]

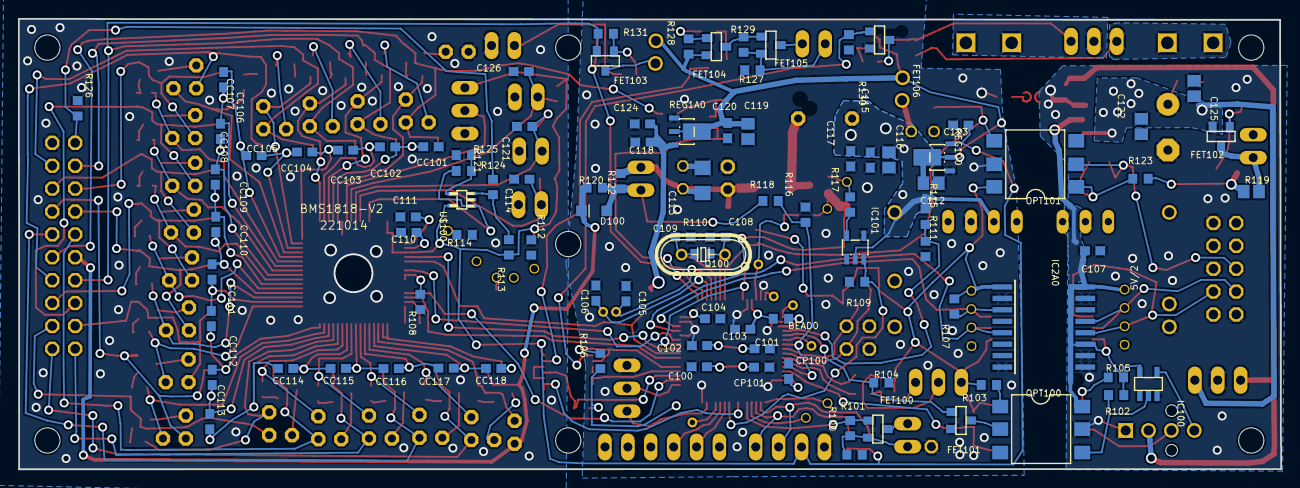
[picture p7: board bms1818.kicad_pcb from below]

Board: 2 copper layers, 140.1 x 50.0 mm, 290 parts (97 on the bottom side), 203 nets.

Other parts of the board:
@HOLE0, @HOLE1, @HOLE2, @HOLE3, @HOLE4, @HOLE5, @HOLE6: (no value)

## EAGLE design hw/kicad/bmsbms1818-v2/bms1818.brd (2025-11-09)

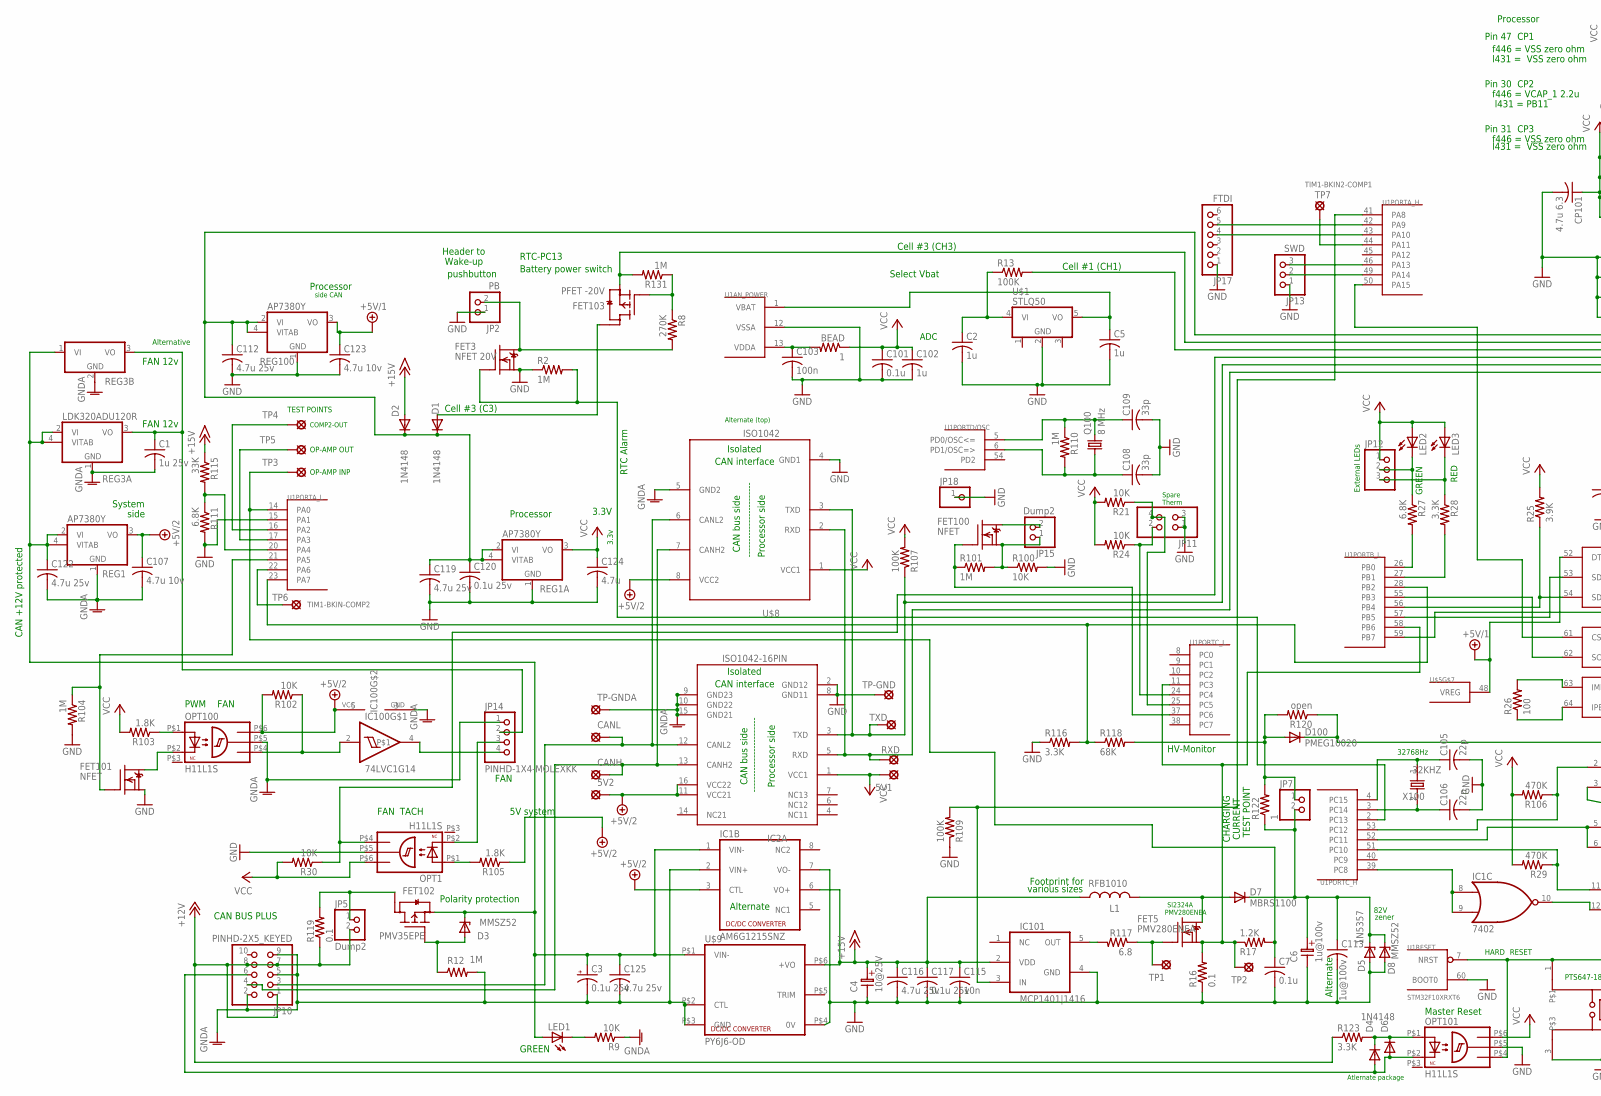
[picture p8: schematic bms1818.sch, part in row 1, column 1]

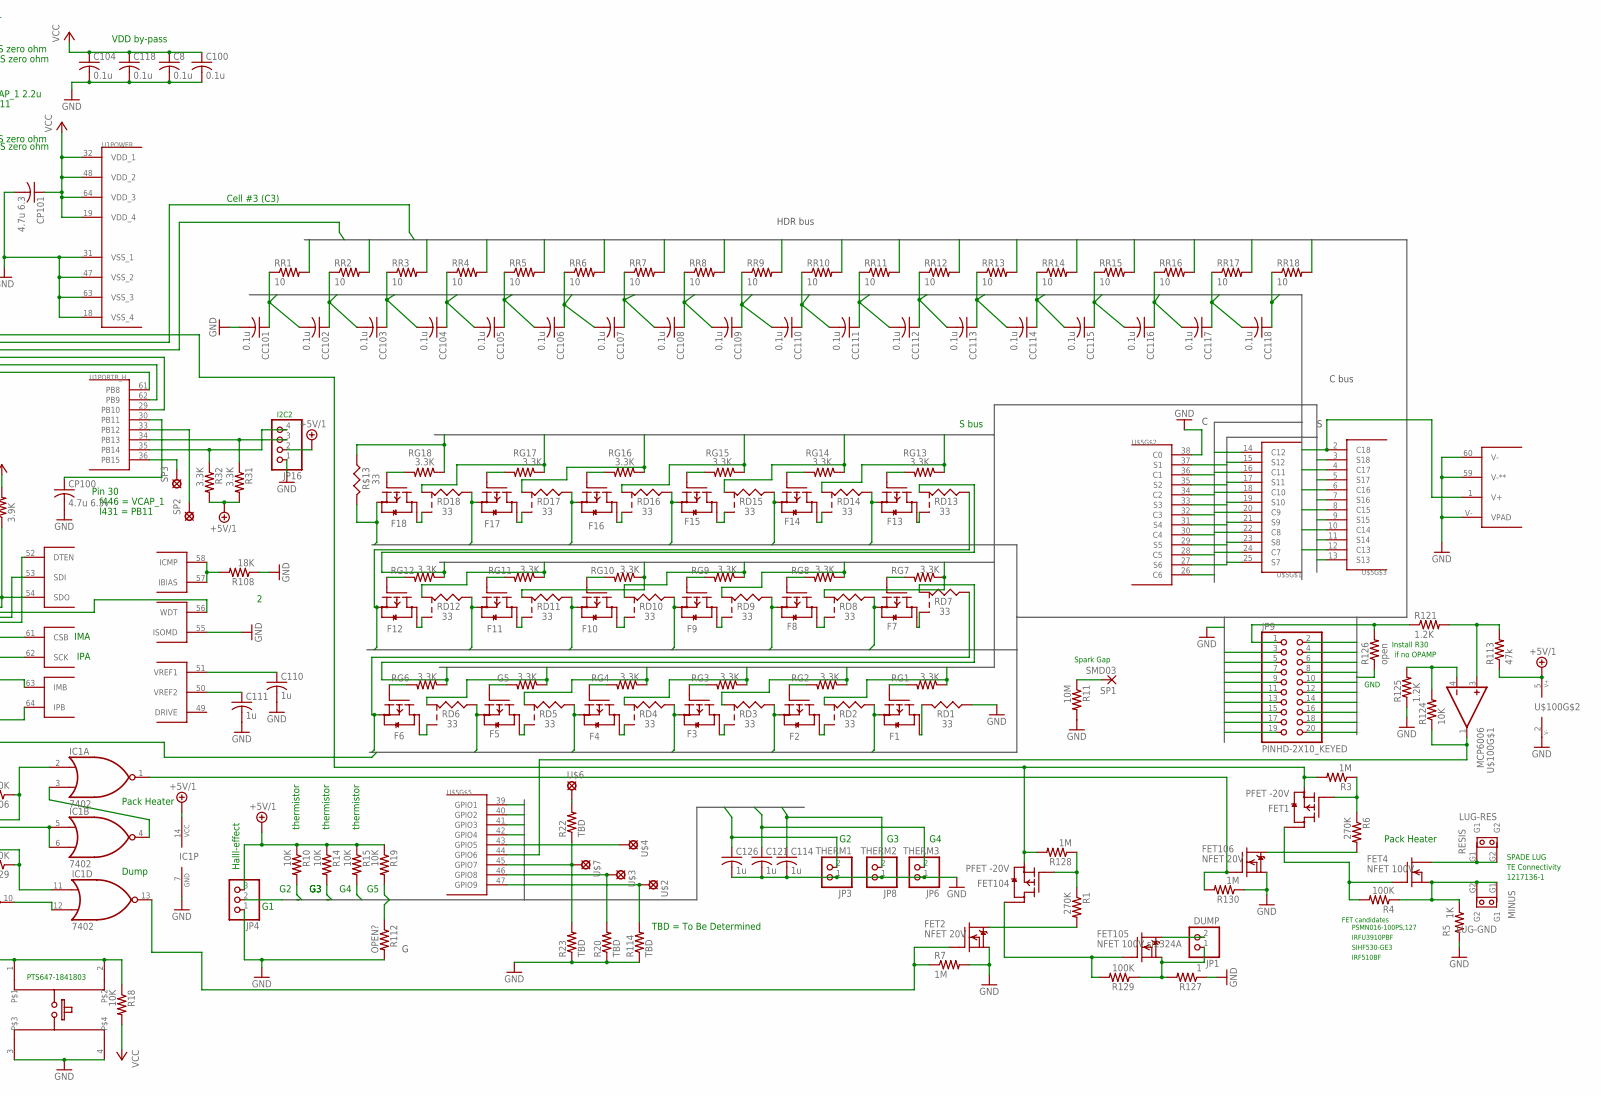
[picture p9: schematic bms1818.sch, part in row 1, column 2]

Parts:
5V1, 5V2: SOLDPAD028; SOLPAD028
32KHZ: X100; 32KHZ
BEAD: 1; R0603
C1: 1u 25v; C0603
C2, C5, C102, C110, C111, C114, C121, C126: 1u; C0603
C3: 0.1u 25v; E5-8,5
C4: 10@25V; ES-2,5L
C6: 1u@100v; ES-2,5L
C7, C8, C100, C101, C104, C118: 0.1u; C0603
C103: 100n; C0603
C105, C106: 22p; C0603
C107, C123: 4.7u 10v; C0603
C108, C109: 33p; C0603
C112, C116, C119, C122, C125: 4.7u 25v; C0805
C113: 1u@100v; C1206
C115: 10n; C0603
C117, C120: 0.1u 25v; C0603
C124: 4.7u; C0603
CANH: SOLDPAD028; SOLPAD028
CANL: SOLDPAD028; SOLPAD028
CC101, CC102, CC103, CC104, CC105, CC106, CC107, CC108, CC109, CC110, CC111, CC112, CC113, CC114, CC115, CC116, CC117, CC118: 0.1u; C0603
CP100: 4.7u 6.3v; C0603
CP101: 4.7u 6.3; C0603
D1, D2: 1N4148; DO41-10_VERT
D3, D8: MMSZ52; SOD80C
D4: DIODE-SOD323-R; SOD323-R
D5: 1N5357; ZENER-VERT
D6: 1N4148; SOD123
D7: MBRS1100; SMB_1
D100: PMEG10020; SOD123W
F1, F2, F3, F4, F5, F6, F7, F8, F9, F10, F11, F12, F13, F14, F15, F16, F17, F18: FET-P-SOT23; SOT-23
FET1, FET103, FET104: PFET -20V; SOT-23
FET2, FET3, FET106: NFET 20V; SOT-23
FET4: NFET 100V; TO220V
FET5: PMV280ENEA; SOT-23
FET100, FET101: NFET; SOT-23
FET102: PMV35EPE; SOT-23
FET105: NFET 100V si2324A; SOT-23
G5: 3.3K; R0603
IC1: 7402; TSSOP14
IC1B: AM6G1215SNZ; DCDC7PINB
IC2A: ISO1042-16PIN; SO-16DW
IC100: 74LVC1G14; SOT-23
IC101: MCP1401|1416; SOT23-5
JP1: DUMP; 1X02
JP2: PB; 1X02
JP3: THERM1; 1X02
JP4, JP12: PINHD-1X3; 1X03
JP5, JP15: Dump2; 1X02
JP6: THERM3; 1X02
JP7: PINHD-1X2; 1X02
JP8: THERM2; 1X02
JP9: PINHD-2X10_KEYED; 2X10_KEYED
JP10: PINHD-2X5_KEYED; 2X05_KEYED
JP11: PINHD-2X2; 2X02
JP13: SWD; 1X03
JP14: PINHD-1X4-MOLEXKK; 1X4-MOLEXKK
JP16: PINHD-1X4; 1X04
JP17: FTDI; 1X06
JP18: PINHD-1X1; 1X01
L1: RFB1010; INDUCTOR6.0
LED1, LED2, LED3: LEDCHIP-LED0603; CHIP-LED0603
LUG-GND: MINUS; SPADE_TAB
LUG-RES: RESIS; SPADE_TAB
OPT1, OPT100, OPT101: H11L1S; SMD-6
Q100: 8 MHz; HC49/S
R1, R6, R8: 270K; R0603
R2, R3, R7, R12, R101, R104, R110, R128, R130, R131: 1M; R0603
R4, R13, R107, R109, R129: 100K; R0603
R5: 1K; R0603
R9, R10, R14, R15, R18, R19, R21, R24, R30, R100, R102, R124: 10K; R0603
R11: 10M; R0603
R16: 0.1; M1206
R17, R121, R125: 1.2K; R0603
R20, R22, R23, R114: TBD; R0603
R25: 3.9K; R0603
R26: 100; R0603
R27, R111: 6.8K; R0603
R28, R31, R32, R116, R123: 3.3K; R0603
R29, R106: 470K; R0603
R103, R105: 1.8K; R0603
R108: 18K; R0603
R112: OPEN?; R0603
R113: 47k; R0603
R115: 33K; R0603
R117: 6.8; R0603
R118: 68K; R0603
R119: 0.1; R0805
R120, R126: open; R0603
R122, R127: 1; R0603
R$13: 33; RS-2,5
RD1: 33; RS-2,5
RD2, RD3, RD4, RD5, RD6, RD7, RD8, RD9, RD10, RD11, RD12, RD13, RD14, RD15, RD16, RD17, RD18: 33; RS-2,5-2
REG1, REG1A, REG100: AP7380Y; SOT89
REG3A: LDK320ADU120R; SOT89
REG3B: LM7812T; TO220V
RESET: RESET; E-SWITCH2
RG1, RG2, RG3, RG4, RG6, RG7, RG8, RG9, RG10, RG11, RG12, RG13, RG14, RG15, RG16, RG17, RG18: 3.3K; R0603
RR1, RR2, RR3, RR4, RR5, RR6, RR7, RR8, RR9, RR10, RR11, RR12, RR13, RR14, RR15, RR16, RR17, RR18: 10; R0603
RXD: SOLDPAD028; SOLPAD028
SP1: SMD03
SP2, SP3: SOLDPAD028; SOLPAD028
TP1, TP2: SOLDPAD028; SOLPAD028
TP3, TP4, TP5, TP6, TP7: SOLDPAD0.6MM; SOLPAD.6MM
TP-GND: SOLDPAD028; SOLPAD028
TP-GNDA: SOLDPAD028; SOLPAD028
TXD: SOLDPAD028; SOLPAD028
U1: STM32F10XRXT6; TQFP64
U$1: STLQ50; SOT-323-5
U$2, U$3, U$4, U$6, U$7: SOLDPAD028; SOLPAD028
U$5: LTC6813; TQFP64_PAD
U$8: ISO1042; SOIC-8
U$9: PY6J6-OD; PYJ6-OD
U$100: MCP6006; SC-70-5

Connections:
12V-R: FET102.3 (D), JP5.1, R119.2
+5V/1: C123.1, IC1.14 (VCC), JP4.3, JP16.2, R10.1, R14.1, R15.1, R19.1, R31.2, R32.2, R113.1, REG100.3 (VO), U$5.48 (VREG), U$5.52 (DTEN), U$100.5 (V+)
+5V/2: 5V2.MP, C107.1, IC1B.3 (CTL), IC2A.11 (VCC21), IC2A.16 (VCC22), IC100.5 (VCC), OPT100.P$6 (VCC), R102.2, R105.1, REG1.3 (VO), U$8.8 (VCC2)
+12V: JP5.2, JP10.1, JP10.7, JP10.8, R119.1, R123.1
+15V: C4.1, C115.1, C116.1, C117.1, D2.A, IC1B.6 (VO+), IC101.2 (VDD), L1.1, R115.1, U$9.P$6 (+VO)
/PC10: IC1.3 (I1), IC1.4 (O)
BATSW-NDRAIN: FET3.3 (D), JP2.2, R8.2
BATSW-NDRAIN1: FET2.3 (D), R1.2
BATSW-NDRAIN2: FET106.3 (D), R6.2
BATSW-PGATE: FET103.1 (G), R8.1, R131.1
BATSW-PGATE1: FET104.1 (G), R1.1, R128.1
BATSW-PGATE2: FET1.1 (G), R3.1, R6.1
BIGFET-DRAIN: FET4.2 (D), LUG-RES.G1, LUG-RES.G2
BIGFET-GATE: FET1.3 (D), FET4.1 (G), R4.2
BIGFET-SOURCE: FET4.3 (S), LUG-GND.G1, LUG-GND.G2, R4.1, R5.1
C1: CC101.1, CC102.2, RR1.1, U$5.36 (C1)
C2: CC102.1, CC103.2, RR2.1, U$5.34 (C2)
C3: CC103.1, CC104.2, RR3.1, U$5.32 (C3)
C4: CC104.1, CC105.2, RR4.1, U$5.30 (C4)
C5: CC105.1, CC106.2, RR5.1, U$5.28 (C5)
C6: CC106.1, CC107.2, RR6.1, U$5.26 (C6)
C7: CC107.1, CC108.2, RR7.1, U$5.24 (C7)
C8: CC108.1, CC109.2, RR8.1, U$5.22 (C8)
C9: CC109.1, CC110.2, RR9.1, U$5.20 (C9)
C10: CC110.1, CC111.2, RR10.1, U$5.18 (C10)
C11: CC111.1, CC112.2, RR11.1, U$5.16 (C11)
C12: CC112.1, CC113.2, RR12.1, U$5.14 (C12)
C13: CC113.1, CC114.2, RR13.1, U$5.12 (C13)
C14: CC114.1, CC115.2, RR14.1, U$5.10 (C14)
C15: CC115.1, CC116.2, RR15.1, U$5.8 (C15)
C16: CC116.1, CC117.2, RR16.1, U$5.6 (C16)
C17: CC117.1, CC118.2, RR17.1, U$5.4 (C17)
C18: CC118.1, RR18.1, U$5.1 (V+), U$5.2 (C18)
CAN+12PRO: C3.+, C122.1, C125.1, D3.C, FET102.2 (S), IC1B.1 (VIN-), LED1.A, REG1.2 (VI), REG1.4 (VITAB), REG3A.2 (VI), REG3A.4 (VITAB), REG3B.1 (VI), U$9.P$1 (VIN-)
CANH2: CANH.MP, IC2A.13 (CANH2), JP10.4, U$8.7 (CANH2)
CANL2: CANL.MP, IC2A.12 (CANL2), JP10.3, U$8.6 (CANL2)
CELL1-PFET-DRAIN: D1.A, FET103.3 (D)
CH1: F1.2 (S), JP9.12, R13.2, RD2.1, RR1.2
CH2: F2.2 (S), JP9.3, RD3.1, RR2.2
CH3: F3.2 (S), FET103.2 (S), JP9.13, R131.2, RD4.1, RR3.2
CH4: F4.2 (S), JP9.4, RD5.1, RR4.2
CH5: F5.2 (S), JP9.14, RD6.1, RR5.2
CH6: F6.2 (S), JP9.5, RD7.1, RR6.2
CH7: F7.2 (S), JP9.15, RD8.1, RR7.2
CH8: F8.2 (S), JP9.6, RD9.1, RR8.2
CH9: F9.2 (S), JP9.16, RD10.1, RR9.2
CH10: F10.2 (S), JP9.7, RD11.1, RR10.2
CH11: F11.2 (S), JP9.17, RD12.1, RR11.2
CH12: F12.2 (S), JP9.8, RD13.1, RR12.2
CH13: F13.2 (S), JP9.18, RD14.1, RR13.2
CH14: F14.2 (S), JP9.9, RD15.1, RR14.2
CH15: F15.2 (S), JP9.19, RD16.1, RR15.2
CH16: F16.2 (S), JP9.10, RD17.1, RR16.2
CH17: F17.2 (S), JP9.20, RD18.1, RR17.2
CH18: D100.A (C), F18.2 (S), JP9.11, R120.1, R$13.2, RR18.2
CHGR-FET-DRAIN: D7.A, FET5.3 (D), L1.2
CHGR-TEST-V+: D100.C (A), JP7.1, R118.2, R120.2, R122.2
CHGR-V+: C6.1, C113.1, D5.2 (C), D7.C, D8.C, JP7.2, R122.1
DRAIN$1: F1.3 (D), RD1.2
DRAIN$2: F2.3 (D), RD2.3
DRAIN$3: F3.3 (D), RD3.3
DRAIN$4: F4.3 (D), RD4.3
DRAIN$5: F5.3 (D), RD5.3
DRAIN$6: F6.3 (D), RD6.3
DRAIN$7: F7.3 (D), RD7.3
DRAIN$8: F8.3 (D), RD8.3
DRAIN$9: F9.3 (D), RD9.3
DRAIN$10: F10.3 (D), RD10.3
DRAIN$11: F11.3 (D), RD11.3
DRAIN$12: F12.3 (D), RD12.3
DRAIN$13: F13.3 (D), RD13.3
DRAIN$14: F14.3 (D), RD14.3
DRAIN$15: F15.3 (D), RD15.3
DRAIN$16: F16.3 (D), RD16.3
DRAIN$17: F17.3 (D), RD17.3
DRAIN$18: F18.3 (D), RD18.3
DUMP2: FET100.3 (D), JP15.2
DUMP2FET-SOURCE: FET100.2 (S), JP15.1, R100.1, R101.2
DUMPFET-DRAIN: FET105.3 (D), JP1.2
DUMPFET-GATE: FET104.3 (D), FET105.1 (G), R129.2
DUMPFET-SOURCE: FET105.2 (S), JP1.1, R127.2, R129.1
FAN+12: C1.1, JP14.2, REG3A.3 (VO), REG3B.3 (VO)
FANPWN: IC100.2 (I), OPT100.P$4 (OUT), R102.1
FANPWN-INVERT: IC100.4, JP14.4
FANTACH-H11DIODE: JP14.3, OPT1.P$2 (C)
FANTACH-RESISTOR: OPT1.P$1 (A), R105.2
FET103-GATE: D3.A, FET102.1 (G), R12.1
G1: JP4.2, U$5.39 (GPIO1)
G2: C126.1, JP3.2, R10.2, U$5.40 (GPIO2)
G3: C121.1, JP6.2, R14.2, U$5.41 (GPIO3)
G4: C114.1, JP8.2, R15.2, U$5.42 (GPIO4)
G5: R19.2, R112.1, U$4.MP, U$5.43 (GPIO5)
G6: R124.1, U$5.44 (GPIO6), U$100.1 (OUT)
G7: R22.1, R23.2, U$5.45 (GPIO7), U$7.MP
G7-DIVIDER-HIGH: R22.2, U$6.MP
G8: R20.2, U$3.MP, U$5.46 (GPIO8)
G9: R114.2, U$2.MP, U$5.47 (GPIO9)
GATE-DRV-MCP1416: IC101.5 (OUT), R117.2
GHR_FET_GATE: FET5.1 (G), R117.1, TP1.MP
GND: C2.2, C4.2, C5.2, C6.2, C7.2, C8.2, C100.2, C101.2, C102.2, C103.2, C104.2, C105.2, C106.2, C108.2, C109.2, C110.2, C111.2, C112.2, C113.2, C114.2, C115.2, C116.2, C117.2, C118.2, C119.2, C120.2, C121.2, C123.2, C124.2, C126.2, CC101.2, CP100.2, CP101.2, D5.1 (A), D8.A, FET2.2 (S), FET3.2 (S), FET101.2 (S), FET106.2 (S), IC1.7 (GND), IC1B.7 (VO-), IC2A.2 (GND12), IC2A.8 (GND11), IC101.4 (GND), JP2.1, JP3.1, JP4.1, JP6.1, JP8.1, JP9.2, JP11.1, JP11.3, JP13.1, JP16.1, JP17.1, JP18.1, OPT1.P$5 (GND), OPT101.P$5 (GND), R2.1, R5.2, R7.2, R11.2, R16.1, R20.1, R23.1, R100.2, R104.2, R108.1, R109.1, R111.2, R112.2, R114.1, R116.1, R125.1, R126.1, R127.1, R130.1, RD1.1, REG1A.1 (GND), REG100.1 (GND), RESET.3, RESET.4, TP-GND.MP, U1.12 (VSSA), U1.15 (PA1), U1.18 (VSS_4), U1.31 (VSS_1), U1.47 (VSS_2), U1.60 (BOOT0), U1.63 (VSS_3), U$1.2 (GND), U$5.38 (C0), U$5.55 (ISOMD), U$5.59 (V-**), U$5.60 (V-), U$5.V- (VPAD), U$8.4 (GND1), U$9.P$4 (0V), U$100.2 (V-)
GNDA: C1.2, C3.-, C107.2, C122.2, C125.2, IC1B.2 (VIN+), IC2A.9 (GND23), IC2A.10 (GND22), IC2A.15 (GND21), IC100.3 (GND), JP10.2, JP10.5, JP10.9, JP14.1, OPT100.P$5 (GND), R9.1, R12.2, REG1.1 (GND), REG3A.1 (GND), REG3B.2 (GND), TP-GNDA.MP, U$8.5 (GND2), U$9.P$2 (CTL), U$9.P$3 (GND)
GT1: F1.1 (G), RG1.2
GT2: F2.1 (G), RG2.2
GT3: F3.1 (G), RG3.2
GT4: F4.1 (G), RG4.2
GT5: F5.1 (G), G5.2
GT6: F6.1 (G), RG6.2
GT7: F7.1 (G), RG7.2
GT8: F8.1 (G), RG8.2
GT9: F9.1 (G), RG9.2
GT10: F10.1 (G), RG10.2
GT11: F11.1 (G), RG11.2
GT12: F12.1 (G), RG12.2
GT13: F13.1 (G), RG13.2
GT14: F14.1 (G), RG14.2
GT15: F15.1 (G), RG15.2
GT16: F16.1 (G), RG16.2
GT17: F17.1 (G), RG17.2
GT18: F18.1 (G), RG18.2
H11L-PWM-R: OPT100.P$1 (A), R103.1
H11PWM-FETDRV: FET101.3 (D), OPT100.P$2 (C)
ICMP-IBIAS: R108.2, U$5.57 (IBIAS), U$5.58 (ICMP)
IMB: R26.2, U$5.63 (IMB)
IPB: R26.1, U$5.64 (IPB)
K1: R11.1, SP1.1
LED-EXT-GRN-CATHODE: JP12.2, LED2.C, R27.1
LED-EXT-RED-CATHODE: JP12.3, LED3.C, R28.1
LED_BUS_PWR: LED1.C, R9.2
MASTER-RESET-RESISTOR: D4.C, D6.C, OPT101.P$1 (A), R123.2
MASTER-RESET-SYS: D4.A, D6.A, JP10.6, OPT101.P$2 (C)
unnamed: JP9.1, R121.1, R126.2
NRST: OPT101.P$4 (OUT), R18.1, RESET.1, RESET.2, U1.7 (NRST)
OPA-VIN+: R113.2, R121.2, U$100.3 (+IN)
OPA-VIN-: R124.2, R125.2, U$100.4 (-IN)
PA0-OP-FILTERCURRENT: C7.1, R17.2, TP3.MP, U1.14 (PA0)
PA2-COMP2-OUT: TP4.MP, U1.16 (PA2)
PA3-OPAMP_INP: TP5.MP, U1.17 (PA3)
PA4-15V-OR-DIVIDED-IN4: R111.1, R115.2, U1.20 (PA4)
PA5-FETGATE-FAN-PWM: FET101.1 (G), R104.1, U1.21 (PA5)
PA6-T1-BKIN-COMP2: TP6.MP, U1.22 (PA6)
PA8-T1C1-MCP1416_DRV: IC101.3 (IN), R109.2, U1.41 (PA8)
PA9-USART1-TX: JP17.5, U1.42 (PA9)
PA10-USART1-RX: JP17.4, U1.43 (PA10)
PA13-SWDIO: JP13.3, U1.46 (PA13)
PA14-SWCLK: JP13.2, U1.49 (PA14)
PA15-SP1_NSS-CSB: U1.50 (PA15), U$5.61 (CSB)
PB0-LED-GRN: R27.2, U1.26 (PB0)
PB1-LED-RED: R28.2, U1.27 (PB1)
PB2-PA7-HV-DIV-COMP1_INP: R116.2, R118.1, U1.23 (PA7), U1.28 (PB2)
PB3-SPI1_SCK-SCK: U1.55 (PB3), U$5.62 (SCK)
PB4-SP1_MISO-SDO: R25.1, U1.56 (PB4), U$5.54 (SDO)
PB5-SPI1_MOSI-SDI: U1.57 (PB5), U$5.53 (SDI)
PB6-PC3-COMP2_INP-CURRENT-SENSE: FET5.2 (S), R16.2, R17.1, TP2.MP, U1.11 (PC3), U1.58 (PB6)
PB7|WDT: U1.59 (PB7), U$5.56 (WDT)
PB8-CAN-RX: IC2A.5 (RXD), RXD.MP, U1.61 (PB8), U$8.2 (RXD)
PB9-CAN-TX: IC2A.3 (TXD), R107.1, TXD.MP, U1.62 (PB9), U$8.3 (TXD)
PB10-T2C3-FANTACH-H11L1OUT: OPT1.P$4 (OUT), R30.1, U1.29 (PB10)
PB11-I2C2-SDA|VCAP1: CP100.1, U1.30 (PB11)
PB12-SPI2-NSS: SP2.MP, U1.33 (PB12)
PB14-I2C2-SDA: JP16.4, R32.1, U1.35 (PB14)
PB-13-I2C2-SCK: JP16.3, R31.1, U1.34 (PB13)
PB-15: SP3.MP, U1.36 (PB15)
PC4: JP11.2, R24.1, U1.24 (PC4)
PC5: JP11.4, R21.1, U1.25 (PC5)
PC6-DUMPFET-GATE: FET100.1 (G), R101.1, U1.37 (PC6)
PC8-/DUMP: IC1.8 (I0), IC1.9 (I1), U1.39 (PC8)
PC8-DUMP: IC1.10 (O), IC1.12 (I1)
PC10&/PC8-DUMP-FET-GATE: FET2.1 (G), IC1.13 (O), R7.1
PC10-DUMP: IC1.11 (I0), R29.1, U1.51 (PC10)
PC11-/HEATER: IC1.5 (I0), IC1.6 (I1), U1.52 (PC11)
PC12-HEATER: IC1.2 (I0), R106.1, U1.53 (PC12)
PC13-RTC-OUT: FET3.1 (G), R2.2, U1.2 (PC13)
PC14_OSC32IN|XTAL: 32KHZ.2, C106.1, U1.3 (PC14)
PC15-32OSC-OUT: 32KHZ.1, C105.1, U1.4 (PC15)
PD0_OSC_IN_XTAL: C109.1, Q100.2, R110.1, U1.5 (PD0/OSC<=)
PD1_OSC_OUT: C108.1, Q100.1, R110.2, U1.6 (PD1/OSC=>)
S1: RD2.2, RG1.1, U$5.37 (S1)
S2: RD3.2, RG2.1, U$5.35 (S2)
S3: RD4.2, RG3.1, U$5.33 (S3)
S4: RD5.2, RG4.1, U$5.31 (S4)
S5: G5.1, RD6.2, U$5.29 (S5)
S6: RD7.2, RG6.1, U$5.27 (S6)
S7: RD8.2, RG7.1, U$5.25 (S7)
S8: RD9.2, RG8.1, U$5.23 (S8)
S9: RD10.2, RG9.1, U$5.21 (S9)
S10: RD11.2, RG10.1, U$5.19 (S10)
S11: RD12.2, RG11.1, U$5.17 (S11)
S12: RD13.2, RG12.1, U$5.15 (S12)
S13: RD14.2, RG13.1, U$5.13 (S13)
S14: RD15.2, RG14.1, U$5.11 (S14)
S15: RD16.2, RG15.1, U$5.9 (S15)
S16: RD17.2, RG16.1, U$5.7 (S16)
S17: RD18.2, RG17.1, U$5.5 (S17)
S18: R$13.1, RG18.1, U$5.3 (S18)
TIM1_BKIN2_COMP2: TP7.MP, U1.44 (PA11)
V-ORED: C112.1, C119.1, C120.1, D1.C, D2.C, FET1.2 (S), FET104.2 (S), R3.2, R128.2, REG1A.2 (VI), REG1A.4 (VITAB), REG100.2 (VI), REG100.4 (VITAB)
VBAT-REG-IN: C2.1, R13.1, U$1.4 (VI)
VBAT-REG-OUT: C5.1, U1.1 (VBAT), U$1.5 (VO)
VCC: 5V1.MP, BEAD.1, C8.1, C100.1, C101.1, C102.1, C104.1, C118.1, C124.1, CP101.1, IC2A.1 (VCC1), JP12.1, LED2.A, LED3.A, OPT1.P$6 (VCC), OPT101.P$6 (VCC), R18.2, R21.2, R24.2, R25.2, R29.2, R30.2, R103.2, R106.2, R107.2, REG1A.3 (VO), U1.19 (VDD_4), U1.32 (VDD_1), U1.48 (VDD_2), U1.64 (VDD_3), U$8.1 (VCC1)
VDDA1: BEAD.2, C103.1, U1.13 (VDDA)
VREF3: C110.1, U$5.51 (VREF1)
VREF4: C111.1, U$5.50 (VREF2)
XOR-BIGFET-GATE: FET106.1 (G), IC1.1 (O), R130.2

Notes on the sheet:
CAN interface
CAN bus side
CAN BUS PLUS
------------------------
FAN
82V
TACH
PWM
5V system
Master Reset
Alternate
TEST POINT
CURRENT
CHARGING
RESET
HARD
3.3V
Wake-up
pushbutton
Battery power
switch
Pin 47
Pin 30
f446 = VCAP_1 2.2u
Pin 31
f446 = VSS zero ohm
CP1
CP3
f446 = VCAP_1
CP2
ADC
32768Hz
RTC Alarm
GREEN
RED
3.3v
Cell #3 (C3)
Pack Heater
1217136-1
TE Connectivity

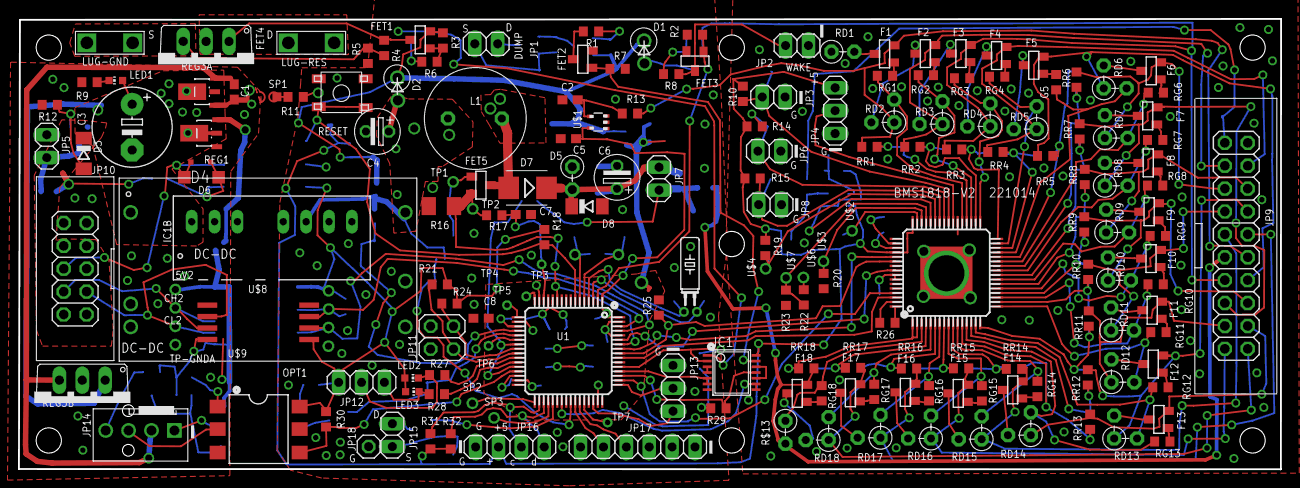
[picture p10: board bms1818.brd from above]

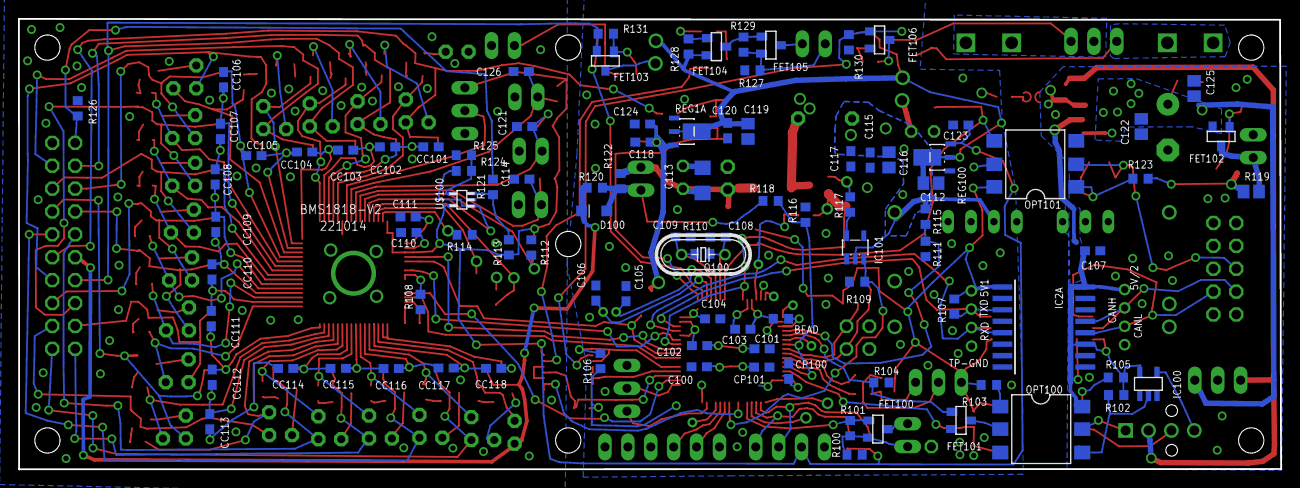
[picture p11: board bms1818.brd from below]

Board: 2 copper layers, 140.1 x 50.0 mm, 283 parts (97 on the bottom side), 203 nets.

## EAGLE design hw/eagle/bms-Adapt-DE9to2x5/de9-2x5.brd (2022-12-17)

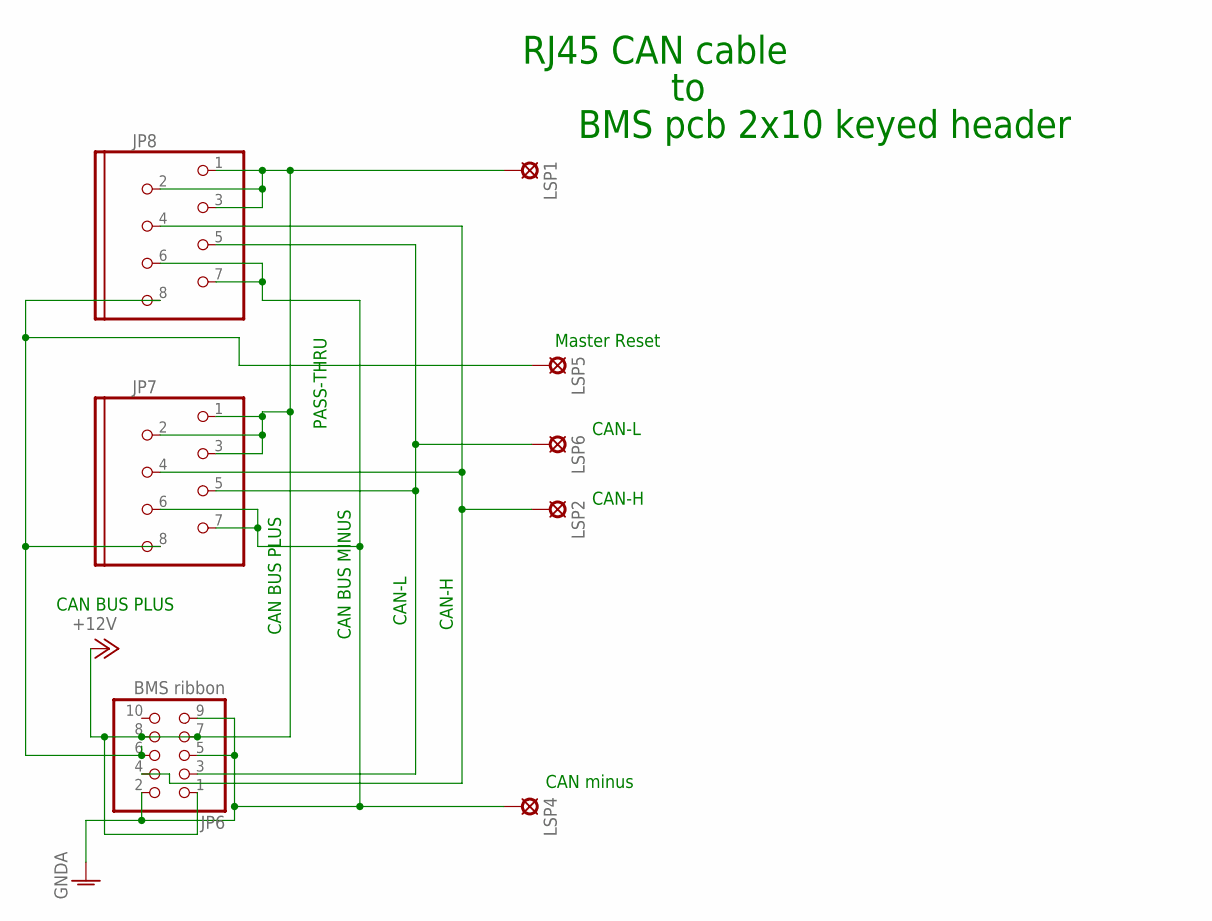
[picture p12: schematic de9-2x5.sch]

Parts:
JP6: BMS ribbon; 2X05_KEYED
JP7, JP8: MOD8P8C
LSP1, LSP4: SE14
LSP2, LSP5, LSP6: LSP10

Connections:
+12V: JP6.1, JP6.7, JP6.8, JP7.1, JP7.2 (5), JP7.3 (2), JP8.1, JP8.2 (5), JP8.3 (2), LSP1.MP
CANH: JP6.4, JP7.4 (6), JP8.4 (6), LSP2.MP
CANL: JP6.3, JP7.5 (3), JP8.5 (3), LSP6.MP
GNDA: JP6.2, JP6.5, JP6.9, JP7.6 (7), JP7.7 (4), JP8.6 (7), JP8.7 (4), LSP4.MP
MASTER-RESET-SYS: JP6.6, JP7.8, JP8.8, LSP5.MP

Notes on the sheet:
CAN BUS PLUS
PASS-THRU
CAN BUS MINUS
CAN-H
CAN-L
RJ45 CAN cable
BMS pcb 2x10 keyed header
Master Reset
CAN minus

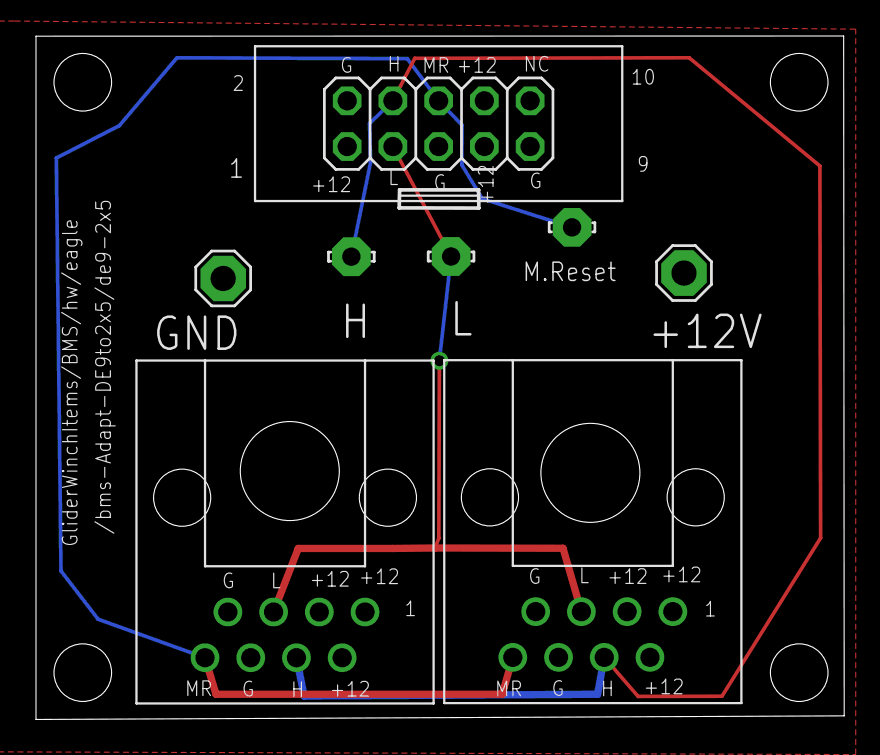
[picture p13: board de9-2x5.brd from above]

Board: 2 copper layers, 44.9 x 38.0 mm, 8 parts (0 on the bottom side), 5 nets.

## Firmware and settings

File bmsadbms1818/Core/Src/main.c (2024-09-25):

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
/* Includes ------------------------------------------------------------------*/
#include "main.h"
#include "cmsis_os.h"

/* USER CODE BEGIN Includes */
#include <string.h>
#include "morse.h"
#include "DTW_counter.h"
#include "fetonoff.h"

#include "adcparams.h"
#include "SerialTaskSend.h"
#include "SerialTaskReceive.h"
#include "CanTask.h"
#include "can_iface.h"
#include "canfilter_setup.h"
#include "getserialbuf.h"
#include "yprintf.h"
#include "DTW_counter.h"
#include "BQTask.h"
#include "bqview.h"
#include "bqcellbal.h"
#include "bq_func_init.h"
#include "bq_items.h"
#include "ADCTask.h"
#include "MailboxTask.h"
#include "CanCommTask.h"
#include "BMSTask.h"
#include "fanop.h"
#include "chgr_items.h"
#include "bmsspi.h"
#include "bms_items.h"
#include "rtcregs.h"

#include "FreeRTOS.h"
#include "semphr.h"
/* USER CODE END Includes */

/* USER CODE BEGIN PTD */
uint32_t timectr = 0;
struct CAN_CTLBLOCK* pctl0; // Pointer to CAN1 control block
//struct CAN_CTLBLOCK* pctl1; // Pointer to CAN2 control block

uint32_t debugTX1b;
uint32_t debugTX1b_prev;

uint32_t debugTX1c;
uint32_t debugTX1c_prev;

uint32_t debug03;
uint32_t debug03_prev;

uint32_t dbgwarning;

//extern osThreadId SerialTaskHandle;
//extern osThreadId CanTxTaskHandle;
//extern osThreadId CanRxTaskHandle;
//extern osThreadId SerialTaskReceiveHandle;

uint16_t m_trap = 450; // Trap codes for MX Init() and Error Handler

uint8_t canflag;
uint8_t canflag1;
//uint8_t canflag2;

int8_t rtcregs_ret; // RTC register init return

const uint32_t i_am_canid = I_AM_CANID;

/* USER CODE END PTD */

/* USER CODE BEGIN PM */
  /* 
  Timer usage
                         1    2   3   4   auto  auto
  TIM1 charger control  PWM   x   x   x  comp1 comp2
                        PA8               PA6   PA11 
  TIM2 FAN PWM TACH     PWM   x  IC   x    
                        PA5     PB10
  TIM7  System          x     

  TIM15 SPI/ADC/BMS     OC    x
  
  */
/* USER CODE END PM */

ADC_HandleTypeDef hadc1;
DMA_HandleTypeDef hdma_adc1;

CAN_HandleTypeDef hcan1;

COMP_HandleTypeDef hcomp1;
COMP_HandleTypeDef hcomp2;

DAC_HandleTypeDef hdac1;

I2C_HandleTypeDef hi2c2;
DMA_HandleTypeDef hdma_i2c2_rx;
DMA_HandleTypeDef hdma_i2c2_tx;

OPAMP_HandleTypeDef hopamp1;

RTC_HandleTypeDef hrtc;

SPI_HandleTypeDef hspi1;
DMA_HandleTypeDef hdma_spi1_rx;
DMA_HandleTypeDef hdma_spi1_tx;

TIM_HandleTypeDef htim1;
TIM_HandleTypeDef htim2;
TIM_HandleTypeDef htim15;

UART_HandleTypeDef huart1;
DMA_HandleTypeDef hdma_usart1_rx;
DMA_HandleTypeDef hdma_usart1_tx;

/* Definitions for defaultTask */
osThreadId_t defaultTaskHandle;
const osThreadAttr_t defaultTask_attributes = {
  .name = "defaultTask",
  .stack_size = 448 * 4,
  .priority = (osPriority_t) osPriorityNormal,
};
/* USER CODE BEGIN PV */
uint16_t errorcode;
/* USER CODE END PV */

void SystemClock_Config(void);
static void MX_GPIO_Init(void);
static void MX_DMA_Init(void);
static void MX_ADC1_Init(void);
static void MX_CAN1_Init(void);
static void MX_RTC_Init(void);
static void MX_TIM2_Init(void);
static void MX_USART1_UART_Init(void);
static void MX_COMP1_Init(void);
static void MX_DAC1_Init(void);
static void MX_TIM1_Init(void);
static void MX_TIM15_Init(void);
static void MX_OPAMP1_Init(void);
static void MX_SPI1_Init(void);
static void MX_I2C2_Init(void);
static void MX_COMP2_Init(void);
void StartDefaultTask(void *argument);

/**
  * @brief  The application entry point.
  * @retval int
  */
int main(void)
{
  /* USER CODE BEGIN 1 */
  BaseType_t ret;    // Used for returns from function calls
  osThreadId Thrdret;  // Return from thread create
  /* USER CODE END 1 */

  /* MCU Configuration--------------------------------------------------------*/

  /* Reset of all peripherals, Initializes the Flash interface and the Systick. */
  HAL_Init();

  /* USER CODE BEGIN Init */
  DTW_counter_init();
  /* USER CODE END Init */

  /* Configure the system clock */
  SystemClock_Config();

  /* USER CODE BEGIN SysInit */
#define NUMCIRBCB1  16 // Size of circular buffer of BCB for usart3
  ret = xSerialTaskSendAdd(&HUARTMON, NUMCIRBCB1, 1); // dma
  if (ret < 0) morse_trap(111); // Panic LED flashing
  /* USER CODE END SysInit */

  /* Initialize all configured peripherals */
  MX_GPIO_Init();
  MX_DMA_Init();
  MX_ADC1_Init();
  MX_CAN1_Init();
  MX_RTC_Init();
  MX_TIM2_Init();
  MX_USART1_UART_Init();
  MX_COMP1_Init();
  MX_DAC1_Init();
  MX_TIM1_Init();
  MX_TIM15_Init();
  MX_OPAMP1_Init();
  MX_SPI1_Init();
  MX_I2C2_Init();
  MX_COMP2_Init();
  /* USER CODE BEGIN 2 */
  /* CAN ID for this node is passed in to make from command line. */
//  i_am_canid = I_AM_CANID;
  /* USER CODE END 2 */

  /* Init scheduler */
  osKernelInitialize();

  /* USER CODE BEGIN RTOS_MUTEX */
  /* add mutexes, ... */
  /* USER CODE END RTOS_MUTEX */

  /* USER CODE BEGIN RTOS_SEMAPHORES */
  /* add semaphores, ... */
  /* Setup semaphore for yprint and sprintf et al. */
  yprintf_init();
  /* USER CODE END RTOS_SEMAPHORES */

  /* USER CODE BEGIN RTOS_TIMERS */
  /* start timers, add new ones, ... */
  /* USER CODE END RTOS_TIMERS */

  /* USER CODE BEGIN RTOS_QUEUES */
  /* add queues, ... */
  /* USER CODE END RTOS_QUEUES */

  /* Create the thread(s) */
  /* creation of defaultTask */
  defaultTaskHandle = osThreadNew(StartDefaultTask, NULL, &defaultTask_attributes);

  /* USER CODE BEGIN RTOS_THREADS */
  /* add threads, ... */

  Thrdret = xADCTaskCreate(osPriorityNormal+2); // (arg) = priority
  if (Thrdret == NULL) morse_trap(117);

  /* Create serial task (priority) */
  // Task handle "osThreadId SerialTaskHandle" is global
  Thrdret = xSerialTaskSendCreate(osPriorityNormal); // Create task and set Task priority
  if (Thrdret == NULL) morse_trap(112);

    /* Add bcb circular buffer to SerialTaskSend for usart3 -- PC monitor */
  #define NUMCIRBCB3  16 // Size of circular buffer of BCB for usart3
  ret = xSerialTaskSendAdd(&HUARTMON, NUMCIRBCB3, 1); // dma
  if (ret < 0) morse_trap(14); // Panic LED flashing

  /* Setup TX linked list for CAN  */
   // CAN1 (CAN_HandleTypeDef *phcan, uint8_t canidx, uint16_t numtx, uint16_t numrx);
  pctl0 = can_iface_init(&hcan1, 0, 96, 32);       
  if (pctl0 == NULL) morse_trap(118); // Panic LED flashing
  if (pctl0->ret < 0) morse_trap(119);

  /* Create serial receiving task. */
  //ret = xSerialTaskReceiveCreate(osPriorityNormal);
  //if (ret != pdPASS) morse_trap(113);

  /* BQTask. */
//  TaskHandle_t retT = xBQTaskCreate(osPriorityNormal);
//  if (retT == NULL) morse_trap(114);

  /* USER CODE END RTOS_THREADS */

  /* USER CODE BEGIN RTOS_EVENTS */
  /* add events, ... */
  // Initialize struct for BQ. */
  bq_func_init();


  /* definition and creation of CanTxTask - CAN driver TX interface. */
  QueueHandle_t QHret = xCanTxTaskCreate(osPriorityNormal+1, 48); // CanTask priority, Number of msgs in queue
  if (QHret == NULL) morse_trap(120); // Panic LED flashing

  /* definition and creation of CanRxTask - CAN driver RX interface. */
  /* The MailboxTask takes care of the CANRx                         */
//  Qidret = xCanRxTaskCreate(1, 32); // CanTask priority, Number of msgs in queue
//  if (Qidret < 0) morse_trap(6); // Panic LED flashing

  /* Create MailboxTask */
  xMailboxTaskCreate(osPriorityNormal+1); // (arg) = priority

  /* Create Mailbox control block w 'take' pointer for each CAN module. */
  struct MAILBOXCANNUM* pmbxret;
  // (CAN1 control block pointer, size of circular buffer)
  pmbxret = MailboxTask_add_CANlist(pctl0, 32);
  if (pmbxret == NULL) morse_trap(215);

  /* Setup CAN hardware filters to default to accept all ids. */
  HAL_StatusTypeDef Cret;
  Cret = canfilter_setup_first(0, &hcan1, 15); // CAN1
  if (Cret == HAL_ERROR) morse_trap(122);

  TaskHandle_t retT = xBMSTaskCreate(osPriorityNormal+2);  
//  TaskHandle_t retT = xBMSTaskCreate(osPriorityNormal+1);  
  if (retT == NULL) morse_trap(123);

  /* CAN communication */
  retT = xCanCommCreate(osPriorityNormal+2);
  if (retT == NULL) morse_trap(121);

    /* Select interrupts for CAN1 */
  HAL_CAN_ActivateNotification(&hcan1, \
    CAN_IT_TX_MAILBOX_EMPTY     |  \
    CAN_IT_RX_FIFO0_MSG_PENDING |  \
    CAN_IT_RX_FIFO1_MSG_PENDING    );

  /* Init some things used by tasks. */
  //bq_func_init();
  chgr_items_init();
  fanop_init();
  bmsspi_preinit();
  rtcregs_ret = rtcregs_init();

  /* This will run the 5 and 3.3v regulators from the ribbon
     Cell #3 when the CAN power has been removed. */
  HAL_GPIO_WritePin(GPIOC,GPIO_PIN_13,GPIO_PIN_SET); // ON
//HAL_GPIO_WritePin(GPIOC,GPIO_PIN_13,GPIO_PIN_RESET); // OFF
  /* USER CODE END RTOS_EVENTS */

  /* Start scheduler */
  osKernelStart();

  /* We should never get here as control is now taken by the scheduler */
  /* Infinite loop */
  /* USER CODE BEGIN WHILE */
  while (1)
  {
    /* USER CODE END WHILE */

    /* USER CODE BEGIN 3 */
  }
  /* USER CODE END 3 */
}

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
/* USER CODE BEGIN Header_StartDefaultTask */
/**
  * @brief  Function implementing the defaultTask thread.
  * @param  argument: Not used
  * @retval None
  */
uint32_t adc1_ctr_prev;
uint32_t fctr = 0;
uint8_t adcctr = 0;
uint8_t wakectr;
uint8_t state_defaultTask = 0;
static struct BMSREQ_Q bmsreq_1;
struct BMSREQ_Q* pbmsreq_1 = &bmsreq_1;
#define LSPC 7 // column spacing
char* pcheader =
"\n\r                 1      2      3      4      5      6      7      8      9     10     11     12     13     14     15     16     17     18";
char* ptripcode ="0123456789ABCDEFGH";
static uint8_t idxtripcode;
static char tripline[LSPC*18+2];
static uint32_t celltrip_prev;
static uint32_t celltrip_time[18];
static uint32_t celltrip_time_offset;
static uint32_t celltrip_time_offset_discharge;
static uint32_t celltrip_time_lo;
static uint8_t hyster_sw_prev;
uint32_t rtcregs_status;
uint32_t rtcregs_morse_code;
uint8_t rtcregs_OK;
/* USER CODE END Header_StartDefaultTask */
void StartDefaultTask(void *argument)
{
  /* USER CODE BEGIN 5 */
  int32_t i;
  uint32_t mctr = 0;

// Poll 'done' so task handle not needed
  //bmsreq_read.bmsTaskHandle   = xTaskGetCurrentTaskHandle();
  //bmsreq_update.bmsTaskHandle = bmsreq_read.msTaskHandle;

  struct SERIALSENDTASKBCB* pbuf1 = getserialbuf(&HUARTMON,144);
  if (pbuf1 == NULL) morse_trap(115);
  struct SERIALSENDTASKBCB* pbuf2 = getserialbuf(&HUARTMON,128);
  if (pbuf2 == NULL) morse_trap(125);
struct SERIALSENDTASKBCB* pbuf3 = getserialbuf(&HUARTMON,128);
if (pbuf3 == NULL) morse_trap(125);
//struct SERIALSENDTASKBCB* pbuf4 = getserialbuf(&HUARTMON,128);
//if (pbuf4 == NULL) morse_trap(125);

  yprintf(&pbuf1,"\n\n\rPROGRAM STARTS: rtcregs_ret: ");
  if (rtcregs_ret == 0)
  {
    yprintf(&pbuf3,"OK");
  } 
  else
  {
    yprintf(&pbuf3,"NG");

  } 


  /* List the RTC */
  /*
  uint32_t cellbal;       //   1.00 Bits with FETs that were on
  uint32_t hysterbits_lo; //   1.00 Bits for cells that fell below hysterv_lo
  uint16_t cellreg[18];   //   9.00 Last readings before power down
  uint8_t hyster_sw;      //   .125 Hysteresis switch: 1 = peak was reached
  uint8_t battery_status; //   .125 Cell status code bits 
  uint8_t fet_status;     //   .125 This controls on/off of FETs
  uint8_t err;            //   .125 Err bits
  uint32_t morse_err;     //   1.00 morse_trap err code
  uint32_t celltrip;      //   1.00 Cell trip bits
  uint16_t morse_err_ct;  //    .50 Count of same morse_trap code
  uint16_t warning;       //    .50 Warning, but not morse_trap'd
 The foregoing MUST be an even number of 32b 
  uint16_t pec15; // CRC15 (in lower 1/2 of register)
*/
  if (rtcregs_ret == 0)
  {
    yprintf(&pbuf1,"\n\r\t\tRTC REGISTERS SAVED & RESTORED");
    uint32_t* prtc = (uint32_t*)&RTC->BKP0R;
    yprintf(&pbuf2,"\n\rcellbal: %05X",*prtc++);
    yprintf(&pbuf1,"\n\rhysterbits_lo: %05X",*prtc++);
    yprintf(&pbuf2,"%s",pcheader);
    yprintf(&pbuf1,"\n\r           ");
    for (i = 0; i < 9; i++)
    {
      yprintf(&pbuf1," %6d",(*prtc & 0xFFFF));
      yprintf(&pbuf2," %6d",(*prtc >> 16));
      prtc += 1;
    }
    rtcregs_status = *prtc; // Save for CAN msgs

    yprintf(&pbuf1,"\n\rhyster_sw     : %02X",((*prtc >>  0) & 0xff));
    yprintf(&pbuf2,"\n\rbattery_status: %02X",((*prtc >>  8) & 0xff));
    yprintf(&pbuf1,"\n\rfet_status    : %02X",((*prtc >> 16) & 0xff));
    yprintf(&pbuf2,"\n\rerr           : %02X",((*prtc >> 24) & 0xff));
    prtc += 1;
    rtcregs_morse_code = *prtc; // Save for CAN msgs
    yprintf(&pbuf1,"\n\rmorse_err: %d",*prtc);
     prtc += 1;
    yprintf(&pbuf1,"\n\rcelltrip: 0x%05x\n\n\r",*prtc);
     prtc += 1;
    yprintf(&pbuf2,"\n\rmorse_err_ct  : %d"  ,((*prtc >>  0) & 0xffff));
    yprintf(&pbuf3,"\n\rwarning       : %04X",((*prtc >> 16) & 0xffff));

    osDelay(50); // Allow enough time to printout before next morse_trap
  }

  /* The 'for' loop polls. The following times the loop. */
  #define MAINFORLOOPDELAY 50 // Delay of 'for' loop in ms
  const TickType_t xPeriod = pdMS_TO_TICKS(MAINFORLOOPDELAY);  
  TickType_t tickcnt = xTaskGetTickCount();
  
  bq_items_init(); // Updates tickcnt

//extern uint32_t bmsdbctr;
//uint32_t bmsdbctr_prev = bmsdbctr;
extern uint8_t dbgka;
uint8_t dbgka_prev = dbgka;
extern uint32_t bshift;  
extern uint32_t dbstat2;

/* Testint discharge FET bits. */
#ifdef TEST_WALK_DISCHARGE_FET_BITS // See main.h
extern uint8_t dischgfet; // Test fet bit (0-17)
  uint8_t  dischgfet_ctr = 20; 
extern  dbgcancommloop;
uint32_t dbgcancommloop_prev;
#endif

uint32_t ticks_secs = 0;
uint32_t ticks_next = xTaskGetTickCount();

//uint32_t dbgsendcellctr_prev=0;
//uint32_t dbgsendcelldtw_prev=0;

  memset(tripline,' ',(LSPC*18));
  for (i = 0; i < 18; i++) tripline[i*LSPC] = '.';
  tripline[18*LSPC] = 0;
  celltrip_prev = 0;

// Test battery switch fet PC13)
//HAL_GPIO_WritePin(GPIOC,GPIO_PIN_13,GPIO_PIN_SET); 

  for(;;) /* Loop polls various operations. */
  {  
    vTaskDelayUntil( &tickcnt, xPeriod );

    /* Keep a running count of secs. */
    if ( (int)(xTaskGetTickCount() - ticks_next) > 1000)
    {
      ticks_next += 1000;
      ticks_secs += 1;
    }

#if 1 // Processor ADC display
    adcctr += 1;
    if (adcctr > 40)
    {
      adcctr = 0;
  extern uint32_t dwtdiff;      
  #if 1
      yprintf(&pbuf1,"\n\rADCf: %4d %6d:",(adc1.ctr-adc1_ctr_prev),dwtdiff);
      adc1_ctr_prev = adc1.ctr;
      for (i = 0; i < 9; i++)
      {
        yprintf(&pbuf2," %6.4f",adc1.abs[i].filt);
      }
      float tcf = adcparams_caltemp();
      yprintf(&pbuf1," temp: %4.1f",tcf);
  #endif 

  #if 0     
      float tcf1 = adcparams_caltemp();
      yprintf(&pbuf1,"\n\r temp: %6.4f vref %0.5f cal1 %0.1f cal2 %0.1f caldiff %0.4f calrate %0.5f",tcf1,
        adc1.common.ts_vref,
        adc1.common.ts_cal1,      /* (float)(*PTS_CAL1); // Factory calibration */
        adc1.common.ts_cal2,      /* (float)(*PTS_CAL2); // Factory calibration */
        adc1.common.ts_caldiff,   /* (padccommon->ts_cal2 - padccommon->ts_cal1); */
        adc1.common.ts_calrate );
#endif      

  #if 1
      yprintf(&pbuf1,"\n\rADCi: %4d %6d",(adc1.ctr-adc1_ctr_prev),dwtdiff);     
    extern uint32_t dbg_adcsum[ADCDIRECTMAX];        
      yprintf(&pbuf1," %6d %6d %6d %6d %6d %6d %6d %6d %6d",
          dbg_adcsum[0],dbg_adcsum[1],dbg_adcsum[2],dbg_adcsum[3],dbg_adcsum[4],
          dbg_adcsum[5],dbg_adcsum[6],dbg_adcsum[7],dbg_adcsum[8]);
  #endif 
      adc1_ctr_prev = adc1.ctr;
    }
#endif    

#if 1
    HAL_GPIO_WritePin(GPIOB,GPIO_PIN_0,GPIO_PIN_SET); // GRN LED
    if (dbgka_prev != dbgka)
    {
      dbgka_prev = dbgka;
      HAL_GPIO_WritePin(GPIOB,GPIO_PIN_0,GPIO_PIN_RESET); // GRN LED

      switch (dbgka)
      {
      case 0: // config regs
       yprintf(&pbuf1,"\n\n\r\t\t%5d",mctr++);

       yprintf(&pbuf2,"\n\r%5d CFGR   %04X %04X %04X : %04X %04X %04X %d",dbgka,
          bmsspiall.configreg[0],bmsspiall.configreg[1],bmsspiall.configreg[2],
          bmsspiall.configreg[3],bmsspiall.configreg[4],bmsspiall.configreg[5],bshift+1);
        break;

      case 1: // Stat regs
       yprintf(&pbuf2,"\n\r%5d STAT   %04X %04X %04X : %04X %04X %04X %d ",dbgka,
          bmsspiall.statreg[0],bmsspiall.statreg[1],bmsspiall.statreg[2],
          bmsspiall.statreg[3],bmsspiall.statreg[4],bmsspiall.statreg[5],dbstat2/16);      
        break;

      case 2:
       yprintf(&pbuf2,"\n\r%5d SREG   %04X %04X %04X",dbgka,
          bmsspiall.sreg[0],bmsspiall.sreg[1],bmsspiall.sreg[2]);
        break;

      case 3:
       yprintf(&pbuf2,"\n\r%5d WFGR   %04X %04X %04X : %04X %04X %04X",dbgka,
          bmsspiall.configreg[0],bmsspiall.configreg[1],bmsspiall.configreg[2],
          bmsspiall.configreg[3],bmsspiall.configreg[4],bmsspiall.configreg[5]);
        break;

      case 4:
       yprintf(&pbuf1,"%s",pcheader);
       yprintf(&pbuf2,"\n\r%5dADCVAX",dbgka);
       for (i = 0; i < 18; i++) yprintf(&pbuf1," %6d",bmsspiall.cellreg[i]);
       yprintf(&pbuf1," %d",dbstat2/16);
        break;

      case 5: // Temperature (AUX reg)
       yprintf(&pbuf2,"\n\rAUX %6d %6d %6d",bmsspiall.auxreg[0],bmsspiall.auxreg[ 1],bmsspiall.auxreg[ 2]);
       yprintf(&pbuf1," %6d %6d %6d",   bmsspiall.auxreg[3],bmsspiall.auxreg[ 4],bmsspiall.auxreg[ 5]);
       yprintf(&pbuf3," %6d %6d %6d",   bmsspiall.auxreg[6],bmsspiall.auxreg[ 7],bmsspiall.auxreg[ 8]);
       yprintf(&pbuf2," %6d %6d %6d %d",bmsspiall.auxreg[9],bmsspiall.auxreg[10],bmsspiall.auxreg[11], dbstat2/16);

       extern uint32_t dbgaux;
       yprintf(&pbuf1," %d",dbgaux);

      bms_items_extract_statreg();
      yprintf(&pbuf3,"\n\r%5d SC-sumcells:%6.2fv ITMP-internal-temp:%5.1fC VA-analog:%6.3fv VD-digital:%6.3fv",dbgka,
          extractstatreg.sc, extractstatreg.itmp,
          extractstatreg.va, extractstatreg.vd  );

      bms_items_therm_temps(); // Convert thermistor readings to temperature (deg C)
      extern float fanrpm;
      yprintf(&pbuf2,"\n\rTEMP:%5.1f %5.1f %5.1f fanspeed: %d fanrpm: %0.3f",
          bqfunction.lc.thermcal[0].temp,
          bqfunction.lc.thermcal[1].temp,
          bqfunction.lc.thermcal[2].temp, 
          bqfunction.fanspeed, fanrpm);

      float cstmp = bms_items_current_sense(); // Calibrate current sense readings
      float cstmphall = bms_items_current_sense_Hall(); // Calibrate current sense readings
      yprintf(&pbuf1,"\n\rCURRENT LINK: %5.1f CURRENT_HALL: %5.1f", cstmp,cstmphall);
        break;

      default:
        yprintf(&pbuf2,"\n\r%d %5d BOGUS",dbgka, mctr);
        break;
      }
    }
#endif    

#if 1
    /* Update FAN control. (4/sec) */
    bms_items_therm_temps(); // Convert thermistor readings to temperature (deg C)
    fanop();
#endif

#if 0
/* Check WAKE */


#endif

/* Testing discharge FET bits. */
#ifdef TEST_WALK_DISCHARGE_FET_BITS // See main.h
  if (dischgfet_ctr++ > 3)
  {
    yprintf(&pbuf1,"\n\r\t\t\t\t\t\t### TEST: WALK DISCHARGE FET #%02u %u\n\r",(dischgfet+1),dbgcancommloop-dbgcancommloop_prev);
    dischgfet_ctr = 0;
    dbgcancommloop_prev = dbgcancommloop;
  }
#else
    /* ========> Cell balance & control. <========*/
    uint32_t dcc = extractconfigreg.dcc;
    char cline[LSPC*18+2];

    /* Check cell balance. */
    uint8_t ret8 = bq_items(); 
    if (ret8 == 2)
    { // Here a cell balance update was completed
      bms_items_extract_configreg();
extern uint8_t dbgf;
//extern struct BMSREQ_Q  bmstask_q_readbms;
//      yprintf(&pbuf1,"\n\r    %05X   ",bmstask_q_readbms.setfets);
//      for (i=0; i < 18; i++) yprintf(&pbuf2,"%4d",(1+i));
      yprintf(&pbuf1,"%s",pcheader);

int32_t csum = 0;
      yprintf(&pbuf2,"\n\rJcellv[i]: ");
      for (i = 0; i < 18; ++i)
      {
        csum += bqfunction.cellv[i];
        yprintf(&pbuf2," %6.0f",bqfunction.cellv[i]);
      }
      yprintf(&pbuf1," %d",csum);

#if 0 // Display cell registers after CLRCELL command
extern uint16_t clrregs[18];  
      yprintf(&pbuf2,"\n\rCLRCELL  : ");
      for (i = 0; i < 18; ++i)
      {
        yprintf(&pbuf1," %6.0d",clrregs[i]);
      }    
#endif
      // Line with FETs turned ON
      yprintf(&pbuf2,"\n\r%5d %02d FETS    ",fctr++,dbgf+1);
      memset(cline,' ',(LSPC*18));
      // Build a nice ASCII line whilst previous line prints
      for (i=0; i < 18; i++)
      {
        if ((dcc & (1<<i)) != 0)
          cline[i*LSPC] = '#'; // ON
        else
          cline[i*LSPC] = '.'; // OFF
      }
      cline[18*LSPC] = 0; // Output line
      yprintf(&pbuf1,"%s",cline); 


      // Line with cells tripped (over max) and trip sequence (0 to max H)
      yprintf(&pbuf2,"\n\r%5d %02d TRIPPED ",fctr,dbgf+1);
      if(bqfunction.celltrip == 0)
      { // Reset display line
        for (i = 0; i < 18; i++) tripline[i*LSPC] = '.';
        idxtripcode = 0;
        celltrip_prev = 0;
      }

      // tmptime is from last boot or switch from discharge to charge
      uint32_t tmptime = (ticks_secs - celltrip_time_offset);

      // Check for any changes in tripped cells
      uint32_t ttx = bqfunction.celltrip ^ celltrip_prev;
      if (ttx != 0)
      {
        if (idxtripcode >= 18) morse_trap(333);
        for (i=0; i < 18; i++)
        {
          if ((ttx & (1<<i)) != 0)
          { // Cell trip
              tripline[i*LSPC] = *(ptripcode+idxtripcode);
          } 
        }
        idxtripcode += 1;
        celltrip_prev = bqfunction.celltrip;
      }
      yprintf(&pbuf1,"%s",tripline);
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

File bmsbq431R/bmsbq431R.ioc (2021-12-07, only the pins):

Mcu.UserName=STM32L431RBTx
PA0.GPIO_Label=OPAMP-INP
PA0.Signal=SharedAnalog_PA0
PA1.GPIO_Label=OPAMP-INM
PA1.Signal=SharedAnalog_PA1
PA10.Signal=USART1_RX
PA11.Signal=TIM1_BKIN2_COMP1
PA2.Signal=COMP2_OUT
PA3.GPIO_Label=OPAMP_OUT
PA3.Signal=SharedAnalog_PA3
PA4.GPIO_Label=dc-dc-15V
PA4.Signal=SharedAnalog_PA4
PA5.Signal=S_TIM2_CH1
PA6.Signal=TIM1_BKIN_COMP2
PA7.GPIO_Label=HV-div1
PA7.Signal=SharedAnalog_PA7
PA8.Signal=S_TIM1_CH1
PA9.Signal=USART1_TX
PB0.GPIO_Label=LED_RED
PB0.Signal=GPIO_Output
PB1.GPIO_Label=LED_GRN
PB1.Signal=GPIO_Output
PB10.GPIO_Label=FAN-TACH
PB10.Signal=S_TIM2_CH3
PB12.GPIO_Label=PADxx
PB12.Signal=GPIO_Output
PB13.Signal=I2C2_SCL
PB14.Signal=I2C2_SDA
PB15.GPIO_Label=PAD7
PB15.Signal=GPIO_Output
PB2.GPIO_Label=HV-div2
PB2.Signal=SharedAnalog_PB2
PB5.GPIO_Label=BQ-RST-SHUT
PB5.Signal=GPIO_Output
PB6.GPIO_Label=BQ-SCL
PB6.Signal=I2C1_SCL
PB7.GPIO_Label=BQ-SDA
PB7.Signal=I2C1_SDA
PB8.Signal=CAN1_RX
PB9.Signal=CAN1_TX
PC1.GPIO_Label=FET-CUR-RC
PC1.Signal=SharedAnalog_PC1
PC10.GPIO_Label=DUMP
PC10.Signal=GPIO_Output
PC11.GPIO_Label=HEATER_NOT
PC11.Signal=GPIO_Output
PC12.GPIO_Label=HEATER
PC12.Signal=GPIO_Output
PC13.Signal=RTC_OUT_ALARM
PC3.GPIO_Label=FET_CUR-A2
PC3.Signal=SharedAnalog_PC3
PC4.GPIO_Label=Therm-spare1
PC4.Signal=ADCx_IN13
PC5.GPIO_Label=Therm-spare2
PC5.Signal=ADCx_IN14
PC6.GPIO_Label=DUMP2
PC6.Signal=GPIO_Output
PC8.GPIO_Label=DUMP_NOT
PC8.Signal=GPIO_Output
PD2.GPIO_Label=BQ_LD
PD2.Signal=GPIO_Output

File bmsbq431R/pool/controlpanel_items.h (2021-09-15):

/******************************************************************************
* File Name          : ControlPanelState.h
* Date First Issued  : 10/10/2020
* Description        : Defines a data structure and payload description
*                      for the control panel state message
*******************************************************************************/

#ifndef __CONTROLPANELITEMS
#define __CONTROLPANELITEMS

#include <stdint.h>

/* Definition of payload values  */

// CL position payload location and scaling factor

// payload byte 0
#define CLPOS_BYTE            0  // u16 control lever position
#define CLPOS_SCL          0.5f  // each lsb equal 0.5%


// switch and pb inputs payload locations

// number of bits in the mask is width of the field
// ...BIT is the lsb in the ...BYTE

// payload[1]
#define SAFEACTIVE_BYTE    1  // Safe/Active switch
#define SAFEACTIVE_BIT     7
#define SAFEACTIVE_MASK    0x01

#define ARMED_BYTE         1  // Arm PB
#define ARMED_BIT          6
#define ARMED_MASK         0x01

#define RTRVPREP_BYTE      1  // Prep/Retrieve PB
#define RTRVPREP_BIT       5
#define RTRVPREP_MASK      0x01

#define ZEROTEN_BYTE       1  // Zero Tension PB
#define ZEROTEN_BIT        4
#define ZEROTEN_MASK       0x01

#define ZEROODOM_BYTE      1  // Zero Odometer PB
#define ZEROODOM_BIT       3
#define ZEROODOM_MASK      0x01

#define BRAKE_BYTE         1  // Brake (guarded) switch
#define BRAKE_BIT          2
#define BRAKE_MASK         0x01

#define GUILLOTINE_BYTE    1  // Guillotine (guarded) switch
#define GUILLOTINE_BIT     1
#define GUILLOTINE_MASK    0x01

#define EMERGENCY_BYTE     1  // Emergency (latching) PB   aka BIG RED BUTTON
#define EMERGENCY_BIT      0
#define EMERGENCY_MASK     0x01

// payload[2]
#define LWMODE_BYTE        2  // Level-Wind Mode switch (3 position) 
#define LWMODE_BIT         6
#define LWMODE_MASK        0x03  // 2 bit field

#define LWINDEX_BYTE       2  // optional Level-wind Index 
#define LWINDEX_BIT        5
#define LWINDEX_MASK       0x01

#define REVFWD_BYTE        2  // optional drum direction PB
#define REVFWD_BIT         4
#define REVFWD_MASK        0x01

#define RMTLCL_BYTE        2  // Remote/Local switch
#define RMTLCL_BIT         3
#define RMTLCL_MASK        0x01

#define ACTIVEDRUM_BYTE    2  // active drum rotary switch  
#define ACTIVEDRUM_BIT     0   
#define ACTIVEDRUM_MASK    0x07  // 3 bit field



// payload[3]
#define SPARE3_BYTE       3
#define SPARE3_BIT        7
#define SPARE3_MASK       0x01

#define OPDRUMS_BYTE       3  // array of spst switches, one for each drum         
#define OPDRUMS_BIT        0    
#define OPDRUMS_MASK       0x7F  // 7 bit field

// bit 0 is spare


/* outputs  */
// fill from right

// payload byte 7

#define SAFELED_BYTE       7
#define SAFELED_BIT        0
#define SAFELED_MASK       0x01

#define PREPLED_BYTE       7
#define PREPLED_BIT        1
#define PREPLED_MASK       0x01

#define ARMEDLED_BYTE      7
#define ARMEDLED_BIT       2
#define ARMEDLED_MASK      0x01

#define GRNDRTNLED_BYTE    7
#define GRNDRTNLED_BIT     3
#define GRNDRTNLED_MASK    0x01

#define RAMPLED_BYTE       7
#define RAMPLED_BIT        4
#define RAMPLED_MASK       0x1

#define CLIMBLED_BYTE      7
#define CLIMBLED_BIT       5
#define CLIMBLED_MASK      0x01

#define RECOVERYLED_BYTE   7
#define RECOVERYLED_BIT    6
#define RECOVERYLED_MASK   0x01

#define RETRIEVELED_BYTE   7
#define RETRIEVELED_BIT    7
#define RETRIEVELED_MASK   0x01

// payload byte 6

#define ABORTLED_BYTE      6
#define ABORTLED_BIT       0
#define ABORTLED_MASK      0x01

#define STOPLED_BYTE       6
#define STOPLED_BIT        1
#define STOPLED_MASK       0x01

#define ARMPBLED_BYTE      6
#define ARMPBLED_BIT       2
#define ARMPBLED_MASK      0x01

#define PREPRCRYPBLED_BYTE 6
#define PREPRCRYPBLED_BIT  3
#define PREPRCRYPBLED_MASK 0x01

/* Beeper likely to get its own CAN message
#define BEEPER_BYTE        6
#define BEEPER_BIT         4 
#define BEEPER_MASK        0x01  */



struct CONTROLPANELSTATE
{
   uint8_t init; // struct is initialized:1, updated:0 from CAN message   

   /* control lever  */
   float    clpos;   // control lever position (0.0 to 100.0 percent)

   /* input signals  */
   // general assumption is all are debounced by control panel function 
   // (if needed)
   uint8_t  safe_active;   // safe:0, active:1
   uint8_t  arm;         
   uint8_t  rtrv_prep;     // retrieve:0, prep: 1
   uint8_t  zero_tension;
   uint8_t  zero_odometer;
   uint8_t  brake;
   uint8_t  guillotine;
   uint8_t  emergency;  // normal:0, emergency:1
   uint8_t  mode;       // off, track center
   uint8_t  index;      // index the level-wind   

   // provisions for future expansions
   uint8_t  rev_fwd;       // reverse:0, forward:1 control lever action
   uint8_t  rmt_lcl;       // remote:0, local:1 operator control
   uint8_t  active_drum;   // 1-7, 0 might signify all if needed
   uint8_t  op_drums;      // operational drums, bit mapped
   

   /* output signals   */
   // state leds
   uint8_t  safe_led;
   uint8_t  prep_led;
   uint8_t  armed_led;
   uint8_t  grndrtn_led;
   uint8_t  ramp_led;
   uint8_t  climb_led;
   uint8_t  recovery_led;
   uint8_t  retrieve_led;
   uint8_t  abort_led;
   uint8_t  stop_led;

   // lighted push button leds
   uint8_t  arm_pb_led;
   uint8_t  prep_rcvry_led;

   // uint8_t  beeper;  // likely getting its own message
};

#endif

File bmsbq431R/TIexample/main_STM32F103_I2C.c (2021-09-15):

/* --COPYRIGHT--,BSD_EX
 * Copyright (c) 2021, Texas Instruments Incorporated
 * All rights reserved.
 *
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
 * *  Redistributions of source code must retain the above copyright
 *    notice, this list of conditions and the following disclaimer.
 *
 * *  Redistributions in binary form must reproduce the above copyright
 *    notice, this list of conditions and the following disclaimer in the
 *    documentation and/or other materials provided with the distribution.
 *
 * *  Neither the name of Texas Instruments Incorporated nor the names of
 *    its contributors may be used to endorse or promote products derived
 *    from this software without specific prior written permission.
 *
 * THIS SOFTWARE IS PROVIDED BY THE COPYRIGHT HOLDERS AND CONTRIBUTORS "AS IS"
 * AND ANY EXPRESS OR IMPLIED WARRANTIES, INCLUDING, BUT NOT LIMITED TO,
 * THE IMPLIED WARRANTIES OF MERCHANTABILITY AND FITNESS FOR A PARTICULAR
 * PURPOSE ARE DISCLAIMED. IN NO EVENT SHALL THE COPYRIGHT OWNER OR
 * CONTRIBUTORS BE LIABLE FOR ANY DIRECT, INDIRECT, INCIDENTAL, SPECIAL,
 * EXEMPLARY, OR CONSEQUENTIAL DAMAGES (INCLUDING, BUT NOT LIMITED TO,
 * PROCUREMENT OF SUBSTITUTE GOODS OR SERVICES; LOSS OF USE, DATA, OR PROFITS;
 * OR BUSINESS INTERRUPTION) HOWEVER CAUSED AND ON ANY THEORY OF LIABILITY,
 * WHETHER IN CONTRACT, STRICT LIABILITY, OR TORT (INCLUDING NEGLIGENCE OR
 * OTHERWISE) ARISING IN ANY WAY OUT OF THE USE OF THIS SOFTWARE,
 * EVEN IF ADVISED OF THE POSSIBILITY OF SUCH DAMAGE.
 * --/COPYRIGHT--*//* USER CODE BEGIN Header */
/**
  ******************************************************************************
  * @file           : main.c
  * @brief          : Main program body 
  * (Non-USER sections generated from STM32CubeMX software)
  ******************************************************************************
  * @attention
  *
  * <h2><center>&copy; Copyright (c) 2020 STMicroelectronics.
  * All rights reserved.</center></h2>
  *
  * This software component is licensed by ST under BSD 3-Clause license,
  * the "License"; You may not use this file except in compliance with the
  * License. You may obtain a copy of the License at:
  *                        opensource.org/licenses/BSD-3-Clause
  *
  ******************************************************************************
  */
//  BQ76952EVM demo code for STM32 NUCLEO-F103RB + BQ76952EVM 
//
//  Connection description: The I2C SCL and SDA pins are the only pin connections required between the
//  NUCLEO board and the BQ76952EVM for this demo code. Also a ground connection should be made between the 2 boards.
//  The ALERT, RST_SHUT, and DFETOFF pins are also configured on the MCU and can be used as shown.
//
//                                     /|\ /|\ 
//                   STM32             5k |
//                 -----------------    |  5k
//                |             PB8 |---+---|-- I2C Clock (SCL)
//                |                 |       |
//                |		        PB9 |-------+-- I2C Data (SDA)
//                |                 |
//     DFETOFF ---| PA8             |
//                |                 |
//   RST_SHUT  ---| PA9        		|--- Green LED
//                |                 |
//      ALERT  ---|	PA10            |
//                |                 |


/* Includes ------------------------------------------------------------------*/
#include "main.h"

/* USER CODE BEGIN Includes */
#include <stdio.h>
#include "BQ769x2Header.h"
/* USER CODE END Includes */
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

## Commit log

2020-05-02 initial load with scad file
    [battbox-sim.scad]
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2020-05-05 adding eagle files to be hacked
    [RxT6.brd, RxT6.sch]
2020-05-27 add initial eagle files from f405Rlongskinny board to two board scheme
    [bms.brd, bms.sch, chgr.brd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]
2020-06-24 start eagle bms layout work.
    [battbox-sim2.scad, bms.brd, bms.sch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]
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2020-07-01 updating files. work is on bmsR board pair
    [bms.brd, bms.sch, chgr.brd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]
2020-07-03 bmsbmsR and bmschgrR layouts complete and pass dcr, but need detailed review and tweaking
    [bms.brd, bms.sch, chgr.brd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]
2020-07-06 save work on bmsbmsR and bmschgrR boards.
    [bms.brd, bms.sch, chgr.brd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]
2020-07-07 save work and updates
    [bms.brd, bms.sch, chgr.brd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]
2020-07-09 update and save work on bms boards
    [bms.brd, bms.sch, chgr.brd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]
2020-07-11 save bmsbmsR and bmschgrR work. Added master reset line, and changed 0.1 rc from 0805 to 0603
    [bms.brd, bms.sch, chgr.brd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]
2020-07-11 save revisions and updates. Review still has not be done. Net, it is not ready.
    [chgr.brd, chgr.sch]
2020-07-14 Fixed big time error on bmschgrR where discharge resistor not connected correctly for the internal discharge selection. Added pushbutton header on bmsbmsR.
    [bms.brd, bms.sch, chgr.brd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]
2020-07-18 save eagle work on bmsbmsR and bmschgrR plus doc stuff
    [PYBJ6_test.ods]
2020-07-19 save work on bmsbmsR and bmschrgR plus begin some documentation. Not reviewed
    [bms.brd, bms.sch, chgr.brd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]
2020-07-22 save work on bmsbmsR bmschgrR and documentation
    [bms.brd, bms.sch, chgr.brd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]
2020-07-23 save work on pcbs
    [bms.brd, bms.sch, chgr.brd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]
2020-07-25 save work. Added on-board dump resistor to bmsbmsR
    [bms.brd, bms.sch]
2020-07-30 add battery module pixs
    [pinusage.ods]
2020-12-24 add new work on BQ76952 implementation
    [bmsbq.brd, bmsbq.sch, chgr.brd]
2020-12-28 backup work on bmsbmsBQ board sch and brd
    [bmsbq.brd, bmsbq.sch]
2021-01-01 save work on bmsbmsBQfff
    [bmsbq.brd, bmsbq.sch, fff.brd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]
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2021-01-04 save work on bmsbmsBQ
    [bmsbq.brd, bmsbq.sch]
2021-01-07 save layout work on bmsbmsBQ. First cut at layout completed, but tweaking and polygon arrangements needed. Schematic needs review. Current sensing and VBAT might be reconsidered.
    [bmsbq.brd, bmsbq.sch]
2021-01-07 bmsbmsBQ--added srp and srn current sense lines. Some rearrangement cleanup done.
    [bmsbq.brd, bmsbq.sch]
2021-01-11 save and backup work on bmsbmsBQ
    [bmsbq.brd, bmsbq.sch]
2021-01-17 changed CAN ISO1050 to ISO1042; added AM6G1215 isolated dc-dc converter option; text cleanups; AP7380-50Y for 5v regulators; LM7805T 5v regulator option
    [bmsbq.brd, bmsbq.sch]
2021-01-26 save work on bmsbmsBQ. Updating not complete
    [bmsbq.brd, bmsbq.sch]
2021-01-31 save work before major revision of IDC ribbon cable pin assignments for change from 18 to 16 cell bms. Change puts ribbon sequence in natural order for connection to battery module terminals
    [bmsbq.brd, bmsbq.sch]
2021-02-06 save and backup bmsbmsBQ design
    [bmsbq.brd, bmsbq.sch]
2021-02-07 save work on bmsbmsBQ design. Revised CAN and I2C1 pins. Review and clean up still required
    [bmsbq.brd, bmsbq.sch]
2021-02-10 save latest work on bmsbmsBQ
    [bmsbq.brd, bmsbq.sch]
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2021-02-11 save and backup minor changes. working on renumber bmsbmsbq pcb
    [bmsbq.brd, bmsbq.sch]
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2021-02-13 save and backup bmsbmsbq board work. thermistor revision
    [bmsbq.brd, bmsbq.sch]
2021-02-14 bmsbmsbq save and backup. 5v1 drives added i2c2 jic bus. 5v3 from bq reg2 drives 7400 for fet drive.
    [bmsbq.brd, bmsbq.sch]
2021-02-18 update bmsbmsbq eagle files for revised opampand comparator pins
    [bmsbq.brd, bmsbq.sch]
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2021-02-21 lost docs directory for some strange reason. Copied from backup
    [PYBJ6_test.ods, mini-dcdc-resistors.ods]
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2021-03-18 comments on docx and fix FET104 on bmsbmsBQ
    [bmsbq.brd, bmsbq.sch]
2021-03-26 save bmsbmsBQ eagle file updates. Fixed FET103 drain-source revesal. Added diode to OR dc-dc converter 15v to C16
    [bmsbq.brd, bmsbq.sch]
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2021-04-01 added missing gerber layer
2021-04-11 Changed thermistors from CHG, DSG to DCHG, DDSG. Added RC0/C100 in C0 line. Renamed solder pads
    [bmsbq.brd, bmsbq.sch]
2021-04-25 minor changes to silk screen and updated Gerbers
    [bmsbq.brd]
2021-05-08 update board to use C15 1uf, 100v electrolytic alternative to C9 cermaic cap that is currently not available
    [bmsbq.brd, bmsbq.sch]
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2021-09-20 Discovered congif update multiple times was resetting things. BREG is now showing 6v+. thermistors working, but need calibration.
    [BQTask.c, main.c]
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2021-10-20 bms1818 eagle routed w DRC OK. Begin updates learned from BQ board assembly. Save work before changes.
    [bms1818.brd, bms1818.sch]
2021-10-22 save and backup work. Updating BQ eagle and 1818 eagle with items learned in first BQ pcb layout. Not all items complete.
    [bms1818.brd, bms1818.sch]
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2021-10-24 added opamp for current sense and pin #2 on ribbon header no longer a 2nd gnd
    [bms1818.brd, bms1818.sch]
2021-10-24 cleaned up some erc errors and warnings
    [bms1818.brd, bms1818.sch]
2021-10-25 added bias to opamp current sense. Changed pwr on DRIVE pin to i/o to eliminate erc error.
    [bms1818.brd, bms1818.sch]
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2021-11-05 save and backup work. FET drive NAND changed to NOR. 3rd BQ was blown. bmsbmsBQ-v2 BAT pin powering revised.
    [BQ_adc_calibration.ods, bms1818.brd, bms1818.sch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]
2021-11-08 add missing files to git
    [adc_idx_v_struct.c, adcfastsum16.c, adcparams.c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]
2021-11-28 Replaced ISO1042 along with some minor sw changes to test for the gateway heartbeat msgs. Sedning receiving CAN msgs working.
    [BQTask.c, BQTask.h, CanCommTask.c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]
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2021-12-18 standardized mounting holes, but BQ V2 not completed
    [bms14921.brd, bms14921.sch, bms1818.brd]
2021-12-18 standardized holes on BQ-V2 board. 3.3v i2C headers had to be sacrificed
    [bmsbq.brd, bmsbq.sch]
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2022-01-02 fixed external FETs reversed on 14921 pcb. Other changes on it too. Save and backup work
    [adaptm-m.brd, adaptm-m.sch, bms14921.brd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]
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2022-01-06 14921 pcb updates. DUMP 3 pin, plus VOred pin added
    [bms14921.brd, bms14921.sch, rj45-2x5.brd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]
2022-01-08 mods to pcb 14921 to add 3.3 to 5v level shifters
    [adaptm-m.brd, bms14921.brd, bms14921.sch]
2022-01-09 revised 14921 pcb. eliminated SDO level shift, added EN via level shift. Used 74VL07 TSSOP14 for levelshifting
    [bms14921.brd, bms14921.sch]
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2022-03-17 Major revision of bms readout. SPI interrupt no longer used. TIM15 and ADC interrupts drive sequence.
    [adcbms.c, adcspi.c, main.c]
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2022-04-08 add missing files. something wrong with cell number 1 reading in this commit, but ok with older versions
    [BQTask.h, CanCommTask.c, adc_idx_v_struct.c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]
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2022-06-30 add missing files to bmsadbms1818
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2022-07-15 save and backup 1818 work. Found problem with 1st command requiring two tries.
    [bms_items.c, bmsspi.c, main.c]
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2022-07-20 STAT time issue fixed.
    [main.c]
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2022-07-25 save work. 1818 fan speed control added. cell 2 S pulldown resistor added to fix discharge problem. 1M only partial FET on, 100K solid on
    [BQTask.h, bms_items.c, bq_idx_v_struct.h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]
2022-07-26 fixed fetonoff.c for backwards heater and dump on-off sense. Still checking out hw and sw
    [chgr_items.c]
2022-08-01 save work. calibration of processor adcs in progress. internal temperature calculation not correct.
    [adc_idx_v_struct.c, adcparams.c, adcparams.h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]
2022-08-01 fixed internal temp computation. 3.3v Vcc and CAL1,2 is based on Vcc 3.0 in datasheet footnote.
    [adc_idx_v_struct.c, adcparamsinit.c, bmsspi.c]
2022-08-02 fixed fan tach. PB10 now uses EXTI15_10 interrupts. Discovered thermistor readings jump when temp gets to about 33 degC. Requires reset to get readings normal.
    [bms1818.ioc, main.c, main.h]
2022-08-02 Fixed GPIO thermistor jump problem. Readout of GPIO bits is logic level so a read-then-write operation can set the pulldown ON. Solution is to set the bits before all config reg writes.
    [bmsspi.c]
2022-08-02 add missing BMSTask
2022-08-03 changes to bmsspi.c for TIMSTATE_1 may have corrected the rare timeout trap.
    [BMSTask.h, bmsspi.c, main.c]
2022-08-04 save work. DMA1:CH1 flag for ADC1 in bmsspi.c fixed, but not something that would affect operation
    [bmsspi.c]
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2022-08-09 save work. Working on cell balancing which is not working
    [BQTask.h, bmsspi.c, bq_idx_v_struct.h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]
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2022-08-17 bmsbms1818-v2 update. Renumbered top and bottom. Swapped top and bottom for the two CC caps so that the top are all resistors and the bottom all caps.
    [bms1818.brd, bms1818.sch]
2022-08-18 save work on eagle files for 1818-v2. Renumbered, SDO via added. GPIO assignments NOT changed.
    [bms1818.brd, bms1818.sch]
2022-09-15 reset cmd fixed in CanCommTask
    [CanCommTask.c, bms1818.ioc, cancomm_items.c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]
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2023-01-08 rtc save restore fixed. chg and balancing work in progress
    [main.c]
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2023-02-25 add files for proxy pack pcb and 3D frame
    [proxy.brd, proxy.sch, proxy2.scad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]
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2023-03-23 Add bms1818 eagle files with correction of 8 pin CAN driver rx/tx in earlier versions. > Eliminate no external discharge fet option with 3 pin resistor configuration and added SMD discharge resistor 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
    [bms1818.brd, bms1818.sch]
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2023-07-23 updates chasing bmsspi bug
    [CanCommTask.c, bmsspi.c, main.c]
2023-07-25 updates for chasing bogus readings bug
    [BMSTask.h, bmsspi.c, main.c]
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2023-09-13 fixed saving restoring charge-discharge mode problem where CAN msg command 31 made it look like it had received a command to go into charge mode
    [CanCommTask.c, main.c]
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2024-07-06 added -e option to bin/bash scripts for .cc sequence so as to bombout on any script error.
    [cancomm_items.c, cancomm_items.h]
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2024-07-29 update fan bug where command counter not incrementing in fanop.c
    [cancomm_items.c]
2024-09-04 Update params for current sense damaged units
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2025-04-08 Fix duplicate Start CAN in Task.c and CanCommTask.c
    [CanCommTask.c]
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2026-02-12 Fix module volts scaling that had divisor of 1000 instead of 100 for gsm boards
2026-02-17 add ccskipmm to skip compile
    [cancomm_items.c]
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

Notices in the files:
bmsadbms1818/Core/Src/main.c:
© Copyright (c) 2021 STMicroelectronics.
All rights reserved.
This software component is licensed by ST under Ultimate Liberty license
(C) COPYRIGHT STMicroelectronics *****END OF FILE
